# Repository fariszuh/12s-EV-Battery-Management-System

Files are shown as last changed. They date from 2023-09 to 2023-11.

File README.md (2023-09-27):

# 12s Battery Management System Research Project

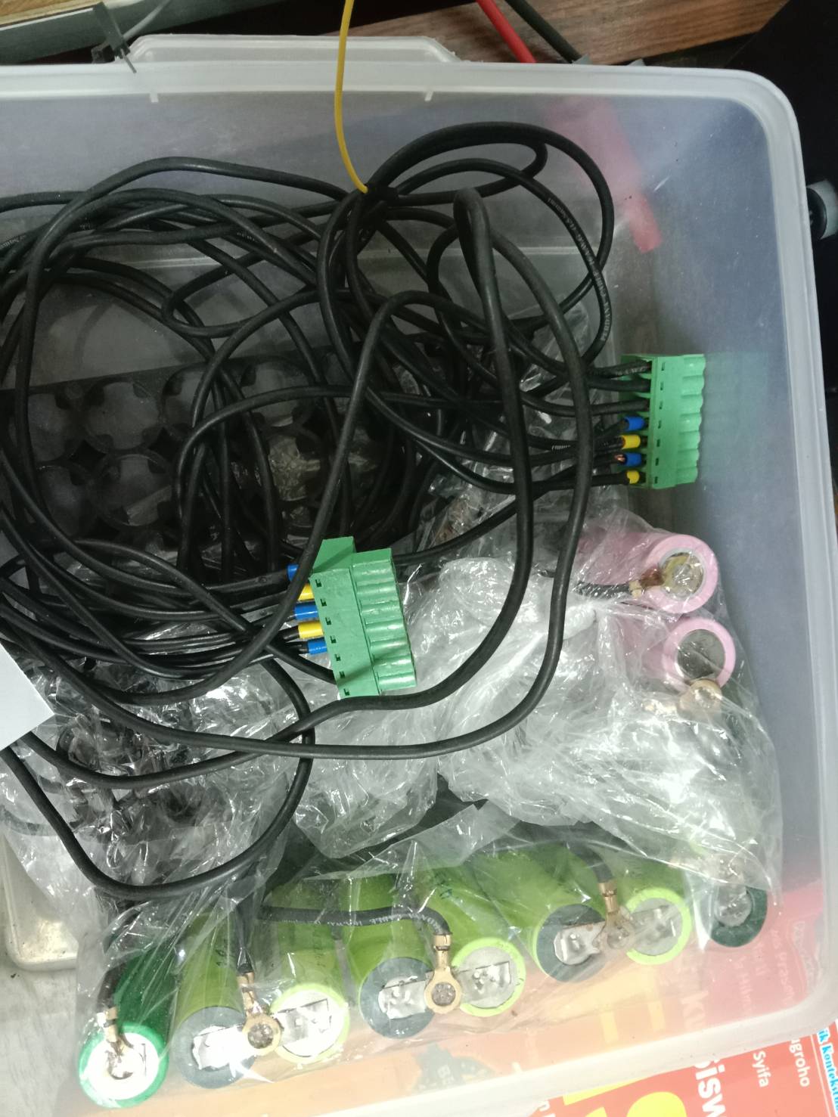
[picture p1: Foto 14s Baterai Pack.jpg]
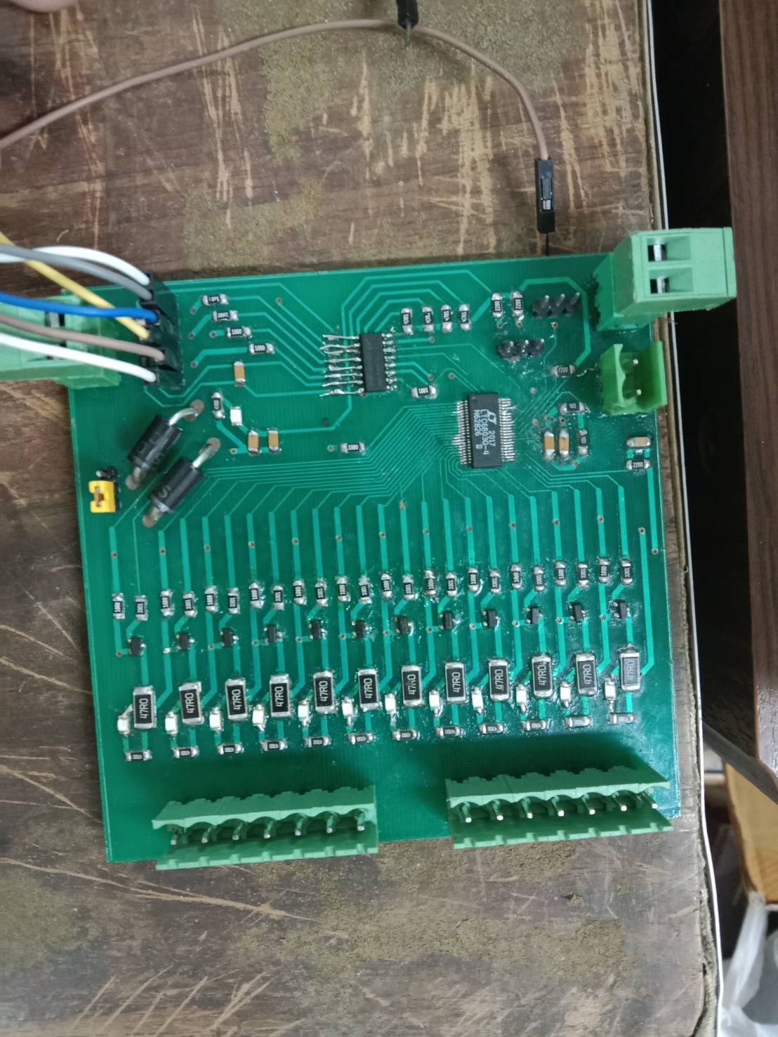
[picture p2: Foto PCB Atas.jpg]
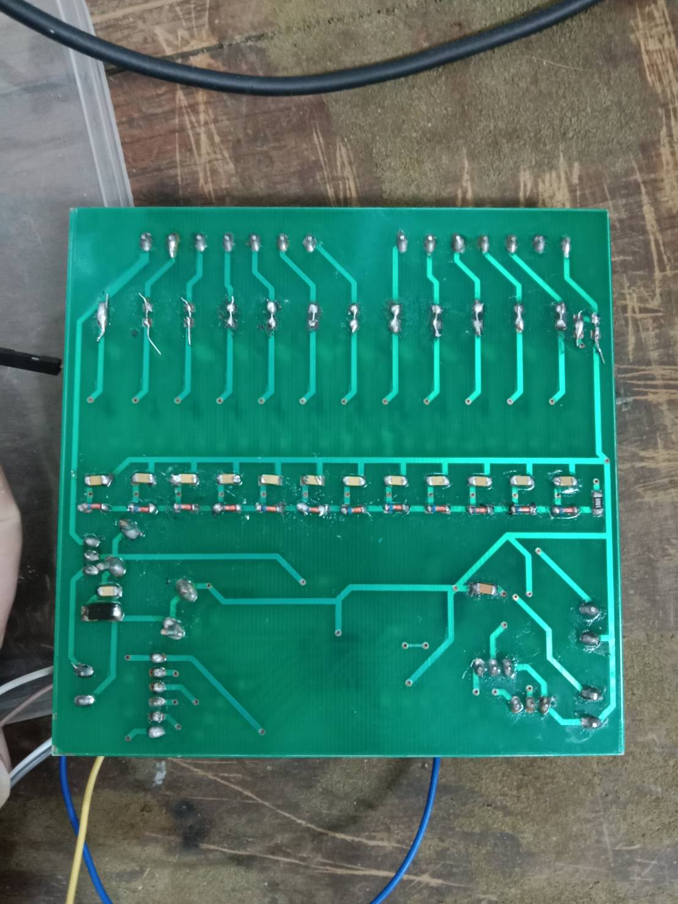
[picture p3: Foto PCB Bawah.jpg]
  

## Introduction
*This repo used to collaborative work on BMS project*
This project initiated by Anargya Third Generation Electric Manager Plan, Abyqa on 2021.
He suggested us (4th Electric Generation) to create our independent BMS. 
In the next year, 2022, We (Rafli as Electric Manager, Faris as Head of Low Voltage Subdiv., Lazu as Head of High Voltage Subdiv) proposed new design according to last Molina BMS.
The schematics design is located in /Single Board 12s directory. Note: use the latest version _v<number>.sch

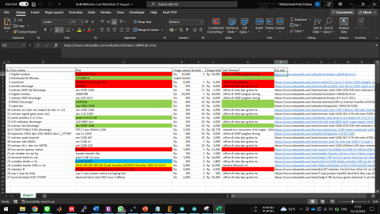
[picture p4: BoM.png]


## My Last Progress
Last progress was programming with Arduino UNO (Faris, Gagas). 
The code located inside /Code directory.

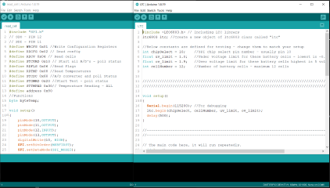
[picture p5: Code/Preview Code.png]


## Challenge
PCB had been assembly with the components, but the SPI communication to LTC's register still couldn't be read. 
This problem probably caused by thin route layer between component pin to LTC. You can re-route Eagle board file and print again.
Suggestion: use thicker path and more than 2 layer.

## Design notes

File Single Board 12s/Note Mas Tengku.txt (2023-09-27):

layer 1/top: S 
layer 2/green: V+ltc
layer 3/yellow: GND 0V
layer 4/bottom: C

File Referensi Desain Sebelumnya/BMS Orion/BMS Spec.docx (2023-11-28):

### 1.1.1 BMS Specifications

We are using a orion BMS made by Ewert Energy System, inc in USA. The main features of our BMS are:

1. Able to monitoring every cell voltage
2. Easily programmable and upgradeable on the field
3. Can enforce min. and max. cell voltages, max current limits, & temperature limits
4. Intelligently balancing each cell
5. Continously monitors state-of-charge and retains data about battery history
6. Integration with 3rd party smartphone apps (Torque, EngineLink)
7. Thermal Management & Voltage Protection
8. CANBUS Interfaces, OBD-II Support (support many scan tools) and Automotive Noise Immunity.

And for the safety of the Orion BMS are:

1. Isolation fault detection
2. Calculate the state of health, charge current limit, discharge current limit and Internal resistance of each cell
3. High immunity to EMI and other noise
4. High accuracy cell voltage measurement
5. On/Off outputs for controlling charge and discharge
6. 0-5V analog outputs for gradual current reduction (improves usable range of battery) and,
7. Thermal management controls for battery cooling/heating.

We using 1 BMS added with arduino uno to control and monitor voltage, current, state of health and temperature from 72 cell with 3.6 volt each cell and max. Voltage up to 260 volt. The Orion BMS will attach in the accumulator container and also added with (galvanic isolation between GLV and TS is we use Nomex paper at each end of connector to make sure the high voltage and low voltage doesn’t touch each other)(masih sama atau ngga?)

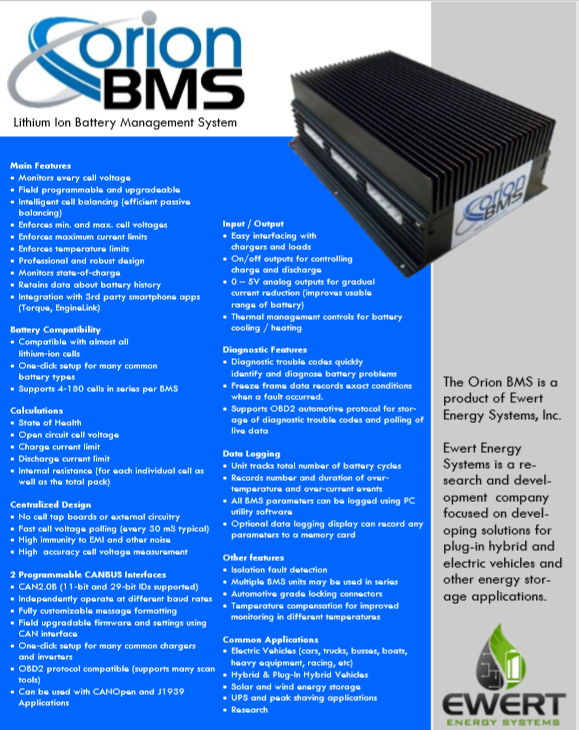
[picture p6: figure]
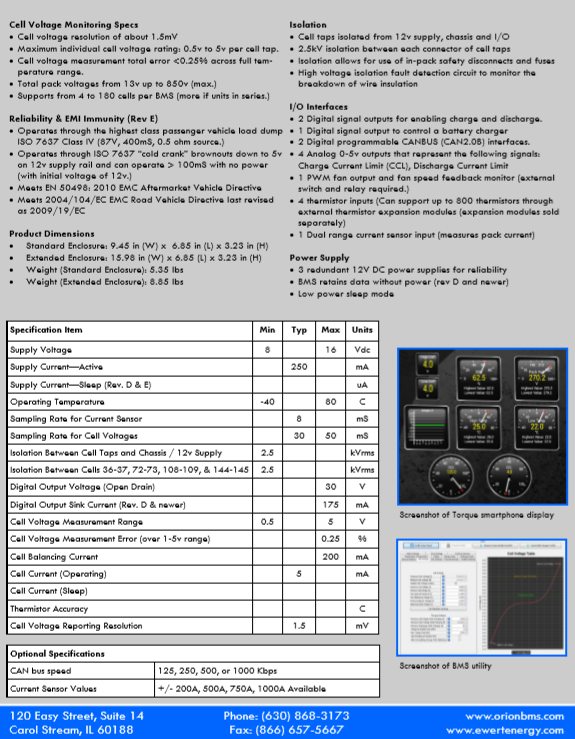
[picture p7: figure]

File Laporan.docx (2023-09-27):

RENEWABLE ENERGY

TRANSPORTATION – EV

BATTERY PACK – BMS

Terjadinya imbalance pada sel baterai merupakan hal yang umum terjadi dan dapat diakibatkan oleh sebab internal dan eksternal. Faktor internal meliputi variasi saat manufaktur, seperti volume bahan kimia baterai, internal impedance, dan laju self-discharge. Faktor eksternal dapat disebabkan oleh perbedaan suhu di dalam battery pack dan perbedaan laju

BMS

BATTERY PACK

METHOD BALANCING

CONSTRUCTION

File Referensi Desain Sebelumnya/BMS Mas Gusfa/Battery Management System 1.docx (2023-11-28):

## 1.1 Battery Management System (BMS)

### 1.1.1 Desain Battery Management System (BMS)

Perancangan desain PCB BMS menggunakan software Eagle 6.2.0. Sebelum melakukan desain PCB BMS secara keseluruhan, diperlukan schematic masing-masing modul pendukung dan melakukan pengujian pada modul tersebut. Hal ini dilakukan untuk mengurangi kegagalan PCB setelah dilakukan pencetakan. Selanjutnya, seluruh modul digambar jadi satu rangkaian. Berikut desain skematik BMSini :

#### 1.1.1.1 Modul Controller

Modul kontroler menggunakan mikrokontroler berbasis ARM dengan tipe STM32F405RGT6. Mikrokontroler ini dilengkapi dengan fitur Real Time Operating System (RT-OS) yang memungkinkan melakukan multi tasking dengan handing timer mencapai 168Mhz. STM32F405RGT6memiliki fitur yang sesuai dengan kebutuhan BMS ini. Berikut beberapa fitur yang dimiliki Mikrokontroler ini untuk menunjang fungsi BMS :

- Frekuensi kerja micro ini mencapai 168 Mhz sehingga sangat dimungkinkan untuk melakukan pengukuran dengan sample data yang cukup banyak. Selain itu, BMS akan semakin responsif dan akurat dalam melakukan balancing.
- Analog to Digital Converter (ADC) mencapai 12 bit, sehingga mampu melakukan pengukuran dengan resolusi yang sangat kecil.
- Dilengkapi 2 Peripheral CAN yang dapat digunakan sebagai protocol komunikasi antar device.
- Terdapat fasilitas peripheral SPI yang digunakan sebagai komunikasi dengan LTC6803-4.
- Terdapat fasilitas peripheral USART yang digunakan sebagai komunikasi dengan PC atau Laptop untuk keperluan user interface.

Skematik pada Gambar 7.13merupakan rangkaian komponen yang tersambung langsung pada pin utama Mikrokontroller STM32F405RGT6. Pada pin power supply, masing-masing disertai capacitor 100nF sebagai stabilisator tegangan sehingga Mikrokontroler dapat beroperasi dengan stabil. Berikut minimum system STM32F405RGT6 :

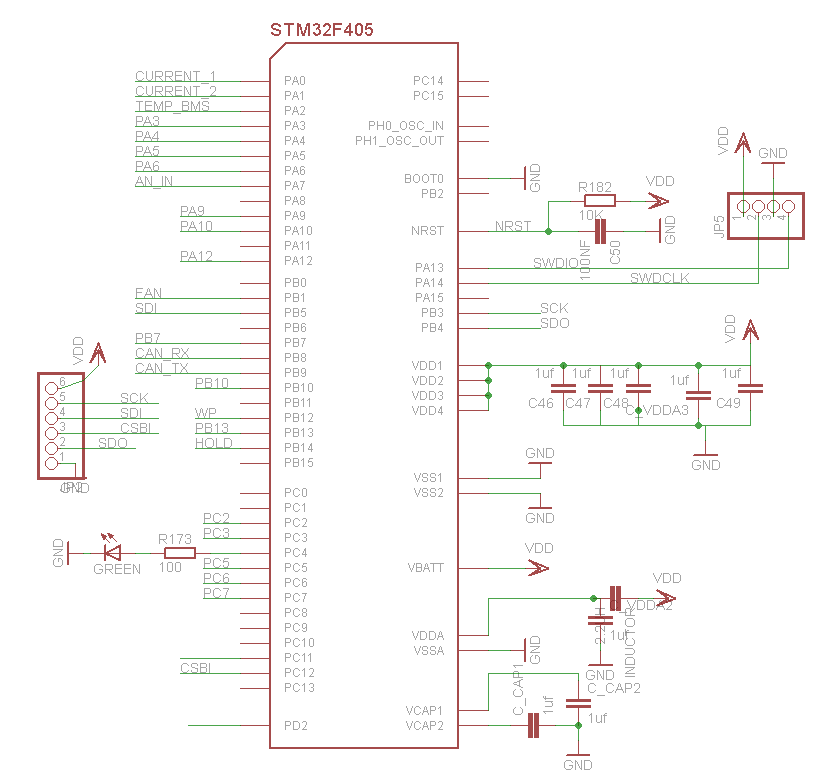
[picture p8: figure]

Gambar ‎7.13. Minimum System STM32F405RGT6

#### 1.1.1.2 Modul Voltage Regulator

Rangkaian voltage regulator ini berfungsi sebagai step down DC-DC Converter yaitu merubah tegangan input 7-36 Volt DC menjadi 5 volt DC. Voltage regulator yang digunakan adalah modul OKI-78SR. Sedangkan untuk mensuplai Mikrocontroler STM32F405RGT6 diperlukan tegangan dengan level 3.3 Volt, sehingga diperlukan Voltage Regulator dengan tipe LD1117DT33CTR. Kapasitor yang terpasang pada input dan output regulator digunakan sebagai stabilisator. Rangkaian voltage regulator ditunjukkan padaGambar 7.14.

Gambar ‎7.14. Voltage Regulator

#### 1.1.1.3 Modul Pengukur Tegangan per Cell

Tegangan per cell baterai dideteksi dengan metode Delta Sigma Analog to Digital Converter 12 bit. Masing-masing ground baterai terisolasi dengan prinsip Galvanic Isolation. Prinsip kerja Delta Sigma ADC adalah merubah data Analog tegangan cell menjadi data digital dengan referensi selisih tegangan per cell tersebut, sehingga akan diperoleh ketelitian yang sangat baik. Melalui prinsip ini tegangan yang terukur dapat memiliki ketelitian 3 angka dibelakang koma, lebih tepatnya memiliki ketelitian 1.5 mV dan 0.25% Total Error Measurement. BMS ini menggunakan IC LTC6803-4 untuk memonitoring tegangan baterai per cell. IC ini dapat digunakan untuk melakukan pengukuran tegangan 12 cell baterai dengan maksimal tegangan per cell 5V, sehingga dapat digunakan untuk aplikasi BMS Lithium Ion. IC ini juga dilengkapi dengan fasilitas Addressable Serial Interface sebanyak 4 bit (16 address). Sehingga sebanyak 16 IC dapat digunakan sekaligus untuk melakukan monitoring tegangan sebanyak 192 cell baterai. Berikut rangkaian LTC6803-4 :

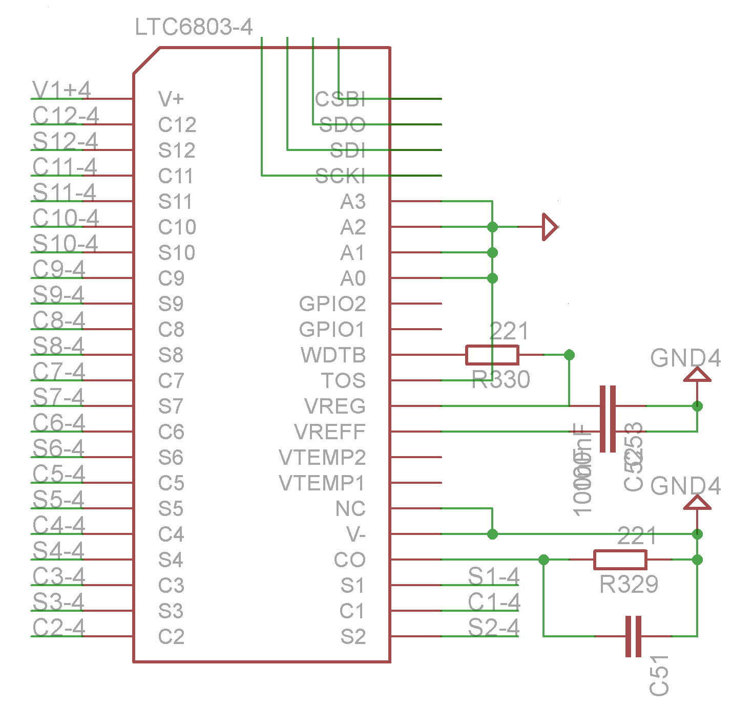
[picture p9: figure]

Gambar ‎7.15. Modul LTC Pengukur Tegangan per Cell

#### 1.1.1.4 Modul Balancing

BMS ini menggunakan Passive Balancing dengan switching Mosfet P channel berdasarkan tegangan per cell. Metode ini dipakai karena lebih simple apabila dibandingkan dengan Active Balancing. Skema passive balancing bms ini dapat dilihat pada gambar berikut :

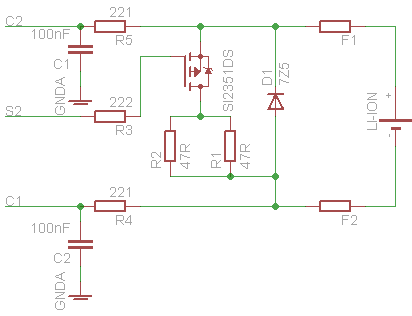
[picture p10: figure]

Gambar ‎7.16. Rangkaian cell passive balancing menggunakan MOSFET

Rangkaian tersebut merupakan rangkaian passive balancing untuk 1 cell baterai. F1 dan F2 merupakan fuse yang digunakan sebagai pengaman circuit, apabila terjadi kegagalan pada BMS tidak akan merusak baterai. D1 merupakan diode Zener 7.5 Volt, diode ini sebagai pengaman ADC pada LTC6803-4. Tegangan yang diizinkan masuk pada pin C1 maupun C2 maksimal adalah 7.5 Volt (meskipun input melebihi 7.5 Volt). Apabila terjadi kesalahan pemasangan wiring (misalkan menyebabkan delta cell voltage nya melebihi 7.5 Volt) tidak akan merusak LTC6803-4. R5, R4 dan C1, C2 merupakan RC Low Pass Filter yang berfungsi untuk memperkecil error pengukuran pada LTC6803-4. R1 dan R2 merupakan Resistor bypass yang berfungsi membuang kapasitas cell baterai yang berlebih dalam bentuk panas. MOSFET yang digunakan adalah Si2351DS, merupakan Mosfet P-Channel yang memiliki kemampuan switching hingga 2 A 20 volt (datasheet Si2351DS). MOSFET ini akan diaktifkan oleh LTC6803-4 sesuai perintah dari Mikrokontroler.

#### 1.1.1.5 Modul Opto Isolator

Opto Isolator digunakan untuk mengisolasi 2 level tegangan yang berbeda sehingga tidak saling terhubung namun dapat berinteraksi. Isolasi 2 level tegangan yang dimaksud adalah SCK, SDI, SDO dan CSBI antara Microcontroller dengan LTC. Digital Isolator yang digunakan adalah Si8441BB-D-IS1 yang terdiri dariQuad Channel Digital Isolator. Penggunaan Opto isolator ini sangat cocok karena sesuai dengan spesifikasi dimana isolator ini memiliki kecepatan operasi sebesar 150Mbps.

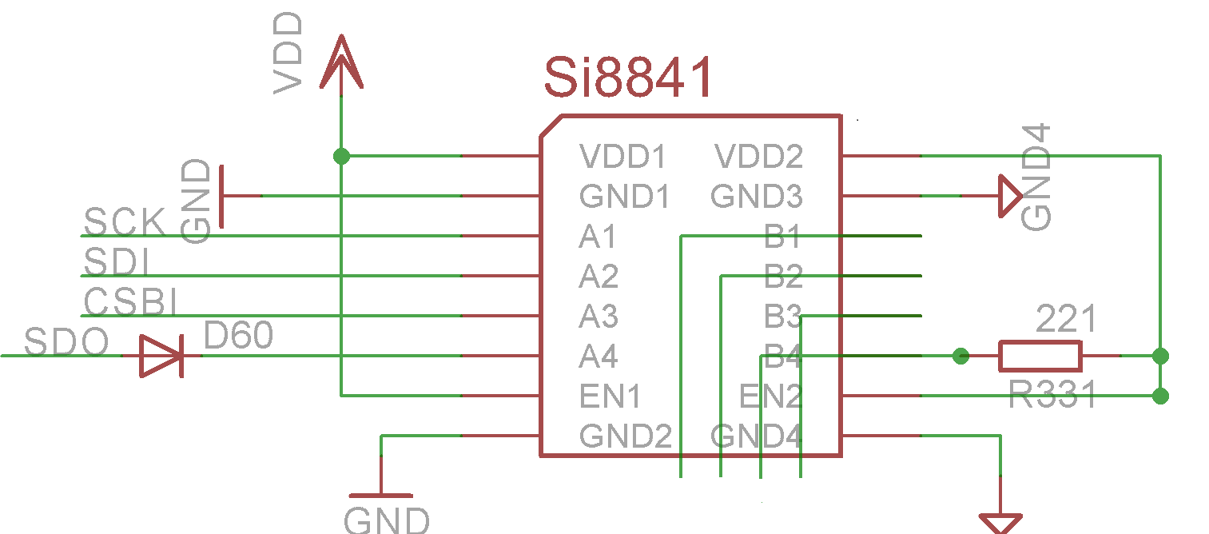
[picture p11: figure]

Gambar ‎7.17. Modul Opto Isolator

#### 1.1.1.6 Modul Pengukur Temperature

BMS ini menggunakan Thermistor NTC 100 K untuk mendeteksi temperatur baik boards BMS maupun baterai pack. Perubahan temperatur dapat dikonversi menjadi perubahan hambatan oleh thermistor ini. Data yang dimasukkan pada pin ADC mikrokontroler adalah data analog tegangan, sehingga nilai hambatan pada Thermistor perlu dirubah menjadi data tegangan dengan menggunakan Voltage Devider. Berikut rangkaian pengkondisian sinyal thermistor :

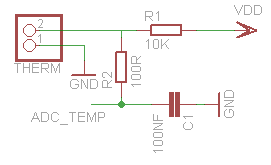
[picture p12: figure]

Gambar ‎7.18. Rangkaian pengkondisian sinyal thermistor

R1 merupakan hambatan senilai 10KΩ yang berfungsi sebagai pembagi tegangan terhadap hambatan thermistor. R2 bernilai 100Ω dan C1 bernilai 100nF merupakan rangkaian RC Low Pass Filter. Temperatur maksimum yang didesain pada BMS ini adalah 100oC sehingga BMS ini memiliki resolusi temperatur 1oC.

#### 1.1.1.7 Modul MRAM

Magneto Resistive Random Access Memory (MRAM) merupakan device penyimpanan menggunakan prinsip electromagnet sehingga memiliki fitur Unlimited Write dan Read Data. External memori ini digunakan untuk memfasilitasi fungsi perhitungan kapasitas baterai yang diharuskan mengakses memori setiap 100ms. Internal Flash Microcontroller hanya digunakan sebagai memory data static, STM32F4 dapat melakukan re-write Flash sebanyak 10.000-1jt kali sehingga diperlukan MRAM ini. MRAM yang digunakan adalah tipe MR25H256CDC. MRAM menggunakan komunikasi SPI dan pada desain BMS ini memakai SPI2 karena SPI1 sudah dipakai untuk LTC.

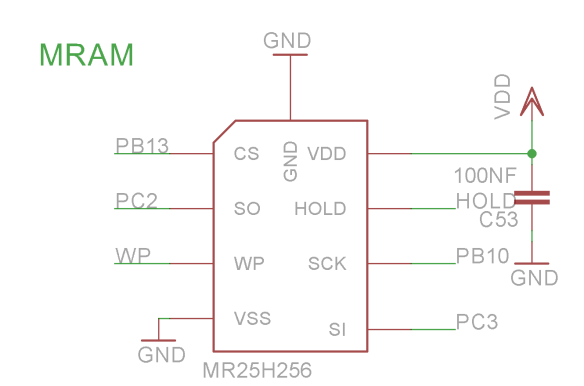
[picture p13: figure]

Gambar ‎7.19. Modul MRAM

#### 1.1.1.8 Modul Komunikasi CAN

BMS ini menggunakan komunikasi data CAN (Controller Area Network), yaitu komunikasi dengan topologi Bus. IC yang digunakan adalah SN65HVD230DR, komunikasi CAN merupakan standar otomotif yang memberikan fitur kecepatan pengiriman data hingga 1 Mbps dengan panjang jaringan hingga 50 m. Pada tahun 1993 Organisasi Internasional untuk Standardisasi merilis standar ISO 11898 yang kemudian direstrukturisasi menjadi dua bagian; ISO 11898-1 yang mencakup lapisan data link, dan ISO 11898-2 yang meliputi lapisan fisik untuk kecepatan tinggi. ISO 11898 - 3 dirilis kemudian yang mencakup lapisan fisik untuk kecepatan rendah. Perangkat yang terhubung dengan jaringan CAN biasanya sensor, aktuator, dan perangkat kontrol lainnya. Komunikasi ini dipakai karena data yang ditransfer lebih tahan terhadap noise. Data yang ditransfer akan direpresentasikan berupa nilai logik (0 dan 1) dimana kombinasi nilai logik ini dapat dibaca melalui differensial tegangan pada pin CAN High dan CAN Low. Selain itu, perbedaan tegangan pada pin CAN High dan CAN Low bisa lebih dari 5 volt sehingga lebih tahan terhadap noise. Berikut rangkaian CAN BMS ini :

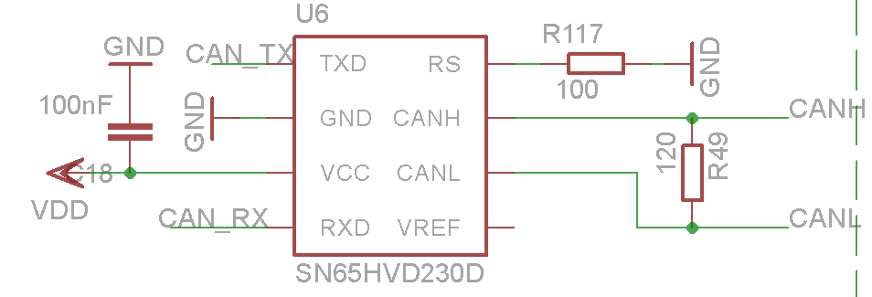
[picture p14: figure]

Gambar ‎7.20. Rangkaian CAN communication module

### 1.1.2 Desain Firmware

Firmware merupakan program dengan menggunakan bahasa C untuk dimasukkan pada Microcontroller. Sebelum membuat program, perlu dilakukan identifikasi peripheral-peripheral apa saja yang diperlukan dalam membuat BMS. BMS ini akan memerlukan peripheral sebagai berikut :

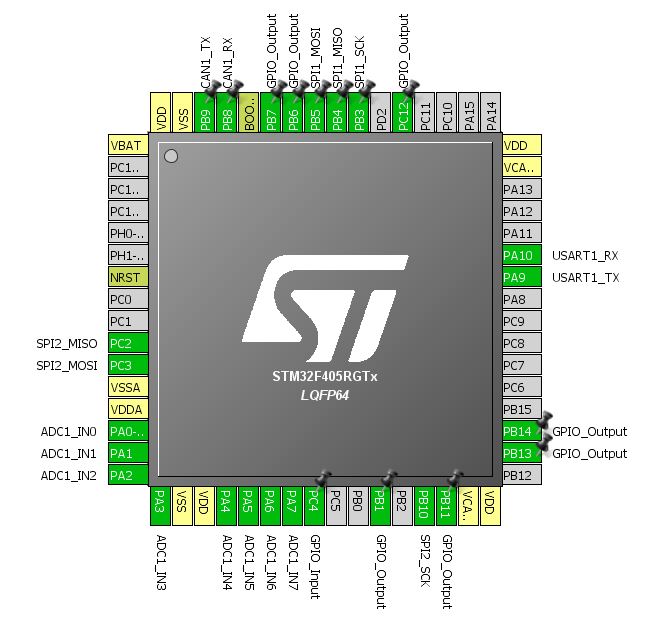
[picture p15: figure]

Gambar ‎7.22. Pin input dan output BMS

Peripheral STM32F405RGT6 yang digunakan untuk memfasilitasi seluruh fungsi dari BMS ini adalah :

#### 1.1.2.1 Serial Peripheral Interface (SPI)

SPI adalah salah satu protocol komunikasi serial shyncronous yang di-develop oleh Motorola. Dalam koneksi SPI, device yang terhubung satu sama lain akan bersifat Full Duplex, yaitu ada device yang bertindak sebagai Master dan Slave. Device yang menggunakan SPI dalam BMS ini adalah LTC6803-4 dan MRAM tipe MR25H256CDC sedangkan STM32F405RGT6 sebagai SPI Master. LTC6803-4 dihandle oleh SPI1 sedangkan MRAM dihandle oleh SPI2 dengan setting parameter sebagai berikut :

- CPHA = 1 dan CPOL = 1
- SPI data size 8 bit
- 1MHz Serial Interface (SPI_BaudRatePrescaler_64)
- Most Significant Bit (MSB) First
- SPI aktif ketika CSBI low

#### 1.1.2.2 Controller Area Network (CAN)

Peripheral CAN ini memiliki spesifikasi sebagai berikut :

- Extended CAN (CAN Specification 2.0 B) memiliki 29 bit identifier.
- CAN Mode Normal
- Kecepatan komunikasi CAN bus yang digunakan 500Kbps, sehingga konfigurasi pada STM32F405RGT6 adalah :

CAN_InitStructure.CAN_BS1 = CAN_BS1_8tq;

CAN_InitStructure.CAN_BS2 = CAN_BS2_5tq;

CAN_InitStructure.CAN_Prescaler = 6;

CAN_Init(CANx, &CAN_InitStructure);

- 1 ID memiliki 8 Byte data dan 1 byte terdiri dari 8 bit data, sehingga semua data dirubah menjadi data 8 bit. Contoh mengonversi data 16 bit menjadi 2 paket data masing-masing 8 bit :

uint8_t data1, data2; // tipe data 8 bit

uint16_t voltageLowest; // tipe data 16 bit

data1= voltageLowest>>8;

data2 = voltageLowest&0x00FF;

sedangkan untuk menggabungkan 2 data 8 bit menjadi data 16 bit adalah sebagai berikut :

uint8_t data1, data2;

uint16_t voltageLowest;

voltageLowest= (data1<<8)|(data2);

#### 1.1.2.3 Analog to Digital Converter (ADC)

ADC adalah pengubah input analog menjadi kode-kode digital. Data analog yang akan diproses pada Controller ini adalah output sensor arus, output signal conditioning sensor temperatur, output sensor tegangan. STM32F405RGT6 memiliki keunggulan yaitu ADC 12 bit data, sehingga memiliki resolusi pengukuran yang baik dibandingkan dengan microcontroller lain. Selain itu ADC juga dapat menggunakan Direct Memory Access (DMA) sehingga memungkinkan pengambilan sample data secara optimal. BMS ini menggunakan sample data ADC sebanyak 300 data ADC setiap 1 ms dan data tersebut diakses setiap 100ms untuk dilakukan perhitungan Coulomb. Data setiap 1 ms tersebut diakumulasikan selama 100ms kemudian dihitung rata-rata ADC tersebut. Hasil rata-rata data ADC tersebut yang digunakan sebagai perhitungan Coulomb. Sehingga data ADC yang digunakan memiliki nilai yang tepat. Untuk menghandle proses perhitungan setiap 100ms digunakan Timer 2. Konversi nilai Digital yang diperoleh akan merepresentasikan kondisi fisik yang disensor.

#### 1.1.2.4 Universal Synchronous Asynchronous Receiver Transmitter (USART)

USART digunakan untuk komunikasi data antara STM32F405RGT6 dengan Komputer, sehingga Komputer dapat menampilkan kondisi data BMS. BMS hasil inovasi ini menggunakan peripheral USART1 pada STM32F405RGT6, dimana memiliki konfigurasi sebagai berikut :

- Baudrate 115200
- Data bit sebesar 8 bit dengan no Parity
- Stop bit 1

Komunikasi bersifat dua arah dimana Microcontroller akan memberikan respond berupa pengiriman data sesuai dengan permintaan interface computer.

Untuk mengaktifkan peripheral USART1 dengan konfigurasi seperti diatas maka diperlukan program bahasa C sesuai pada lampiran. USART tidak dipakai sebagai komunikasi data utama karena ketahanan terhadap interferensi masih sangat buruk, selain itu bentuk komunikasi tidak memungkinkan untuk multidevice.

#### 1.1.2.5 General Purpose Input Output (GPIO)

Pemilihan pin STM32 untuk keperluan Digital Input dan Digital Output dilakukan setelah semua peripheral yang diperlukan terpenuhi. Pada dasarnya seluruh pin yang ada pada STM32 ini dapat dijadikan sebagai Pin Input maupun pin Output, sehingga memiliki fleksibilitas yang tinggi dan prioritas yang dapat menyesuaikan kondisi. Beberapa keperluan untuk digital output adalah Indikator LED, CSBI untuk SPI.

#### 1.1.2.6 TIM2, TIM3 dan TIM5

TIM2 digunakan untuk meng-handle perhitungan Coulomb dimana akan aktif setiap 1 ms, sedangkan fungsi tersebut akan dieksekusi setiap 100 ms sekali. TIM3 digunakan untuk menghandle status charger, dimana status charger akan diupdate setiap 1 ms. Sedangkan apabila yang connect charger dengan fitur CAN maka dihandle oleh TIM5. Apabila terdapat message dari charger melalui CAN maka board Master akan merespon dengan mengirimkan arus charger maksimal dan tegangan total maksimal pada baterai pack yang diizinkan. Berikut cuplikan program tersebut :

…………………………..

MAX_AMP_CHARGING_ALLOWANCE=(uint16_t)(MaxCurrent/10);

send_charger_command(MAX_VOLT_CHARGING_ALLOWANCE,MAX_AMP_CHARGING_ALLOWANCE, flagChargingPermitted);

……………………………

dimana fungsi send_charger_command sebagai berikut :

…………………….

void send_charger_command(uint16_t volt, uint16_t amp, bool control)

{

TxMessageE5.Data[0] = volt >> 8; // mengirim message tegangan maksimum

TxMessageE5.Data[1] = volt & 0xFF; // mengirim message tegangan maksimum

TxMessageE5.Data[2] = amp >> 8; // mengirim message arus maksimum

TxMessageE5.Data[3] = amp & 0xFF; // mengirim message arus maksimum

TxMessageE5.Data[4] = control; // mengirim status charger

CAN_Transmit(CANx, &TxMessageE5);

}

…………………….

### 1.1.3 Desain Software Interface

Software interface untuk monitoring BMS dikembangkan menggunakan Qt Creator, salah satu software IDE (Integrated Development Environment) untuk mengembangkan aplikasi desktop berbasis bahasa C/C++.Fitur-fitur yang ada pada monitoring display untuk BMS adalah, tegangan setiap sel baterai, kapasits, arus, dan temperatur. Sebagaimana yang ditunjukkan oleh Gambar 7.23.

Data dari BMS dikirim menggunakan komunikasi CAN BUS, dengan baudrate sebesar 500 kHz. Data dikirim secara periodik setiap 300 ms. Untuk membantu sistem monitoring berkomunikasi dengan BMS, diperlukan sebuah alat interface USB-to-CAN.

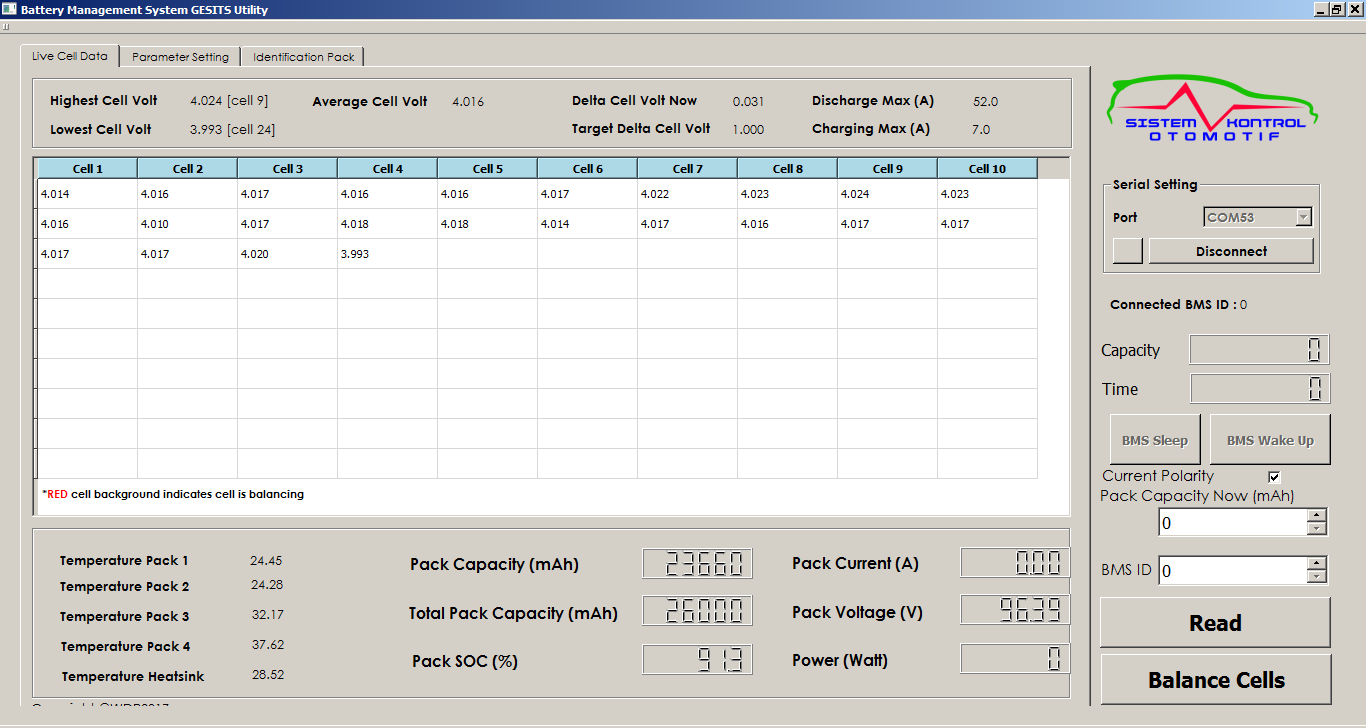
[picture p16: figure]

Gambar ‎7.23. Tampilan software monitoring BMS

### 1.1.4 Prototyping Battery Management System

Produksi hardware BMS dilakukan 2 (dua) tahap, secara otomatis dan manual. Produksi otomatis menggunakan mesin PCB Assembly. Hal ini dilakukan untuk pemasangan komponen-komponen pasif, IC serta mikrokontroller. Sedangkan untuk proses yang manual adalah menggunakan solder secara manual yang dilakukan oleh tim BMS. Proses manual ini dilakukan untuk pemasangan modul regulator, karena pada mesin assembly tidak tersedia slot untuk modul yang digunakan. Selain itu, dilakukan pemasangan kabel dan soket secara manual, serta dilakukan pengecekan pada komponen-komponen yang telah terpasang menggunakan mesin assembly apakah terdapat komponen yang tidak terpasang dengan baik, seperti kurangnya timah pada kaki komponen atau komponen yang tidak tepat pada pad yang disediakan. Gambar ‎7.24 dan Gambar ‎7.25 merupakan gambar proses roduksi menggunakan mesin assembly dan manual.

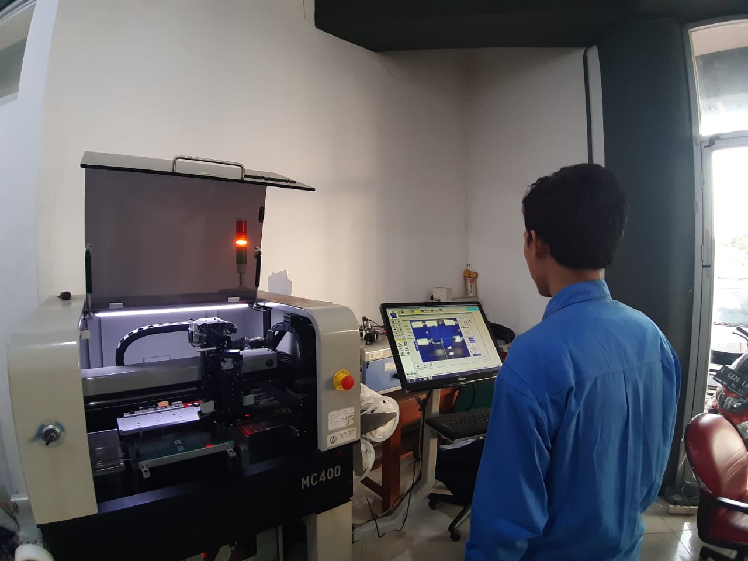
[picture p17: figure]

Gambar ‎7.24. Proses produksi modul BMS menggunakan mesin PCB Assembly

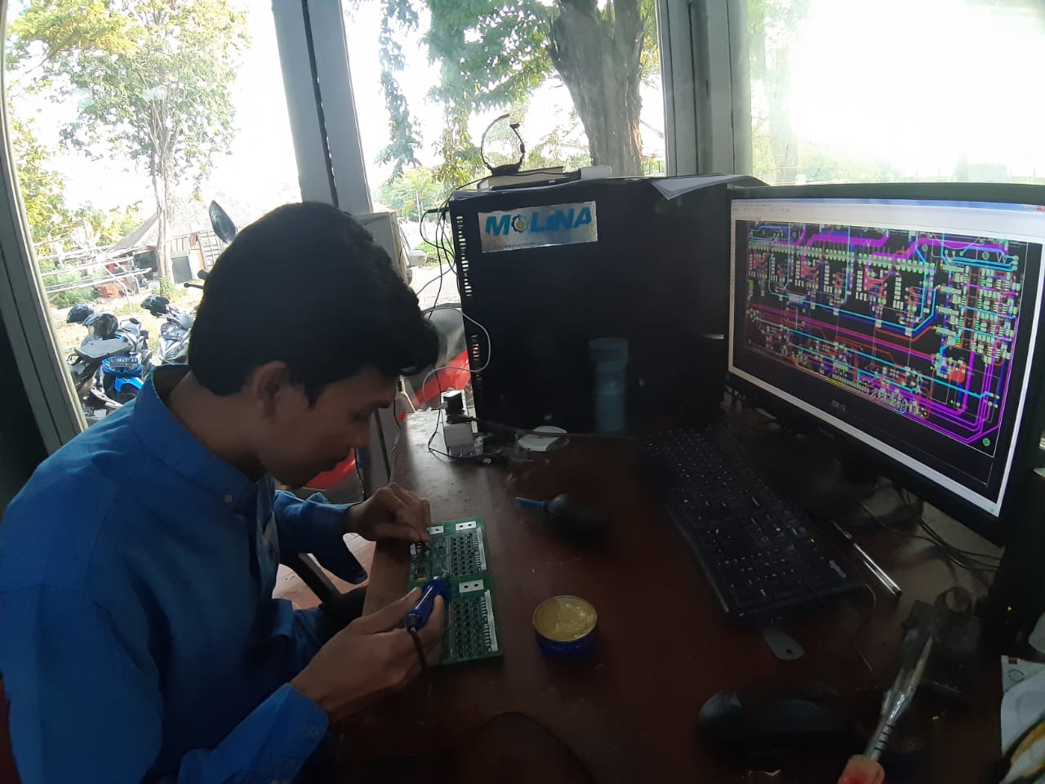
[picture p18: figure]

Gambar ‎7.25. Proses produksi modul BMS secara manual

Modul BMS mempunyai dimensi sebesar 132 x 100 mm, didesain sedemikian rupa sehingga menjadi sangat mudah dikemas dan sangat fleksibel dengan penempatan pada baterai pack dengan tidak mengurangi fungsi dan fitur dari BMS itu sendiri.

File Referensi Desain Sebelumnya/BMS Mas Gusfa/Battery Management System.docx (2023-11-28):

## 1.1 Battery Management System (BMS)

### 1.1.1 Desain Battery Management System (BMS)

Perancangan desain PCB BMS menggunakan software Eagle 6.2.0. Sebelum melakukan desain PCB BMS secara keseluruhan, diperlukan schematic masing-masing modul pendukung dan melakukan pengujian pada modul tersebut. Hal ini dilakukan untuk mengurangi kegagalan PCB setelah dilakukan pencetakan. Selanjutnya, seluruh modul digambar jadi satu rangkaian. Berikut desain skematik BMSini :

#### 1.1.1.1 Modul Controller

Modul kontroler menggunakan mikrokontroler berbasis ARM dengan tipe STM32F405RGT6. Mikrokontroler ini dilengkapi dengan fitur Real Time Operating System (RT-OS) yang memungkinkan melakukan multi tasking dengan handing timer mencapai 168Mhz. STM32F405RGT6memiliki fitur yang sesuai dengan kebutuhan BMS ini. Berikut beberapa fitur yang dimiliki Mikrokontroler ini untuk menunjang fungsi BMS :

- Frekuensi kerja micro ini mencapai 168 Mhz sehingga sangat dimungkinkan untuk melakukan pengukuran dengan sample data yang cukup banyak. Selain itu, BMS akan semakin responsif dan akurat dalam melakukan balancing.
- Analog to Digital Converter (ADC) mencapai 12 bit, sehingga mampu melakukan pengukuran dengan resolusi yang sangat kecil.
- Dilengkapi 2 Peripheral CAN yang dapat digunakan sebagai protocol komunikasi antar device.
- Terdapat fasilitas peripheral SPI yang digunakan sebagai komunikasi dengan LTC6803-4.
- Terdapat fasilitas peripheral USART yang digunakan sebagai komunikasi dengan PC atau Laptop untuk keperluan user interface.

Skematik pada Gambar 7.13merupakan rangkaian komponen yang tersambung langsung pada pin utama Mikrokontroller STM32F405RGT6. Pada pin power supply, masing-masing disertai capacitor 100nF sebagai stabilisator tegangan sehingga Mikrokontroler dapat beroperasi dengan stabil. Berikut minimum system STM32F405RGT6 :


Gambar ‎7.13. Minimum System STM32F405RGT6

#### 1.1.1.2 Modul Voltage Regulator

Rangkaian voltage regulator ini berfungsi sebagai step down DC-DC Converter yaitu merubah tegangan input 7-36 Volt DC menjadi 5 volt DC. Voltage regulator yang digunakan adalah modul OKI-78SR. Sedangkan untuk mensuplai Mikrocontroler STM32F405RGT6 diperlukan tegangan dengan level 3.3 Volt, sehingga diperlukan Voltage Regulator dengan tipe LD1117DT33CTR. Kapasitor yang terpasang pada input dan output regulator digunakan sebagai stabilisator. Rangkaian voltage regulator ditunjukkan padaGambar 7.14.

Gambar ‎7.14. Voltage Regulator

#### 1.1.1.3 Modul Pengukur Tegangan per Cell

Tegangan per cell baterai dideteksi dengan metode Delta Sigma Analog to Digital Converter 12 bit. Masing-masing ground baterai terisolasi dengan prinsip Galvanic Isolation. Prinsip kerja Delta Sigma ADC adalah merubah data Analog tegangan cell menjadi data digital dengan referensi selisih tegangan per cell tersebut, sehingga akan diperoleh ketelitian yang sangat baik. Melalui prinsip ini tegangan yang terukur dapat memiliki ketelitian 3 angka dibelakang koma, lebih tepatnya memiliki ketelitian 1.5 mV dan 0.25% Total Error Measurement. BMS ini menggunakan IC LTC6803-4 untuk memonitoring tegangan baterai per cell. IC ini dapat digunakan untuk melakukan pengukuran tegangan 12 cell baterai dengan maksimal tegangan per cell 5V, sehingga dapat digunakan untuk aplikasi BMS Lithium Ion. IC ini juga dilengkapi dengan fasilitas Addressable Serial Interface sebanyak 4 bit (16 address). Sehingga sebanyak 16 IC dapat digunakan sekaligus untuk melakukan monitoring tegangan sebanyak 192 cell baterai. Berikut rangkaian LTC6803-4 :


Gambar ‎7.15. Modul LTC Pengukur Tegangan per Cell

#### 1.1.1.4 Modul Balancing

BMS ini menggunakan Passive Balancing dengan switching Mosfet P channel berdasarkan tegangan per cell. Metode ini dipakai karena lebih simple apabila dibandingkan dengan Active Balancing. Skema passive balancing bms ini dapat dilihat pada gambar berikut :


Gambar ‎7.16. Rangkaian cell passive balancing menggunakan MOSFET

Rangkaian tersebut merupakan rangkaian passive balancing untuk 1 cell baterai. F1 dan F2 merupakan fuse yang digunakan sebagai pengaman circuit, apabila terjadi kegagalan pada BMS tidak akan merusak baterai. D1 merupakan diode Zener 7.5 Volt, diode ini sebagai pengaman ADC pada LTC6803-4. Tegangan yang diizinkan masuk pada pin C1 maupun C2 maksimal adalah 7.5 Volt (meskipun input melebihi 7.5 Volt). Apabila terjadi kesalahan pemasangan wiring (misalkan menyebabkan delta cell voltage nya melebihi 7.5 Volt) tidak akan merusak LTC6803-4. R5, R4 dan C1, C2 merupakan RC Low Pass Filter yang berfungsi untuk memperkecil error pengukuran pada LTC6803-4. R1 dan R2 merupakan Resistor bypass yang berfungsi membuang kapasitas cell baterai yang berlebih dalam bentuk panas. MOSFET yang digunakan adalah Si2351DS, merupakan Mosfet P-Channel yang memiliki kemampuan switching hingga 2 A 20 volt (datasheet Si2351DS). MOSFET ini akan diaktifkan oleh LTC6803-4 sesuai perintah dari Mikrokontroler.

#### 1.1.1.5 Modul Opto Isolator

Opto Isolator digunakan untuk mengisolasi 2 level tegangan yang berbeda sehingga tidak saling terhubung namun dapat berinteraksi. Isolasi 2 level tegangan yang dimaksud adalah SCK, SDI, SDO dan CSBI antara Microcontroller dengan LTC. Digital Isolator yang digunakan adalah Si8441BB-D-IS1 yang terdiri dariQuad Channel Digital Isolator. Penggunaan Opto isolator ini sangat cocok karena sesuai dengan spesifikasi dimana isolator ini memiliki kecepatan operasi sebesar 150Mbps.


Gambar ‎7.17. Modul Opto Isolator

#### 1.1.1.6 Modul Pengukur Temperature

BMS ini menggunakan Thermistor NTC 100 K untuk mendeteksi temperatur baik boards BMS maupun baterai pack. Perubahan temperatur dapat dikonversi menjadi perubahan hambatan oleh thermistor ini. Data yang dimasukkan pada pin ADC mikrokontroler adalah data analog tegangan, sehingga nilai hambatan pada Thermistor perlu dirubah menjadi data tegangan dengan menggunakan Voltage Devider. Berikut rangkaian pengkondisian sinyal thermistor :


Gambar ‎7.18. Rangkaian pengkondisian sinyal thermistor

R1 merupakan hambatan senilai 10KΩ yang berfungsi sebagai pembagi tegangan terhadap hambatan thermistor. R2 bernilai 100Ω dan C1 bernilai 100nF merupakan rangkaian RC Low Pass Filter. Temperatur maksimum yang didesain pada BMS ini adalah 100oC sehingga BMS ini memiliki resolusi temperatur 1oC.

#### 1.1.1.7 Modul MRAM

Magneto Resistive Random Access Memory (MRAM) merupakan device penyimpanan menggunakan prinsip electromagnet sehingga memiliki fitur Unlimited Write dan Read Data. External memori ini digunakan untuk memfasilitasi fungsi perhitungan kapasitas baterai yang diharuskan mengakses memori setiap 100ms. Internal Flash Microcontroller hanya digunakan sebagai memory data static, STM32F4 dapat melakukan re-write Flash sebanyak 10.000-1jt kali sehingga diperlukan MRAM ini. MRAM yang digunakan adalah tipe MR25H256CDC. MRAM menggunakan komunikasi SPI dan pada desain BMS ini memakai SPI2 karena SPI1 sudah dipakai untuk LTC.


Gambar ‎7.19. Modul MRAM

#### 1.1.1.8 Modul Komunikasi CAN

BMS ini menggunakan komunikasi data CAN (Controller Area Network), yaitu komunikasi dengan topologi Bus. IC yang digunakan adalah SN65HVD230DR, komunikasi CAN merupakan standar otomotif yang memberikan fitur kecepatan pengiriman data hingga 1 Mbps dengan panjang jaringan hingga 50 m. Pada tahun 1993 Organisasi Internasional untuk Standardisasi merilis standar ISO 11898 yang kemudian direstrukturisasi menjadi dua bagian; ISO 11898-1 yang mencakup lapisan data link, dan ISO 11898-2 yang meliputi lapisan fisik untuk kecepatan tinggi. ISO 11898 - 3 dirilis kemudian yang mencakup lapisan fisik untuk kecepatan rendah. Perangkat yang terhubung dengan jaringan CAN biasanya sensor, aktuator, dan perangkat kontrol lainnya. Komunikasi ini dipakai karena data yang ditransfer lebih tahan terhadap noise. Data yang ditransfer akan direpresentasikan berupa nilai logik (0 dan 1) dimana kombinasi nilai logik ini dapat dibaca melalui differensial tegangan pada pin CAN High dan CAN Low. Selain itu, perbedaan tegangan pada pin CAN High dan CAN Low bisa lebih dari 5 volt sehingga lebih tahan terhadap noise. Berikut rangkaian CAN BMS ini :


Gambar ‎7.20. Rangkaian CAN communication module

Gambar 7.21 merupakan bentuk rangkaian board dari PCB untuk BMS.

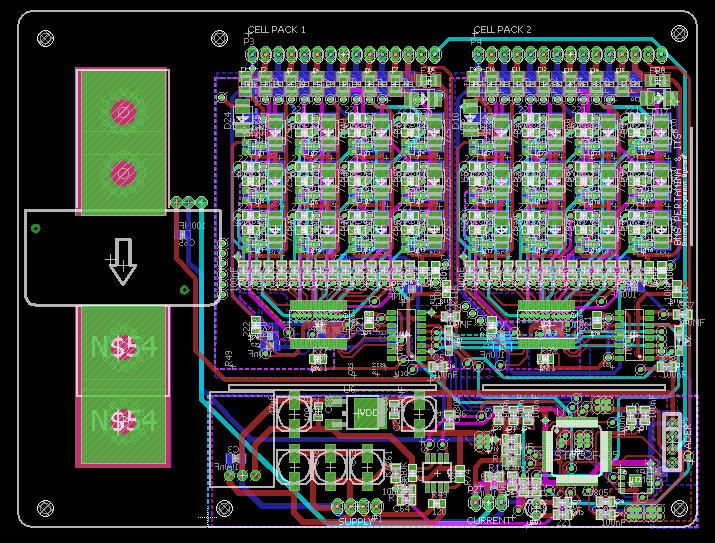
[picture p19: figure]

Gambar ‎7.21. Board PCB dari BMS

### 1.1.2 Desain Firmware

Firmware merupakan program dengan menggunakan bahasa C untuk dimasukkan pada Microcontroller. Sebelum membuat program, perlu dilakukan identifikasi peripheral-peripheral apa saja yang diperlukan dalam membuat BMS. BMS ini akan memerlukan peripheral sebagai berikut :


Gambar ‎7.22. Pin input dan output BMS

Peripheral STM32F405RGT6 yang digunakan untuk memfasilitasi seluruh fungsi dari BMS ini adalah :

#### 1.1.2.1 Serial Peripheral Interface (SPI)

SPI adalah salah satu protocol komunikasi serial shyncronous yang di-develop oleh Motorola. Dalam koneksi SPI, device yang terhubung satu sama lain akan bersifat Full Duplex, yaitu ada device yang bertindak sebagai Master dan Slave. Device yang menggunakan SPI dalam BMS ini adalah LTC6803-4 dan MRAM tipe MR25H256CDC sedangkan STM32F405RGT6 sebagai SPI Master. LTC6803-4 dihandle oleh SPI1 sedangkan MRAM dihandle oleh SPI2 dengan setting parameter sebagai berikut :

- CPHA = 1 dan CPOL = 1
- SPI data size 8 bit
- 1MHz Serial Interface (SPI_BaudRatePrescaler_64)
- Most Significant Bit (MSB) First
- SPI aktif ketika CSBI low

#### 1.1.2.2 Controller Area Network (CAN)

Peripheral CAN ini memiliki spesifikasi sebagai berikut :

- Extended CAN (CAN Specification 2.0 B) memiliki 29 bit identifier.
- CAN Mode Normal
- Kecepatan komunikasi CAN bus yang digunakan 500Kbps, sehingga konfigurasi pada STM32F405RGT6 adalah :

CAN_InitStructure.CAN_BS1 = CAN_BS1_8tq;

CAN_InitStructure.CAN_BS2 = CAN_BS2_5tq;

CAN_InitStructure.CAN_Prescaler = 6;

CAN_Init(CANx, &CAN_InitStructure);

- 1 ID memiliki 8 Byte data dan 1 byte terdiri dari 8 bit data, sehingga semua data dirubah menjadi data 8 bit. Contoh mengonversi data 16 bit menjadi 2 paket data masing-masing 8 bit :

uint8_t data1, data2; // tipe data 8 bit

uint16_t voltageLowest; // tipe data 16 bit

data1= voltageLowest>>8;

data2 = voltageLowest&0x00FF;

sedangkan untuk menggabungkan 2 data 8 bit menjadi data 16 bit adalah sebagai berikut :

uint8_t data1, data2;

uint16_t voltageLowest;

voltageLowest= (data1<<8)|(data2);

#### 1.1.2.3 Analog to Digital Converter (ADC)

ADC adalah pengubah input analog menjadi kode-kode digital. Data analog yang akan diproses pada Controller ini adalah output sensor arus, output signal conditioning sensor temperatur, output sensor tegangan. STM32F405RGT6 memiliki keunggulan yaitu ADC 12 bit data, sehingga memiliki resolusi pengukuran yang baik dibandingkan dengan microcontroller lain. Selain itu ADC juga dapat menggunakan Direct Memory Access (DMA) sehingga memungkinkan pengambilan sample data secara optimal. BMS ini menggunakan sample data ADC sebanyak 300 data ADC setiap 1 ms dan data tersebut diakses setiap 100ms untuk dilakukan perhitungan Coulomb. Data setiap 1 ms tersebut diakumulasikan selama 100ms kemudian dihitung rata-rata ADC tersebut. Hasil rata-rata data ADC tersebut yang digunakan sebagai perhitungan Coulomb. Sehingga data ADC yang digunakan memiliki nilai yang tepat. Untuk menghandle proses perhitungan setiap 100ms digunakan Timer 2. Konversi nilai Digital yang diperoleh akan merepresentasikan kondisi fisik yang disensor.

#### 1.1.2.4 Universal Synchronous Asynchronous Receiver Transmitter (USART)

USART digunakan untuk komunikasi data antara STM32F405RGT6 dengan Komputer, sehingga Komputer dapat menampilkan kondisi data BMS. BMS hasil inovasi ini menggunakan peripheral USART1 pada STM32F405RGT6, dimana memiliki konfigurasi sebagai berikut :

- Baudrate 115200
- Data bit sebesar 8 bit dengan no Parity
- Stop bit 1

Komunikasi bersifat dua arah dimana Microcontroller akan memberikan respond berupa pengiriman data sesuai dengan permintaan interface computer.

Untuk mengaktifkan peripheral USART1 dengan konfigurasi seperti diatas maka diperlukan program bahasa C sesuai pada lampiran. USART tidak dipakai sebagai komunikasi data utama karena ketahanan terhadap interferensi masih sangat buruk, selain itu bentuk komunikasi tidak memungkinkan untuk multidevice.

#### 1.1.2.5 General Purpose Input Output (GPIO)

Pemilihan pin STM32 untuk keperluan Digital Input dan Digital Output dilakukan setelah semua peripheral yang diperlukan terpenuhi. Pada dasarnya seluruh pin yang ada pada STM32 ini dapat dijadikan sebagai Pin Input maupun pin Output, sehingga memiliki fleksibilitas yang tinggi dan prioritas yang dapat menyesuaikan kondisi. Beberapa keperluan untuk digital output adalah Indikator LED, CSBI untuk SPI.

#### 1.1.2.6 TIM2, TIM3 dan TIM5

TIM2 digunakan untuk meng-handle perhitungan Coulomb dimana akan aktif setiap 1 ms, sedangkan fungsi tersebut akan dieksekusi setiap 100 ms sekali. TIM3 digunakan untuk menghandle status charger, dimana status charger akan diupdate setiap 1 ms. Sedangkan apabila yang connect charger dengan fitur CAN maka dihandle oleh TIM5. Apabila terdapat message dari charger melalui CAN maka board Master akan merespon dengan mengirimkan arus charger maksimal dan tegangan total maksimal pada baterai pack yang diizinkan. Berikut cuplikan program tersebut :

…………………………..

MAX_AMP_CHARGING_ALLOWANCE=(uint16_t)(MaxCurrent/10);

send_charger_command(MAX_VOLT_CHARGING_ALLOWANCE,MAX_AMP_CHARGING_ALLOWANCE, flagChargingPermitted);

……………………………

dimana fungsi send_charger_command sebagai berikut :

…………………….

void send_charger_command(uint16_t volt, uint16_t amp, bool control)

{

TxMessageE5.Data[0] = volt >> 8; // mengirim message tegangan maksimum

TxMessageE5.Data[1] = volt & 0xFF; // mengirim message tegangan maksimum

TxMessageE5.Data[2] = amp >> 8; // mengirim message arus maksimum

TxMessageE5.Data[3] = amp & 0xFF; // mengirim message arus maksimum

TxMessageE5.Data[4] = control; // mengirim status charger

CAN_Transmit(CANx, &TxMessageE5);

}

…………………….

### 1.1.3 Desain Software Interface

Software interface untuk monitoring BMS dikembangkan menggunakan Qt Creator, salah satu software IDE (Integrated Development Environment) untuk mengembangkan aplikasi desktop berbasis bahasa C/C++.Fitur-fitur yang ada pada monitoring display untuk BMS adalah, tegangan setiap sel baterai, kapasits, arus, dan temperatur. Sebagaimana yang ditunjukkan oleh Gambar 7.23.

Data dari BMS dikirim menggunakan komunikasi CAN BUS, dengan baudrate sebesar 500 kHz. Data dikirim secara periodik setiap 300 ms. Untuk membantu sistem monitoring berkomunikasi dengan BMS, diperlukan sebuah alat interface USB-to-CAN.


Gambar ‎7.23. Tampilan software monitoring BMS

### 1.1.4 Prototyping Battery Management System

Produksi hardware BMS dilakukan 2 (dua) tahap, secara otomatis dan manual. Produksi otomatis menggunakan mesin PCB Assembly. Hal ini dilakukan untuk pemasangan komponen-komponen pasif, IC serta mikrokontroller. Sedangkan untuk proses yang manual adalah menggunakan solder secara manual yang dilakukan oleh tim BMS. Proses manual ini dilakukan untuk pemasangan modul regulator, karena pada mesin assembly tidak tersedia slot untuk modul yang digunakan. Selain itu, dilakukan pemasangan kabel dan soket secara manual, serta dilakukan pengecekan pada komponen-komponen yang telah terpasang menggunakan mesin assembly apakah terdapat komponen yang tidak terpasang dengan baik, seperti kurangnya timah pada kaki komponen atau komponen yang tidak tepat pada pad yang disediakan. Gambar ‎7.24 dan Gambar ‎7.25 merupakan gambar proses roduksi menggunakan mesin assembly dan manual.


Gambar ‎7.24. Proses produksi modul BMS menggunakan mesin PCB Assembly


Gambar ‎7.25. Proses produksi modul BMS secara manual

Modul BMS mempunyai dimensi sebesar 132 x 100 mm, didesain sedemikian rupa sehingga menjadi sangat mudah dikemas dan sangat fleksibel dengan penempatan pada baterai pack dengan tidak mengurangi fungsi dan fitur dari BMS itu sendiri. Namun, dalam proses produksi, komponen dipasang secara bersamaan dalam satu block PCB untuk mempercepat proses produksi, dimana dalam 1 block terdiri dari 2 (empat) buah modul BMS. Modul BMS yang sudah terpasang komponen dapat dilihat pada Gambar ‎7.26.

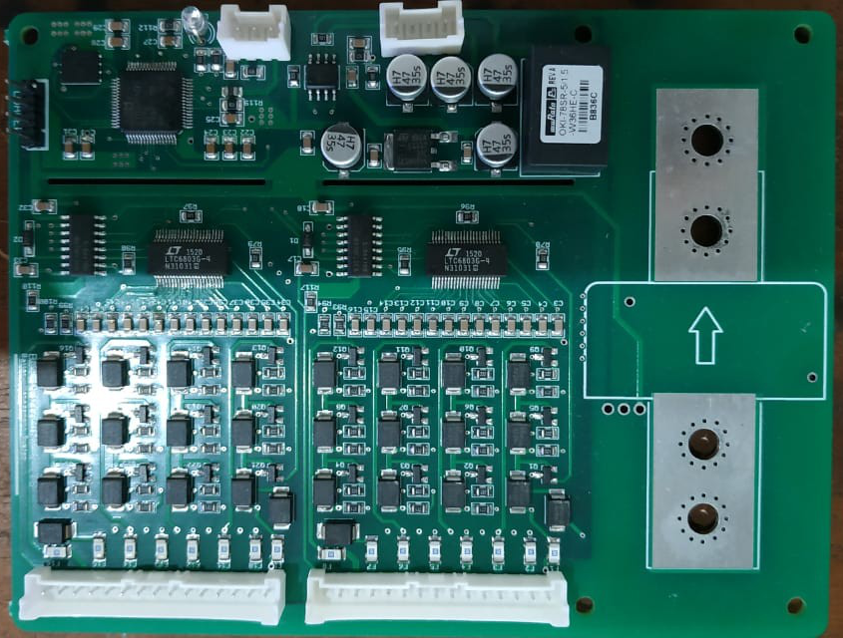
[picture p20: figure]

Gambar ‎7.26. Modul BMS

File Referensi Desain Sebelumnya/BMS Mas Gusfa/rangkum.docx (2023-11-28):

BMS

  1.1 PCB
  1.2 Modul Controler - Mikrokontroler berbasis ARM dengan tipe STM32F405RGT6. - Kapasitor 100nF - Resistor 103
  1.3 Modul Voltage Regulator - Voltage regulator LD1117DT33CTR dengan modul OKI-78SR. - Kapasitor 100nF
  1.4 Modul Pengukur Tegangan per Cell - IC LTC6803-4
  1.5 Modul Balancing - Mosfet P Si2351DS - Diode Zener 7.5 Volt - Resitor 2k2 - Resistor 220 - Fuse
  1.6 Modul Opto Isolator - Digital Isolator Si8441BB-D-IS1 - Resistor 220
  1.7 Modul Pengatur Temperatur - Thermistor NTC 100 K - Resitor 10K ohm - Resistor 100 ohm - Kapasitor 100 nF
  1.8 Modul Magneto Resistive Random Access Memory (MRAM) - MR25H256CDC - Kapasitor 100nF
  1.9 Modul Komunikasi CAN - IC SN65HVD230DR

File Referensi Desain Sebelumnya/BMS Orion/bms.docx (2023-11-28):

1. Buatan siapa orion bms : EWERT ENERGY SYSTEM, inc made in USA

161 East St. Charles Rd
Carol Stream, IL 60188

Phone: (630) 868-3173
Fax: (866) 657-5667

2. Fitur orion bms : The main features: monitoring every cell voltage, programmable and upgradeable, enforce min. and max. cell voltages, enforces max current limits, enforce temperature limits, Intelligent cell balancing, professional and robust design, monitors state-of-charge, retains data about battery history, integration with 3rd party smartphone apps (Torque, EngineLink) Thermal Management, Voltage Protection, State of Charge, CANBUS Interfaces, OBD-II Support, Automotive Noise Immunity.
3. Safety : Isolation fault detection, Multiple BMS units may be used in series, calculate the state of health, calculate charge current limit, discharge current limit, Internal resistance, high immunity to EMI and other noise, high accuracy cell voltage measurement, On/Off outputs for controlling charge and discharge, 0-5V analog outputs for gradual current reduction (improves usable range of battery), thermal management controls for battery cooling/heating.

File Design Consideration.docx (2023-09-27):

1. Modul opto isolation untuk isoSPI: SDI, SCKI, SDO, CSBI → beli di www.tokopedia.com/palta
a. ADUM1201 25Mbps

https://www.tokopedia.com/lisuinstrument/adum1201-adum1201arz-2-channel-digital-isolator-sop-8?whid=0

harga: 20rb

The ADuM1201 is a dual-channel, digital isolator with 1/1 channel directionality based on the Analog Devices, Inc., iCoupler technology. Combining high speed CMOS and monolithic transformer technologies, these isolation components provide outstanding performance characteristics superior to alternatives, such as optocouplers.

b. SI8641 150 Mb/s

https://www.mouser.co.id/ProductDetail/Skyworks-Solutions-Inc/SI8641BD-B-IS?qs=j6MGy4L9yX0YgmbfIyfDIQ%3D%3D

harga: 65rb

c. ADUM1402/ADUM1402BR 10Mbps

Harga: 35rb

https://www.mouser.co.id/ProductDetail/Analog-Devices/ADUM1402BRWZ-RL?qs=WIvQP4zGangvDxnUzYXbPg%3D%3D

d. S
2. sdsd

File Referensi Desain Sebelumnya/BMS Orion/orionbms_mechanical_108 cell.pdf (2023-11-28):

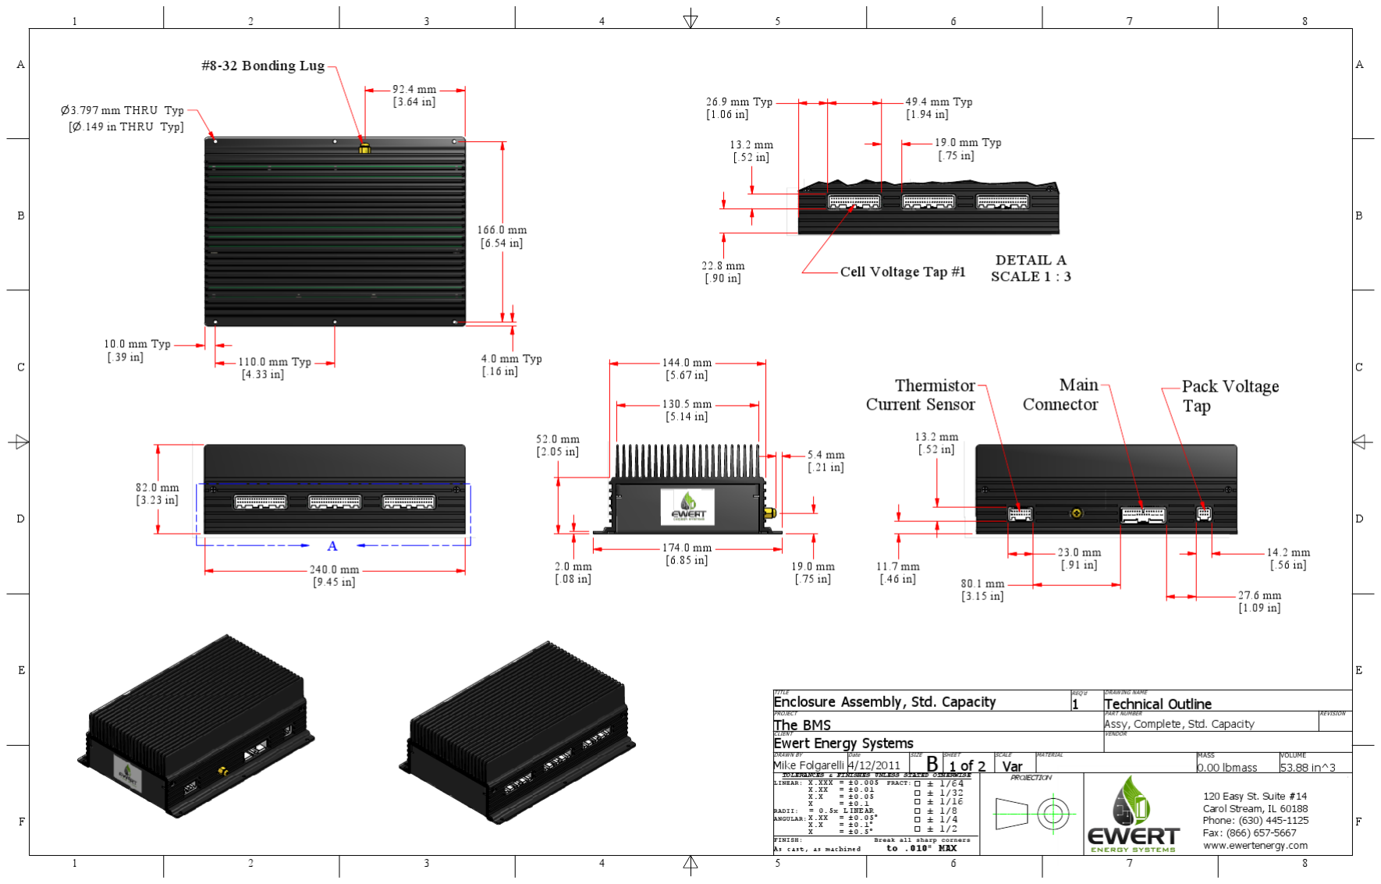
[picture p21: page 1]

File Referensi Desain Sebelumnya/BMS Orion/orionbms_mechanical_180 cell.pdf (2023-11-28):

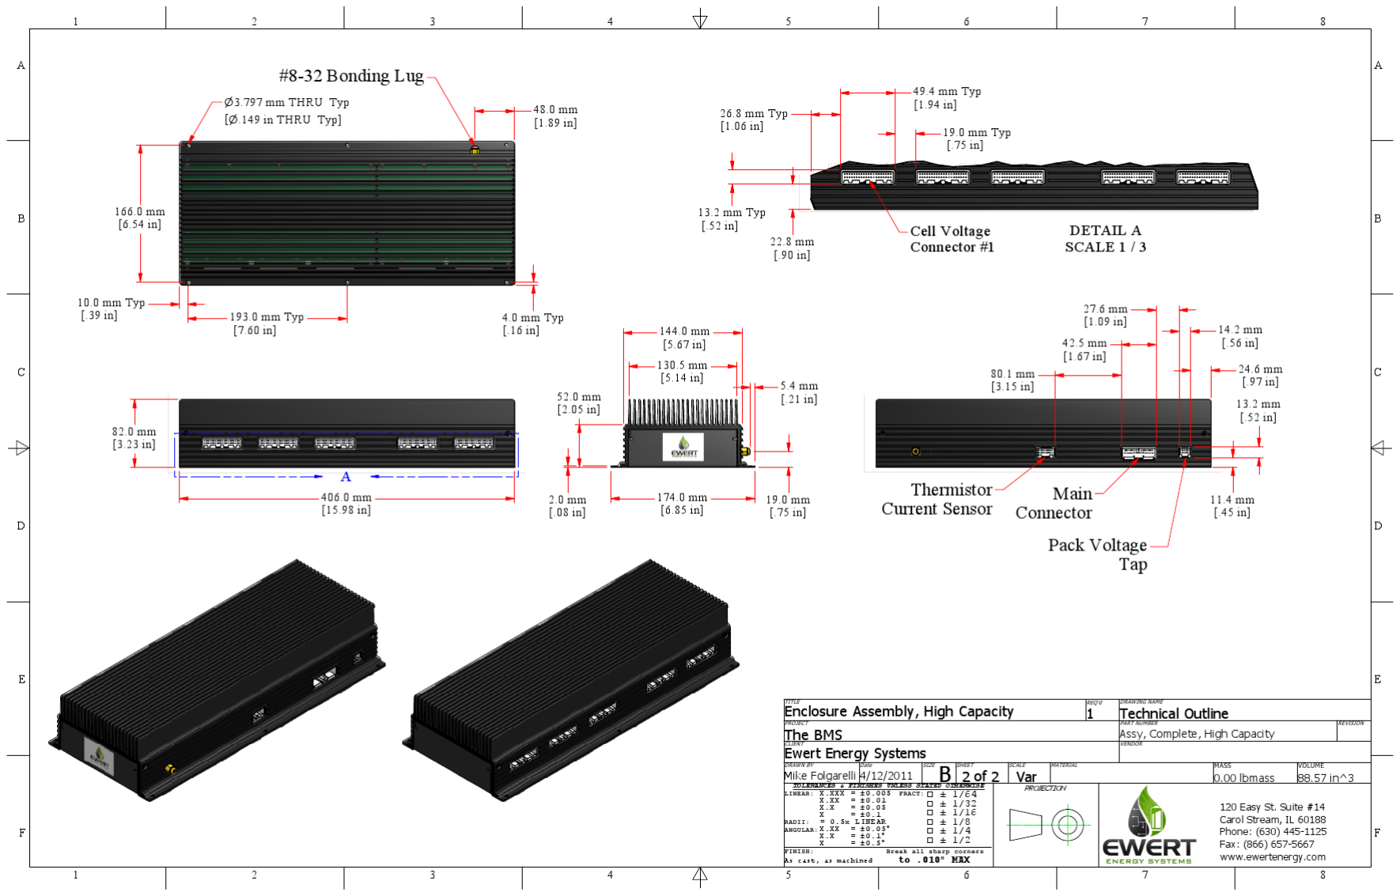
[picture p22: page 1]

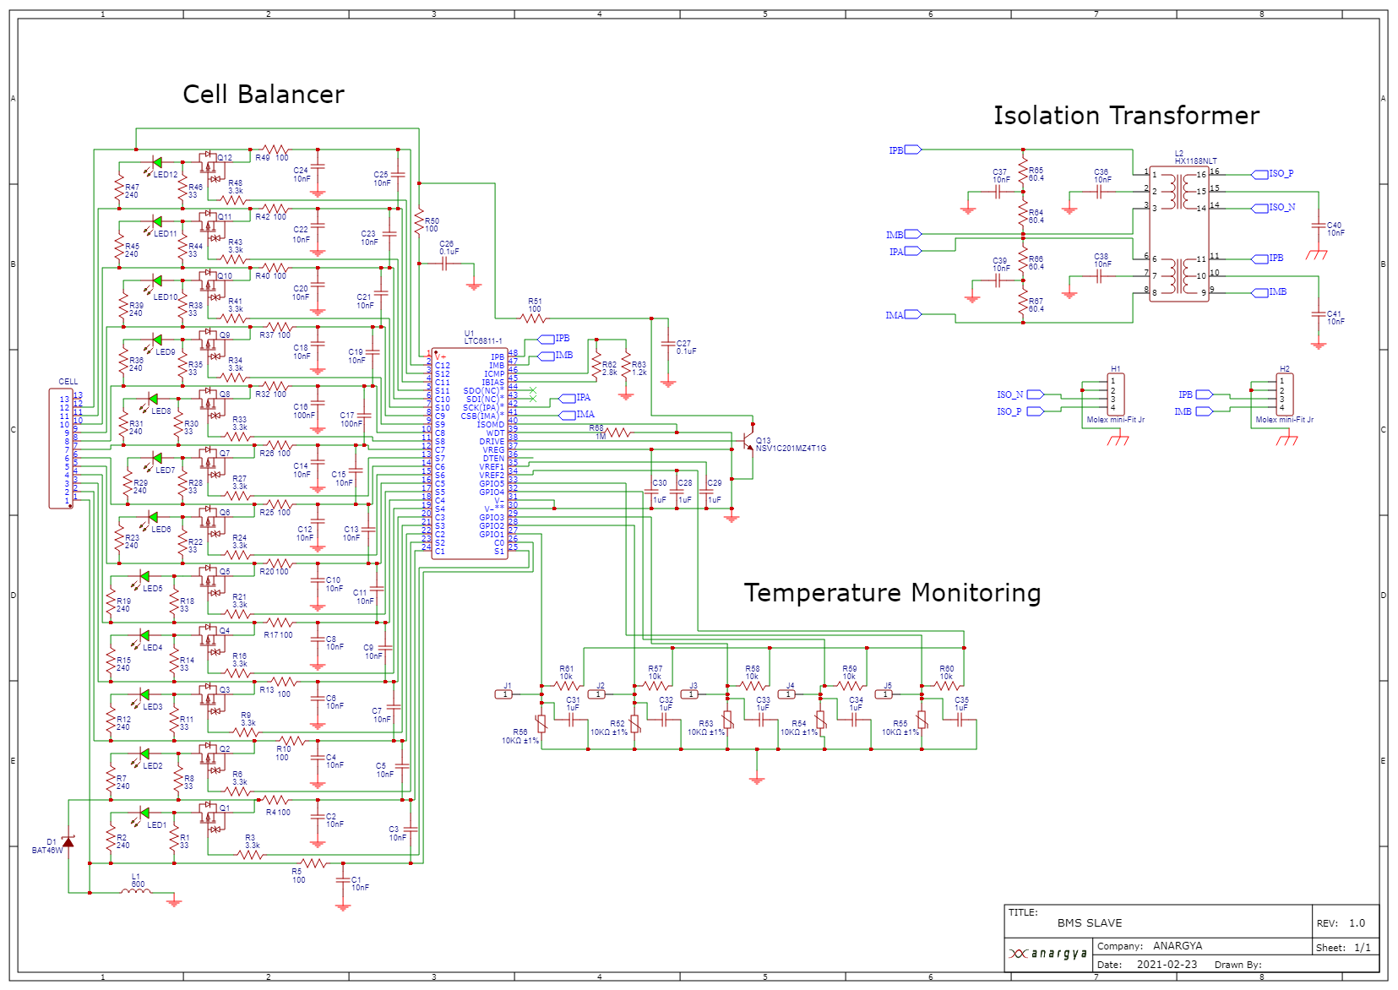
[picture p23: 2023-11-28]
Referensi Desain Sebelumnya/Schematic_BMS Slave .png

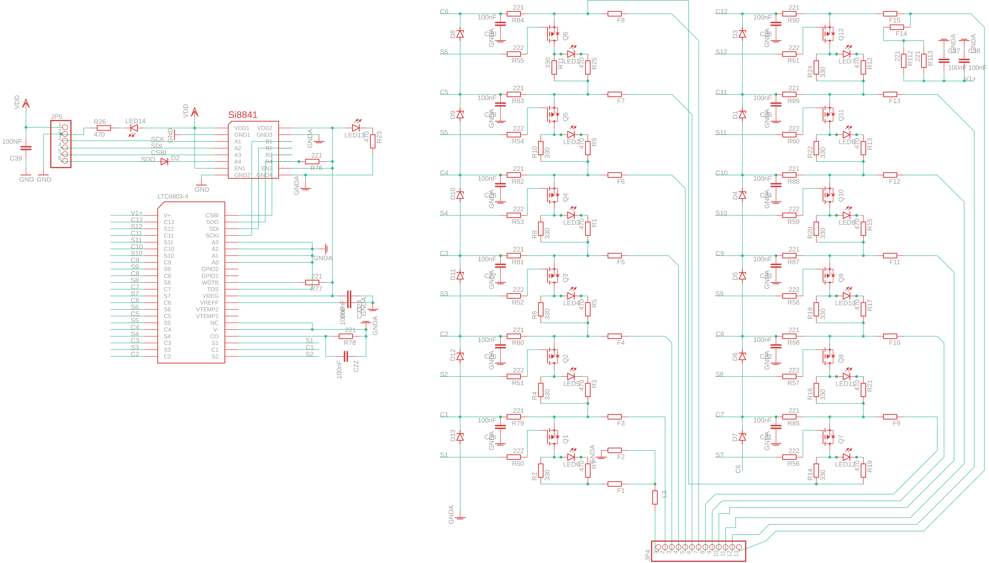
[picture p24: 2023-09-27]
dari Mas Tengku Molina ITS/igudefsi un't8mbnt 4ew.png

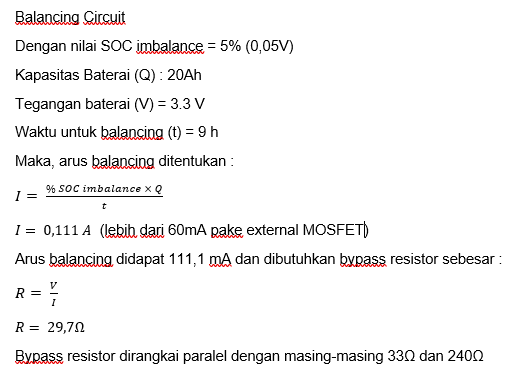
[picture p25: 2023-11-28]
Referensi Jurnal/kalkulasi cell balancer.PNG

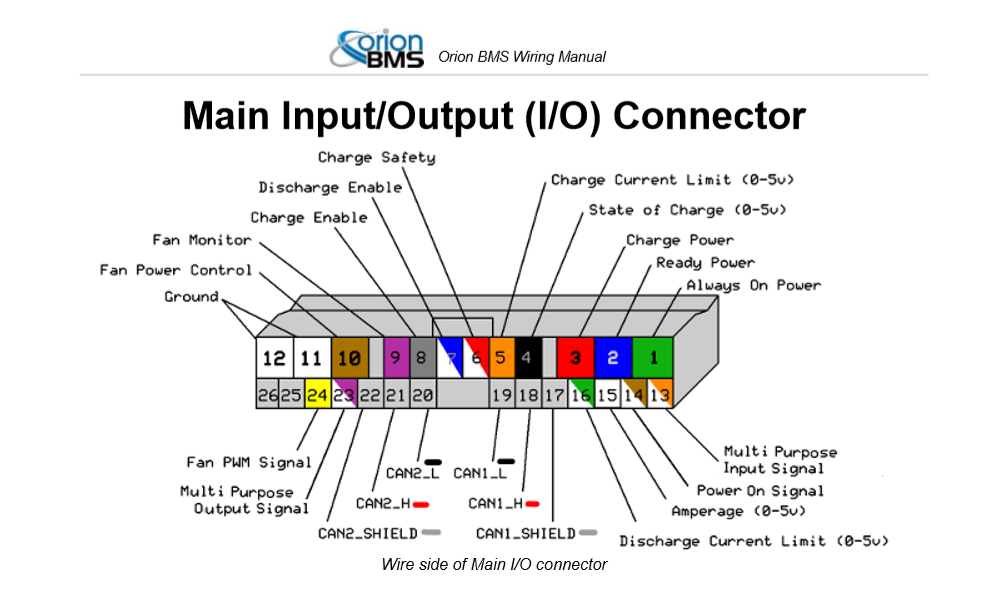
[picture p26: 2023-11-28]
Referensi Desain Sebelumnya/BMS Orion/main input-output connector BMS.png

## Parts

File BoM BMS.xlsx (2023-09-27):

No | Sub-sistem | Part | Harga satuan | Jumlah | Harga total | beli dimana? | link beli
1 | Digital isolator | SI8441BB-D-IS1 | Rp 34000 | 1 | Rp 34000 | ofline di WDP jangkar miring | https://www.tokopedia.com/wiksatech/isolator-si8441bb-d-is1
2 | Multistack Bt Monitor | LTC6803-4 | Sudah terbeli
3 | connector | Straight foot header 12p | Rp 4200 | 1 | Rp 4200 | ofline toko genteng | https://www.tokopedia.com/eltech-online/12-12p-p-2-54mm-2510-straight-connector-wafer-housing-konektor-lurus
4 | mosfet discharge | AO3401 | Rp 500 | 12 | Rp 6000 | ofline di toko dpn graha its | https://www.tokopedia.com/isee/mosfet-ao3401-mos-fet-ao-3401-sot23-p-channel-30v-4a-a19t-sot-23-30-v
5 | resistor SMD led discharge | res 470R 1206 | Rp 150 | 17 | Rp 2550 | ofline di toko dpn graha its | https://www.tokopedia.com/isee/resistor-smd-1206-470r-470-ohm-toleransi-1-tolerance-1
6 | Digital isolator | SI8441BB | Rp 34000 | 1 | Rp 34000 | ofline di WDP jangkar miring | https://www.tokopedia.com/wiksatech/isolator-si8441bb-d-is1
7 | resistor SMD discharge | res 47R 2512 | Rp 400 | 15 | Rp 6000 | ofline di WDP jangkar miring | https://www.tokopedia.com/wiksatech/resistor-47r-1w-5-2512
8 | PMOS Discharge | si2301ds | Rp 500 | 20 | Rp 10000 |  | https://www.tokopedia.com/lisuinstrument/si2301-p-channel-mosfet-si2301ds-2301-a1shb-sot-23-biasa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
9 | capacitor | cap 100n 1206 | Rp 200 | 20 | Rp 4000 |  | https://www.tokopedia.com/wiksatech/kapasitor-100nf-20-1206
10 | resistor c(n) dan res output spi dan v+ c12 | res 100R 1206 | Rp 200 | 30 | Rp 6000 | ofline di toko dpn graha its | https://www.tokopedia.com/isee/resistor-smd-1206-100ohm-100-ohm-toleransi-1-tolerance-1
11 | resistor signal gate pmos s(n) | res 3.3k 1206 | Rp 200 | 20 | Rp 4000 | ofline di toko dpn graha its | https://www.tokopedia.com/isee/resistor-smd-1206-3k3-3-3k-kilo-ohm-3300-ohm-toleransi-1-tolerance
12 | zener proteksi 5.1v 0.5w | zener 5.1v LL-34 | Rp 150 | 20 | Rp 3000 |  | https://www.tokopedia.com/isee/dioda-smd-zener-0-5w-diode-5v1-5-1v-5-1-v-1-2w-1-2-0-5-0-5-w-5-1v-0-5w
13 | LED indicator discharge | LED 0805 biru | Rp 150 | 20 | Rp 3000 | ofline di toko dpn graha its | https://www.tokopedia.com/isee/10x-led-smd-0805-hb19-super-bright-2hb0756-terang-warna-biru
14 | resistor led discharge | res 470R 1206 | Rp 200 | 20 | Rp 4000 |  | https://www.tokopedia.com/isee/resistor-smd-1206-470r-470-ohm-toleransi-1-tolerance-1
15 | IC RESETTABLE FUSE discharge | PPTC Fuse 500mA 1206 | Rp 1399 | 22 | Rp 30778 | tokped lisu instrumen, free ongkir >10rb | https://www.tokopedia.com/lisuinstrument/pptc-1206-series-resettable-self-recovery-fuse-polyswitch-500ma-13-2v
16 | kapasitor VREG dan VDD SI8441 dan C_VTEMP | cap 1u 1206 | Rp 400 | 10 | Rp 4000 | ofline di WDP jangkar miring | https://www.tokopedia.com/wiksatech/kapasitor-1uf-20-1206
17 | resistor quad channel | res 1206 4k7 | Rp 200 | 10 | Rp 2000 | ofline di toko dpn graha its | https://www.tokopedia.com/isee/resistor-smd-1206-4k7-4-7k-kilo-ohm-4700-ohm-toleransi-1-tolerance
18 | resistor vdd si8441 | res 1206 1k | Rp 200 | 5 | Rp 1000 | ofline di toko dpn graha its | https://www.tokopedia.com/isee/resistor-smd-1k-ohm-size-1206-1-4-watt-1
19 | resistor c0 v- dan res WDTB | res 1206 220 | Rp 200 | 10 | Rp 2000 | ofline di toko dpn graha its | https://www.tokopedia.com/isee/resistor-smd-1206-220ohm-220-ohm-toleransi-1-tolerance-1
20 | low power opamp vtemp | lmv358 | Rp 7000 | 3 | Rp 21000 |  | https://www.tokopedia.com/indo-ware/ti-lmv358idr-lmv358i-lmv358-mv358-sop8-operational-amplifier-smd
21 | pin header iso-spi 6p | header female 20p | Rp 750 | 2 | Rp 1500 | ofline di toko dpn graha its | https://www.tokopedia.com/isee/header-female-1x6-pin-p-6p-2-54mm-single-row-lurus-1x6p-1-x-6-pcb
22 | terminal block hv sel | pitch 5.08 7p lurus | Rp 7000 | 2 | Rp 14000 | ofline di toko dpn graha its | https://www.tokopedia.com/isee/2edg-5-08-7p-lurus-green-terminal-pin-block-connector-screw-5-08mm
23 | schottky diode v+ ltc | ss110 sb110 | Rp 450 | 4 | Rp 1800 | ofline di toko dpn graha its | https://www.tokopedia.com/isee/ss110-sb1100-diodo-schottky-100v-1a-do-214ac-dioda-smd
24 | schottky barrier 100v v+ ltc | R510 SR5100 SB5100 Diode Schottky BARRIER Rectifier 100V 5A DO27 | Rp 3000 | 4 | Rp 12000 | tertera dibawah ini | https://www.tokopedia.com/wkh-elektronik/dioda-sr510-sr5100-sb5100-diode-schottky-barrier-rectifier-100v-5a
25 | induktor B- | DS1207 induktor 12x12x7mm 22uH 22 uH 220 | Rp 3000 | 2 | Rp 6000 |  | https://www.tokopedia.com/isee/ds1207-induktor-12x12x7mm-22uh-22-uh-220-smd-power-inductor-lilit
26 | cap 2 way iso dcdc | cap 2 way jumper warna kuning/yg lain | Rp 100 | 5 | Rp 500 | ofline di toko dpn graha its | https://www.tokopedia.com/isee/2-way-jumper-hardisk-hard-disk-disc-cap-short-circuit-fast-spacing-hitam
27 | terminal block EDG VTEMP | terminal block 2pin EDG lurus 5.08mm | Rp 2600 | 4 | Rp 10400 | ofline di toko dpn graha its | https://www.tokopedia.com/isee/2edg-5-08-2p-lurus-green-terminal-2-pin-block-connector-screw-5-08mm
 | keterangan:
 |  | tidak jadi beli
 |  | tolong dibelikan
 |  | sudah dibeli faris, belum di rimburse
 |  |  |  |  | Total per toko
 | TOKO WKH Elektronik |  |  | 1 | Isee | Rp 48750
 | Informasi COD : |  |  | 2 | Wiksa WDP | Rp 44000
 | Daerah wonorejo selatan rungkut |  |  | 3 | WKH online | Rp 12000
 | Notel.wa 0x81x8x45x99x55 |  |  | 4 | Lisu instrumen tokped | Rp 30778
 | Hilangkan x
 | Harus janjian dulu ya kak |  |  |  | TOTAL : | Rp 135528
 | WKH ongkir kalo tokped 6000

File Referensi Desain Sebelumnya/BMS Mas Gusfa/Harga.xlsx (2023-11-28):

No. | Bagian | Komponen | Unit | Harga per-unit | Harga total
1 | PCB |  | 1 | $70 | $70.00
2 | Microcontroller | STM32F405RGT6 | 1 | $10.58 | $10.58
3 | Voltage Regulator | LD1117DT33CTR | 1 | $0.45 | $0.45
4 |  | Modul OKI-78SR | 1 | $5.90 | $5.90
5 | Balancing | Mosfet P Si2351DS | 24 | $0.45 | $10.80
6 |  | Diode Zener 7,5v | 24 | $0.39 | $9.36
7 | Pengukur Tegangan per Cell | IC LTC6803-4 | 2 | $19.28 | $38.56
8 | Opti Isolator | Digital Isolator Si8441BB-D-IS1 | 2 | $2.48 | $4.96
9 | Temperature Sensor | Thermistor NTC 100 K | 1 | $12.00 | $12.00
10 | MRAM | MR25H256CDC | 1 | $6.50 | $6.50
11 | CAN | IC SN65HVD230DR | 1 | $2.31 | $2.31
12 | Lain-Lain | Kapasitor 100µF | 59 | $0.23 | $13.57
13 |  | Resistor 220 | 37 | $0.26 | $9.62
14 |  | Resistor 2K2 | 26 | $0.14 | $3.64
15 |  | Resistor 103 | 7 | $0.88 | $6.16
16 |  | Resistor 101 | 1 | $0.26 | $0.26
17 |  | Resistor 470 | 48 | $0.14 | $6.72
18 |  | Fuse | 30 | $0.80 | $24.00
19 |  | LED | 1 | $0.04 | $0.04
20 |  | White House pos 4 | 2 | $0.57 | $1.14
21 |  | White House pos 3 | 1 | $0.44 | $0.44
22 |  | White House pos 15 | 2 | $0.88 | $1.76
TOTAL |  |  |  |  | $238.76

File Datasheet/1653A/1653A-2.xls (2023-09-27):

Item | Qty | Ref - Des | Desc | Manufacturer's Part Number
1 | 14 | C1-C13,C19 | CAP, 1206 100nF 20% 100V X7R | MURATA GCM319R72A104MA37D
2 | 11 | C14,C15,C23-C30,C35 | CAP, 0603 1uF 10% 16V X7R | MURATA GCM188R71C105KA64D
3 | 4 | C16,C17,C18,C22 | CAP, 0603 100nF 10% 25V X7R | MURATA GCM188R71E104KA57D
4 | 1 | C20 | CAP, 0603 220pF 5% 50V NPO | AVX 06035A221JAT
5 | 3 | C21,C32,C34 | CAP, 1206 10uF 10% 16V X7R | MURATA GCM31CR71C106KA64L
6 | 1 | C31 | CAP, 1206 1uF 10% 100V X7R | MURATA GRM31CR72A105KA01L
7 | 1 | C33 | CAP, 1206 1000pF 5% 630V U2J | MURATA GCM31A742J102JX01D
8 | 3 | D1,D2,D3 | DIODE, SWITCHING | VISHAY RS07J
9 | 3 | D4,D5,D7 | DIODE, SCHOTTKY | DIODES INC. BAT46W
10 | 1 | D6 | DIODE, ZENER, 62V | DIODES INC. ZMM5265B-7
11 | 13 | D8-D20 | DIODE, ZENER 7.5V 200mW SOD323 | PHILIPS PDZ7.5B
12 | 4 | D21,D22,D23,D24 | DIODE, SWITCHING, DUAL | DIODES INC. BAV99
13 | 6 | E1,E2,E3,E4,E5,E6 | TURRET | MILL MAX 2308-2-00-80-00-00-07-0
14 | 6 | JP1,JP2,JP3,JP4,JP5,JP6 | SHUNT | SAMTEC 2SN-BK-G
15 | 6 | JP1,JP2,JP3,JP4,JP5,JP6 | HEADER,3PIN, 2mm | SAMTEC TMM-103-02-L-S
16 | 1 | J1 | HEADER, 1X16 3.5mm, HORIZ. | WEIDMULLER 1761682001
17 | 2 | J2,J3 | HEADER, 2X7 2mm | MOLEX 87831-1420
18 | 12 | LED1-LED12 | LED, 0603 GREEN | LITE-ON LTST-C190KGKT
19 | 25 | L1-L25 | IND, 1210 10 uH 10 % 187 mA SMD | WURTH ELEKTRONIK 74476410
20 | 1 | P1 | CONN. MATING 1X16 3.5 HORZ | WEIDMULLER 1615770000
21 | 10 | Q1-Q10 | XSTR, MOSFET, P-CHANNEL | RENESAS RQJ0303PGDQALT-E
22 | 2 | Q11,Q12 | XSTR, MOSFET, P-CHANNEL | ROMH RTR020P02
23 | 1 | R1 | RES, 0603 33.2K OHMS 1% 1/4W | NIC NRC06F3322TRF
24 | 1 | R4 | RES, 0603 100 OHMS 5% 1/10W | NIC NRC06F3322TRF
25 | 15 | R5,R7,R9,R11,R13,R15,R17,R19, | RES, 0603 100 OHMS 1% 1/10W | NIC NRC06F1000TRF
 |  | R21,R23,R25,R27,R29,R30,R69
26 | 12 | R6,R8,R10,R12,R14,R16,R18, | RES, 0603 3.3k OHMS 5% 1/10W | NIC NRC06J332TRF
 |  | R20,R22,R24,R26,R28
27 | 3 | R31,R32,R70 | RES, 0603 10K OHMS 1% 1/10W | NIC NRC06F1002TRF
28 | 2 | R33,R34 | RES, 0603 4.99K OHMS 1% 1/10W | NIC NRC06F4991TRF
29 | 0 | R35,R40 | RES, 1206 OPTION | OPTION
30 | 7 | R36,R37,R39,R41-R44 | RES, 0603 1M OHMS 1% 1/10W | NIC NRC06F1004TRF
31 | 12 | R45-R56 | RES, 0603 475 OHMS 1% 1/10W | NIC NRC06F4750TRF
32 | 12 | R57-R68 | RES, 2512 33 OHMS 5% 1W | NIC NRC100J330TRF
33 | 1 | T1 | XFMR, 1:1:1, 1140uH | PULSE PA0264NL
34 | 1 | U1 | IC, BATTERY MONITOR | LINEAR TECH. LT6803IG-3
35 | 1 | U2 | IC, Op AMP DUAL | LINEAR TECH LT6004CMS8
36 | 1 | U3 | IC, DUAL N-CHANNEL MOSFET DRIVERS | LINEAR TECH. LTC1693-2IS8
37 | 1 | U4 | IC, REGULATOR | LINEAR TECH. LT1790BCS6-5
38 | 1 | U5 | IC, 24LC025-I/ST | MICROCHIP TECH. 24LC025-I/ST
39 | 1 | U6 | IC, 0.25ppm NOISE, LOW DRIFT PRECISION BUFFERED REFERENCE OPTION | LINEAR TECH. LTC6655BHMS8-3.3 OPTION
40 | 4 |  | STANDOFF, SNAP ON | KEYSTONE_8831

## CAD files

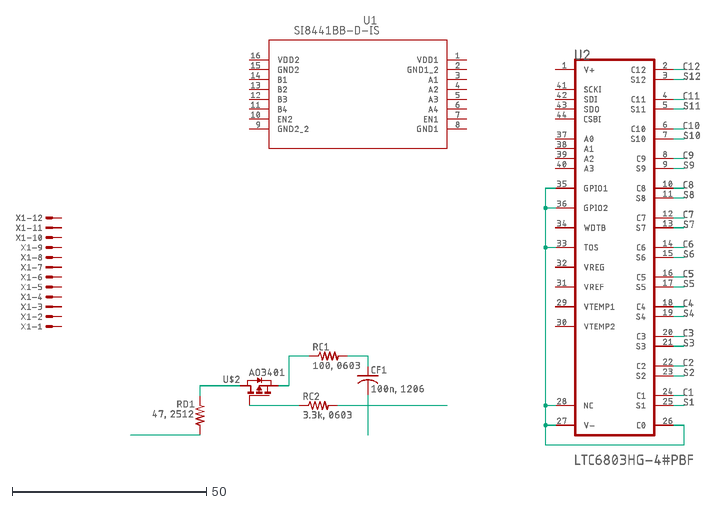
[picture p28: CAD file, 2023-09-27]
Single Board 12s/Single Board 12s.dxf
175.9 x 115.3

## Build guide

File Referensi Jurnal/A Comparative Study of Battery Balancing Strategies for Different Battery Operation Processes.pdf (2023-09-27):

# A Comparative Study of Battery Balancing Strategies for Different Battery Operation Processes

Linfeng Zheng¹,2, Jianguo Zhu¹

, Guoxiu Wang²
1. Faculty of Engineering and Information Technology, University of Technology Sydney, Sydney, N.S.W., 2007, Australia
2. Centre for Clean Energy Technology, University of Technology Sydney, Sydney, N.S.W., 2007, Australia Linfeng.Zheng@student.uts.edu.au

Abstract-To reduce the effect of cell inconsistencies and improve battery pack capacity, battery balancing techniques are essentially required in battery management systems (BMSs). This paper presents a comparative study of four battery balancing strategies for different battery operation processes. These balancing strategies are developed from the state-of-the-art battery balancing circuits and algorithms reported in recent literature. The performance of balancing strategies is evaluated and compared by battery pack maximum available capacity, state of charge (SOC) variances at the end of charge (EOC) and end of discharge (EOD). The comparative result is helpful for BMSs developers to employ optimal balancing strategies in actual applications.

Keywords-Battery balancing, battery pack capacity, SOC variance, battery management system (BMS).

I. INTRODUCTION

As one single battery cell has limited capacity and voltage, it normally needs up to hundreds, even thousands of single cells connected in series and parallel for electrified vehicles and energy storage systems to provide sufficient power and energy. In such a battery pack, inevitable cell inconsistencies are concerned due to two categories: the inconsistent manufacturing process such as different internal impedance and self-discharge rate, and the inhomogeneous operating environment such as various ambient temperature [1, 2]. To improve cell consistencies, increase battery pack capacity and prolong battery pack service life, battery cell balancing techniques are essentially required in battery management systems (BMSs).
Among the literature, most papers focus on battery balancing circuit topologies [2-7] and balancing algorithms [1, 5-14]. The battery balancing circuit topologies reported in [2-7] mainly include resistor bleeding (passive balance), cell to cell, cell to pack, pack to cell and cell to pack to cell, and their advantage and disadvantage were presented in detail. According to the literature [1, 5-14], the battery balancing algorithms can be mainly divided into two categories: voltage-based balancing algorithm and SOC-based balancing algorithm. The voltage-based balancing algorithm which targets the consistent battery cell terminal voltages is widely used in research and industry [5-10]. The SOC-based balancing algorithm which targets the consistent battery cell SOCs requires accurate cell SOC estimation [1, 10-14]. While their pros and cons are discussed in the literature, unfortunately, there are few studies that compare these balancing circuits incorporating the balancing algorithms in a comprehensive and systematical manner.
Regardless of balancing circuits and algorithms, when to perform balancing plays a vital role in balancing performance. Performing balancing during different battery operation processes, such as constant current charging processes, dynamic current discharging processes and rest time, may lead to various balancing effects.
Therefore, it is essential to carry out a comparative study of battery balancing strategies incorporating balancing circuits and algorithms for different battery operation processes.
The rest of the paper is organized as follows: Section II introduces four battery balancing strategies which are developed from the balancing circuits and balancing algorithms for simulation experiment. The experimental results and evaluation of the four balancing strategies for different battery operation processes are discussed and reported in Section III, followed by the conclusions and future work in Section IV.
II. | BATTERY BALANCING STRATEGIES

According to the balancing current used for battery cell charging or discharging, we classify battery balancing circuits into four categories: passive discharge balance, active discharge balance, charge balance, and charge-discharge (namely bidirectional) balance. Regardless of balancing circuits, effective balancing algorithms are highly required to maximize balancing effects. It has been reported that the voltage-based balancing algorithm cannot achieve desirable

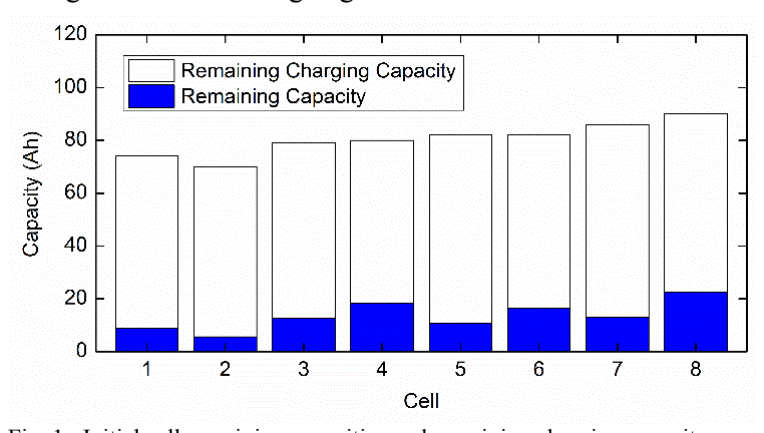
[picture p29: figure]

Fig. 1. Initial cell remaining capacities and remaining charging capacity.

## 978-1-5090-0403-4/16/$31.00 ©2016 IEEE

Authorized licensed use limited to: Institut Teknologi Sepuluh Nopember. Downloaded on September 14,2022 at 09:15:09 UTC from IEEE Xplore. Restrictions apply.

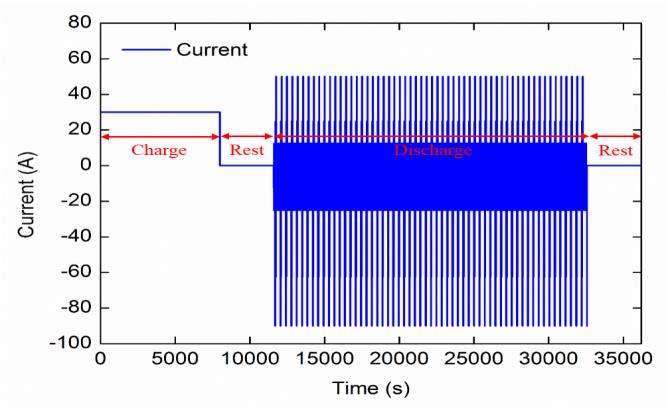
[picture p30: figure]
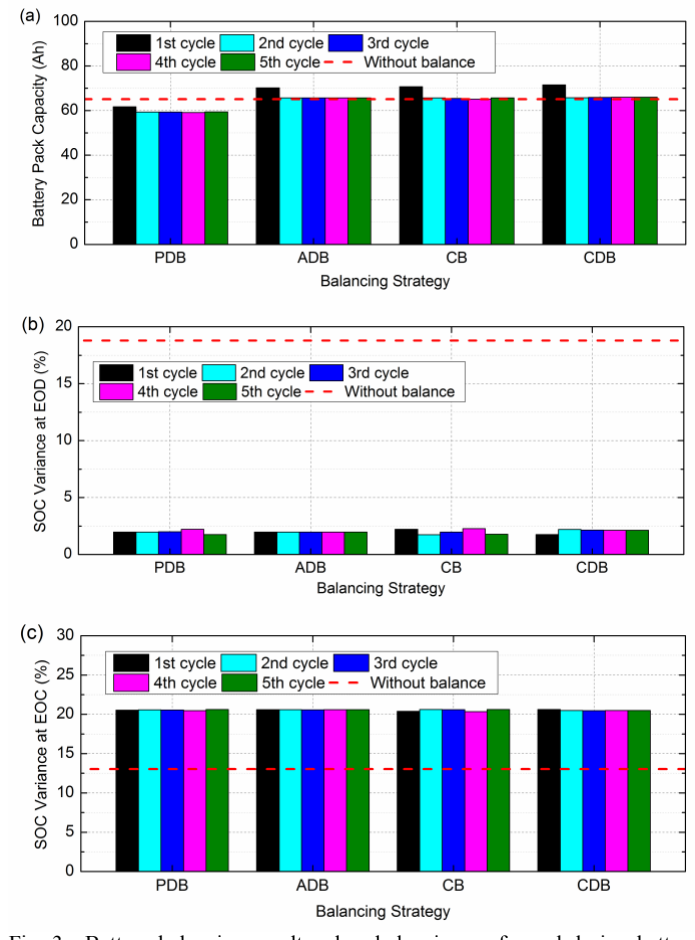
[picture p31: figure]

balancing results because a small voltage variation may lead to a large capacity inconsistency, especially for some kinds of batteries with flat charge/discharge voltage plateau [1]. The SOC-based algorithm can really reflect the battery capacity level and therefore it was employed for this study. Combining the classified circuit categories with the SOC-based balancing algorithm, we can obtain four balancing strategies: SOC-based passive discharge balance (PDB), SOC-based active discharge balance (ADB), SOC-based charge balance (CB), and SOC-based charge-discharge balance (CDB).

III. | RESULTS AND DISCUSSION

In order to investigate the performance of different balancing strategies applied for various battery operation processes, eight Lithium manganite battery cell models connected in series with different available capacities and SOCs shown in Fig. 1 were used for balancing experimental simulation. The charge/discharge balance current was set to 4 A while the balance referenced SOC was set to the average SOC with a band of +/-1%. The efficiency of the balancer was set to 85%, which means that there are 15% of balance energy will be dissipative during balancing.
The battery operation processes usually include charge process, rest time after charge, discharge process, and rest time after discharge. To simulate the charge and discharge processes of battery used in electric vehicles, a constant current was used for battery charging and dynamic stress test (DST) [15] profiles were used for battery discharging, as shown in Fig. 2. Each battery operation cycle began with a constant current at C/3 to charge to the battery pack until one of the battery cells reached to the upper limit voltage 4.2 V. Then there was a rest for 1 h followed by DST profiles to discharge the battery pack until one of the battery cells reached the lower limit voltage 3 V. Subsequently, it followed a rest for 1 h and then repeated the operation cycle. The battery pack maximum available capacity was calculated by ampere-hour counting during the whole discharge process. Five battery operation cycles were used for evaluating the balancing results including battery pack maximum available capacity, SOC variances at the end of discharge (EOD) and the end of charge (EOC).

Without balance, the battery pack maximum available capacity is 65.06 Ah which is less than the minimum cell capacity (cell 2 charged in constant current regime) of 66.63 Ah, while the maximum SOC variance at EOC is 13.05% and the maximum SOC variance at EOD is 18.8%. The mean battery cell capacity (charged in constant current regime) is 77.16 Ah.
When balancing performed during battery discharge processes, the balancing results are shown in Fig. 3. In Fig. 3(a), the ADB, CB and CDB strategies are able to increase the battery pack capacity, and the final battery pack capacities are a little larger than the capacity without balance. However, the balanced pack capacities were still less than the minimum cell capacity. It is noted that the PDB method caused a counterproductive balancing result that the battery pack capacity is less than the value without balance. This is because that the PDB method is an energy dissipation method and the dissipative energy could not supply from elsewhere. It can be seen that different balancing strategies were able to make an improvement in decreasing SOC variances at EOD compared with the result without balance as shown in Fig. 3(b). On the contrary, the SOC variances at EOC were increased, which are larger than the value without balance as shown in Fig. 3(c).

Fig. 3. Battery balancing results when balancing performed during battery discharge processes: (a) battery pack capacity, (b) SOC variance at EOD and
(c) SOC variance at EOC.

Fig. 2 Battery operation processes.

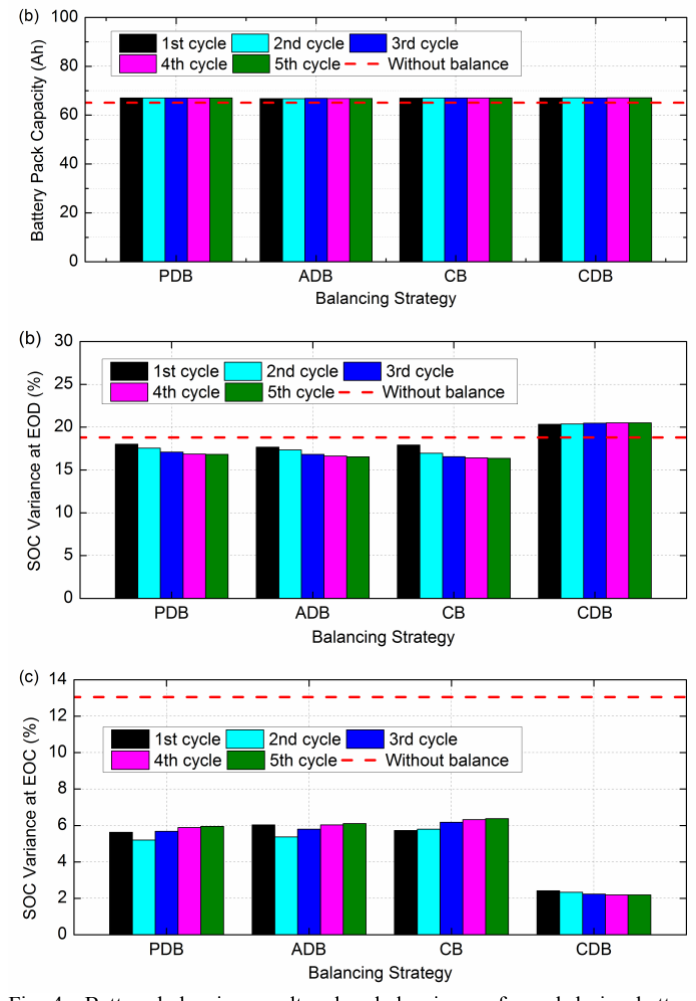
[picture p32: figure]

Fig. 4 shows the balancing results when balancing performed during battery charge processes. In Fig. 4(a), four balancing strategies were able to make an improvement on the battery pack capacities, which are about equal to 67.00 Ah. As shown in Fig. 4(c), the SOC variances at EOC were shortened to a small level compared with the value without balance. However, SOC variances at EOD presented inconsistent change. For the PDB, ADB and CB strategies, there was a little decrease on the SOC variances at EOD. But for the CDB strategy, the SOC variance at EOD was increased to be larger than the value without balance.
When balancing performed during battery rest time after discharge, the battery balancing results are shown in Fig. 5. The battery pack capacities for four different balancing strategies depicted in Fig. 5(a) showed a shade of increment in comparison with the value without balance. The SOC variances at EOD appeared a gradual decline trend as shown in Fig. 5(b) and in the final cycle, the SOC variances can be limited to a small value. However, the SOC variances at EOC shown in Fig. 5(c) gradually rose with the cycle time and finally achieve a high level. Moreover, the balancing results of the fifth cycle shown in Fig. 5 are similar to the results

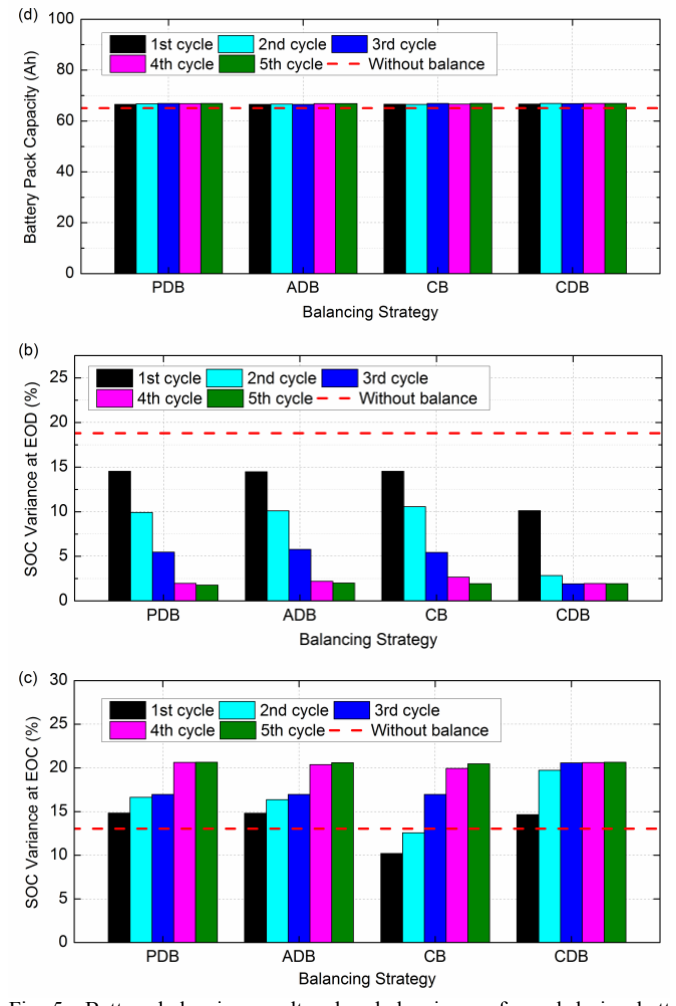
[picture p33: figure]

when balancing performed during battery discharge processes shown in Fig. 3. This is because the four mentioned-above balancing strategies are able to limit the SOC variance at EOD in a balance referenced SOC band when balancing performed during battery discharge process and rest time after discharge. However, it would have a counterproductive effect on the variance at EOC and increase the value of the variance at EOC.
The balancing results when balancing performed during battery rest time after charge are drawn in Fig. 6, where battery pack maximum available capacities of the final cycle can be approximately increase to 66.86 Ah which is a little larger than the battery pack capacity value without balance. SOC variances at EOD and EOC showed in Fig. 6(b) and 6(c), respectively, presented exactly opposite results to the balancing results when balancing performed during battery rest time after charge shown in Fig. 5(b) and Fig. 5(c). It can be seen that in Fig. 6(b), the SOC variances at EOD dropped gradually and reached to a small level. But the SOC variances at EOD finally increased to be larger than the value without balance.

Fig. 4. Battery balancing results when balancing performed during battery charge processes: (a) battery pack capacity, (b) SOC variance at EOD and (c) SOC variance at EOC.

Fig. 5. Battery balancing results when balancing performed during battery rest time after discharge: (a) battery pack capacity, (b) SOC variance at EOD and (c) SOC variance at EOC.

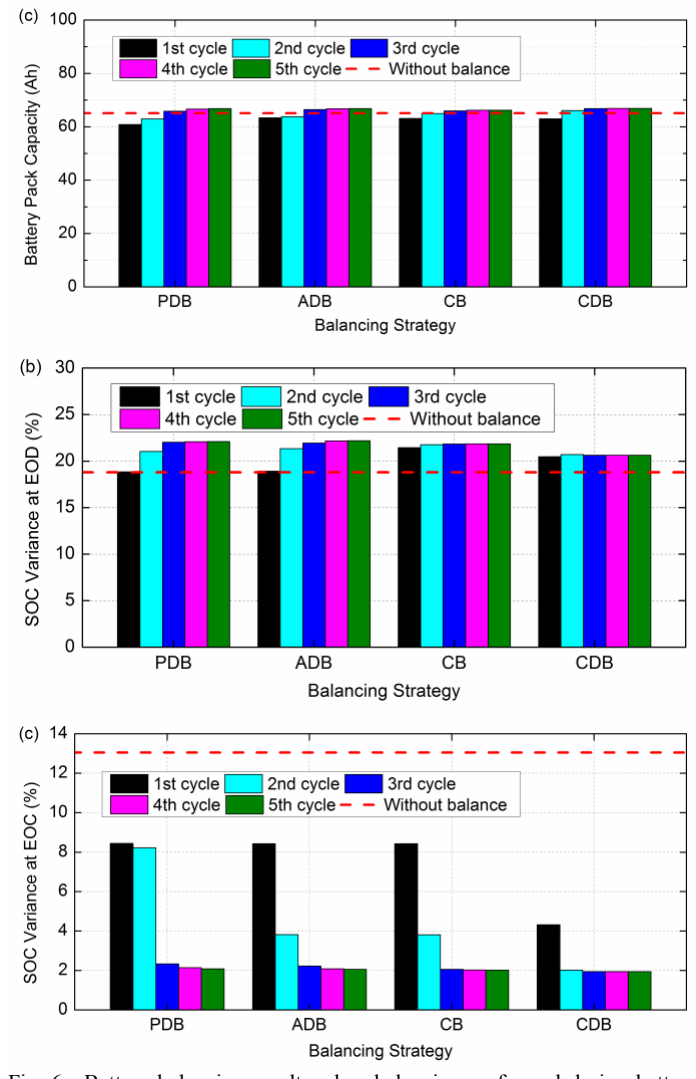
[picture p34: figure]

From above results, it can be summarized that when balancing performed during one kind of battery charge process, rest time after charge, and rest time after discharge, four mentioned-above balancing strategies are able to increase the battery pack capacity to be approximately equal to the minimum cell capacity. During the discharge processes, the PDB method would make a counterproductive balance result which decreases the battery pack capacity, while other balancing strategies can make an improvement in the battery pack capacity but cannot reach the minimum cell capacity. Besides comparing how much battery pack capacity can be increased, another important factors are SOC variances at EOC and EOD. It would decrease the SOC variance at EOD when balancing performed during battery discharge processes and rest time after discharge, and therefore the battery pack is able to be discharged more capacity. On the contrary, the SOC variance at EOC would be declined to a small value when balancing performed during battery charge processes

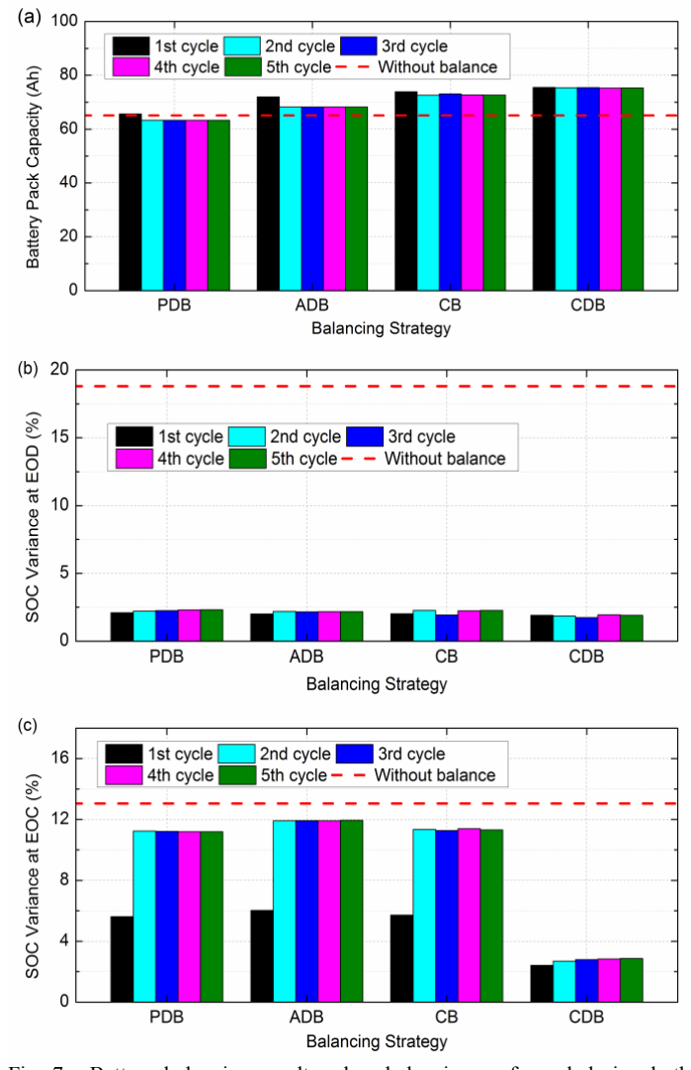
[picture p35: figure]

and rest time after charge, and therefore the battery pack can be charged more capacity.
The above balanced battery pack capacity can be maximally increased to close to the minimum cell capacity, but it is still much less than the mean battery cell capacity. To maximally utilize the battery pack capacity, namely the mean battery cell capacity, it should fully charge and discharge each cell of the battery pack. In other words, the SOC variances at both EOC and EOD should be maximally decreased to a small level, and therefore it would maximally increase the battery pack maximum available capacity. Thus, the battery balancing should be performed during both battery charge and discharge processes.
Fig. 7 shows the battery balancing results when balancing performed during both battery charge and discharge processes. In Fig. 7(a), the ADB, CB and CDB strategies are able to increase the battery pack capacity to a high value which is more than the minimum cell capacity. Especially for the CDB strategy, the battery pack capacity can be increased to 75.30

Fig. 7. Battery balancing results when balancing performed during both battery charge and discharge processes: (a) battery pack capacity, (b) SOC variance at EOD and (c) SOC variance at EOC.

Fig. 6. Battery balancing results when balancing performed during battery rest time after charge: (a) battery pack capacity, (b) SOC variance at EOD and (c) SOC variance at EOC.

Ah, which improves 15.74% compared with the capacity without balance (65.05 Ah) and is very closed to the mean battery cell capacity. It is noted that for the CDB strategy, SOC variances at EOC and EOD were able to be significantly dropped to a small level, and therefore the battery capacity of the CDB strategy is larger than other strategies. As for the PDB strategy, although SOC variances at both EOD and EOC can be declined, there was a large amount of energy consumption due to resistor bleeding during battery discharge processes, which caused the battery pack capacity decrement.

IV. | CONCLUSION

Battery balancing techniques are essentially required in BMSs for increasing battery pack capacity and prolonging battery pack service life. Regardless of balancing circuits and algorithms, when to perform balancing plays a vital role in
balancing | performance. | Performing | balancing | during
different battery operation processes would lead to various balancing effects.
In this paper, four battery balancing strategies including PDB, ADB, CB, CDB, were developed from the state-of-the-art balancing circuits and balancing algorithms for simulation experiment. During one single kind of battery charge processes, rest time after charge and rest time after discharge, four mentioned-above balancing strategies can increase the battery pack capacity to be closed to the minimum cell capacity. During the battery discharge processes, the PDB strategy would make a counterproductive balance result which decreases the battery pack capacity, while other balancing strategies can make an improvement in the battery pack capacity but cannot reach the minimum cell capacity. To maximally utilize the battery pack capacity, the SOC variances at both EOC and EOD should be maximally decreased to a small value, and therefore it would maximally increase the battery pack capacity. Performing balancing during both battery charge and discharge processes with the ADB, CB and CDB strategies can effectively increase the battery pack capacity to a higher level, which can be approximately close to the mean cell capacity.
Actual | battery | balancing | experiment | and | energy
consumption analysis during battery balancing will be investigated in the future work.

ACKNOWLEDGMENT

This work was financially supported by the Automotive Australia 2020 Cooperative Research Centre (AutoCRC).

REFERENCES

[1] Y. Zheng, M. Ouyang, L. Lu, J. Li, X. Han and L. Xu, "On-line equalization for lithium-ion battery packs based on charging cell voltages: Part 1. Equalization based on remaining charging capacity estimation," J. Power Sources, vol. 247, pp. 676-686, 2014.
[2] J. Gallardo-Lozano, E. Romero-Cadaval, M. I. Milanes-Montero and M.
A. Guerrero-Martinez, "Battery equalization active methods," J. Power Sources, vol. 246, pp. 934-949, 2014.
[3] F. Baronti, R. Roncella and R. Saletti, "Performance comparison of active balancing techniques for lithium-ion batteries," J. Power Sources, vol. 267, pp. 603-609, 2014.
[4] M. Caspar, T. Eiler and S. Hohmann, "Comparison of active battery balancing systems," in Vehicle Power and Propulsion Conference (VPPC), 2014 IEEE, 2014, pp. 1-8.
[5] S. Li; C. C. Mi and M. Zhang, "A high-efficiency active battery-
balancing | circuit | using | multiwinding | transformer." | Industry
Applications, IEEE Transactions on, vol. 49 pp. 198-207, 2013.
[6] M. Daowd; N. Omar, P. Van Den Bossche and J. Van Mierlo, "Passive and active battery balancing comparison based on MATLAB simulation." in Vehicle Power and Propulsion Conference (VPPC), 2011 IEEE, 2011, pp. 1-7.
[7] F. Mestrallet, L. Kerachev, J. Crebier and A. Collet, "Multiphase interleaved converter for lithium battery active balancing," Power Electronics, IEEE Transactions On, vol. 29, pp. 2874-2881, 2014.
[8] C. H. Kim, M. Y. Kim; H. S. Park and G. W. Moon, "A modularized two-stage charge equalizer with cell selection switches for series-connected lithium-ion battery string in an HEV." Power Electronics, IEEE Transactions on, vol. 27, pp. 3764-3774, 2012.
[9] Y. S. Lee and M. W. Cheng, "Intelligent control battery equalization for series connected lithium-ion battery strings." Industrial Electronics, IEEE Transactions on, vol. 52, pp. 1297-1307, 2005.
[10] M. Daowd; N. Omar, P. Van Den Bossche and J. Van Mierlo, "A review of passive and active battery balancing based on MATLAB/Simulink." J. Int. Rev. Electr. Eng, vol. 6, pp. 2974-2989, 2011.
[11] W. Huang and J. A. Abu Qahouq. "Energy sharing control scheme for state-of-charge balancing of distributed battery energy storage system." Industrial Electronics, IEEE Transactions on, vol. 62, pp. 2764-2776, 2015.
[12] R. Ugle, Y. Li and A. Dhingra, "Equalization integrated online monitoring of health map and worthiness of replacement for battery pack of electric vehicles." J. Power Sources, vol. 223, pp. 293-305, 2013.
[13] J. Gallardo-Lozano, E. Romero-Cadaval, M. I. Milanes-Montero and M.
A. Guerrero-Martinez, "A novel active battery equalization control with on-line unhealthy cell detection and cell change decision," J. Power Sources, vol. 299, pp. 356-370, 2015.
[14] Y. Wang, C. Zhang, Z. Chen, J. Xie and X. Zhang, "A novel active equalization method for lithium-ion batteries in electric vehicles," Appl. Energy, vol. 145, pp. 36-42, 2015.
[15] United States Advanced Battery Consortium, "Electric vehicle battery test procedures manual." USABC, Jan 1996.

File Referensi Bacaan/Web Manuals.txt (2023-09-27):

https://www.analog.com/en/products/ltc6803-2.html

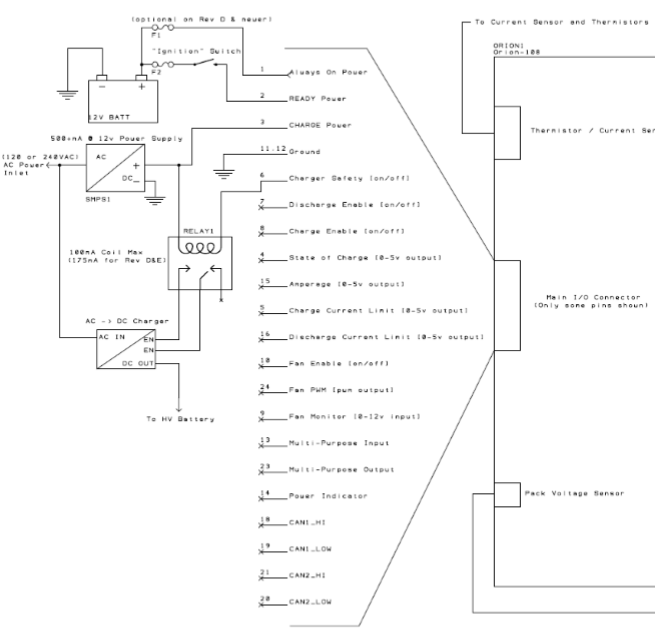
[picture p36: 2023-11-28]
Referensi Desain Sebelumnya/BMS Orion/wiring charger.png

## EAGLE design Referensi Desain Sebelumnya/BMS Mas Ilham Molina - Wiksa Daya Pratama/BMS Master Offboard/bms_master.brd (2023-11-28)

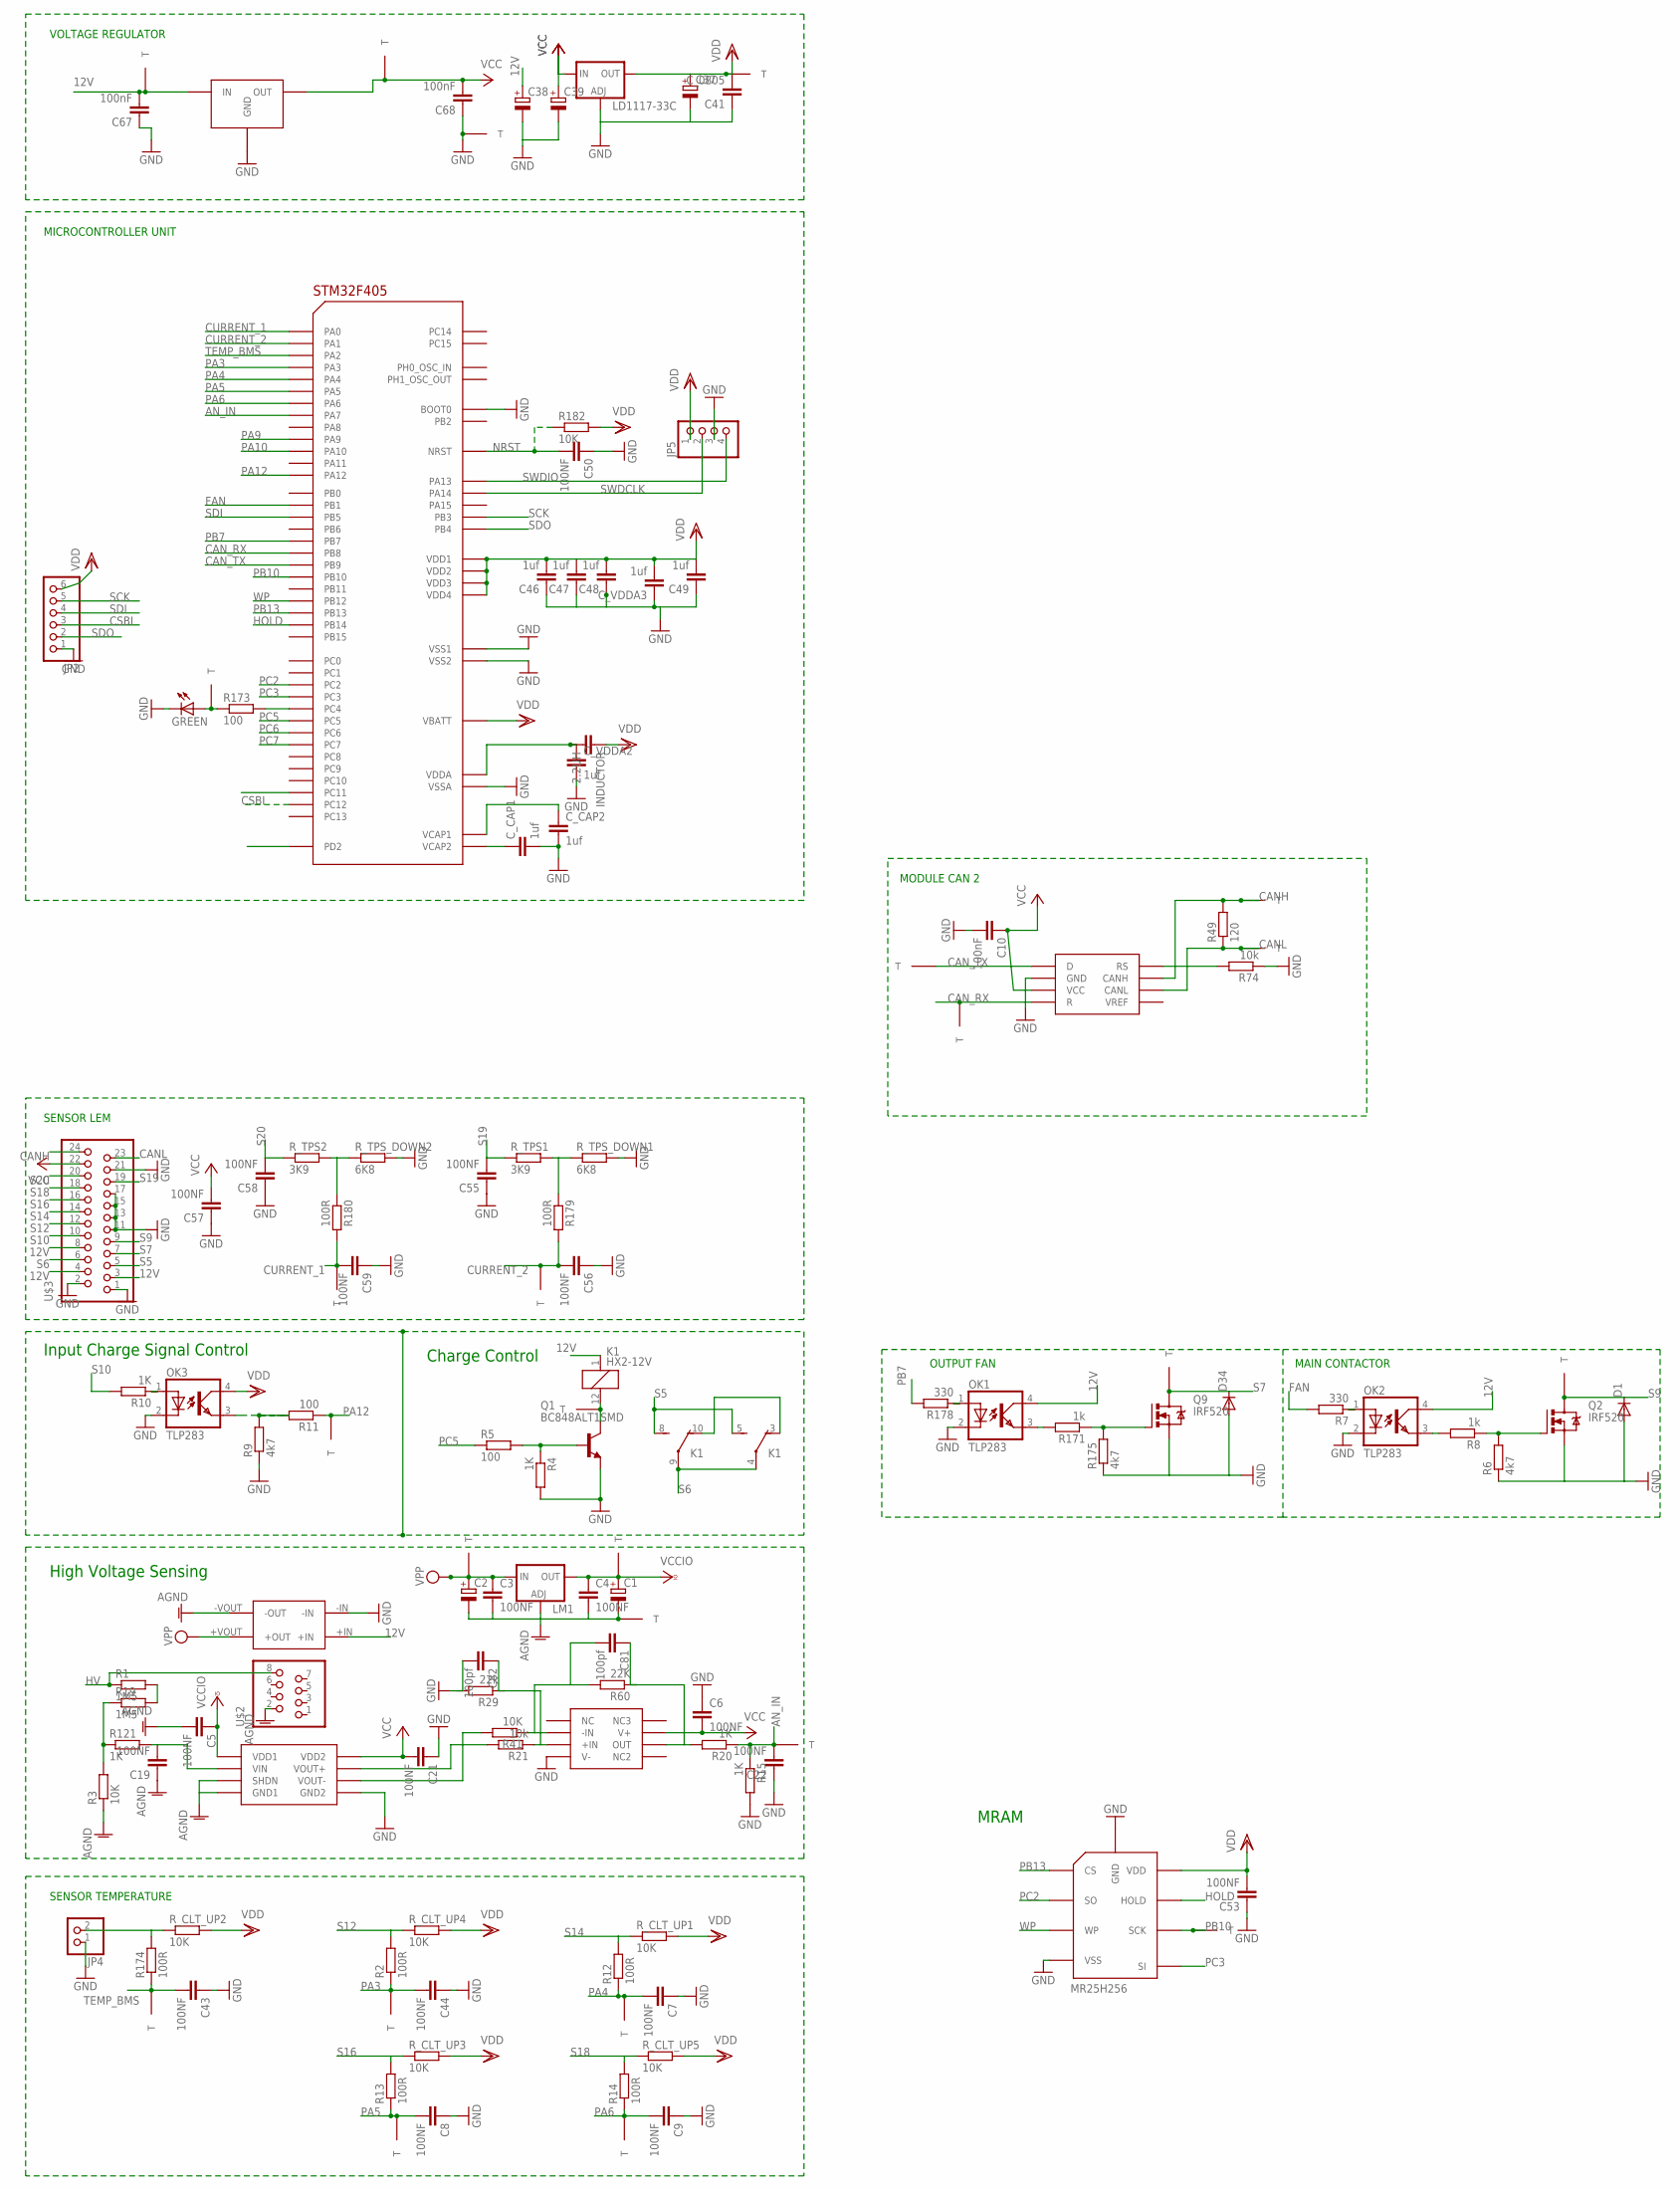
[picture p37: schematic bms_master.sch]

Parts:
C1, C37, C39: CPOL-EU153CLV-0605; 153CLV-0605
C2, C38: CPOL-EU153CLV-0810; 153CLV-0810
C3, C4, C5, C6, C7, C8, C9, C19, C21, C22, C43, C44, C50, C53, C55, C56, C57, C58, C59: 100NF; C_0805
C10, C67, C68: 100nF; C_0805
C41: C_0805
C46, C47, C48, C49: 1uf; C_0805
C81, C82: 100pf; C_0805
C_CAP1, C_CAP2: 1uf; C_0805
C_VDDA2, C_VDDA3: 1uf; C_0805
D1, D34: DIODE-SOD80C; SOD80C
GREEN: LED3MM
INDUCTOR: 2.2UH; C0805K
JP2: PINHD-1X6; 1X06
JP4: PINHD-1X2/90; 1X02/90
JP5: PINHD-1X4; 1X04
K1: HX2-12V; HX
LD1117-33C: LM317MABDT; DPACK@1
LM1: LM317MABDT; DPACK@1
OK1, OK2, OK3: TLP283; MINI-FLAT-4
Q1: BC848ALT1SMD; SOT23
Q2, Q9: IRF520; D-PAK_TO252AA
R1, R19: 1M5; R1210
R2, R12, R13, R14, R174, R179, R180: 100R; R_0805
R3: 10K; R1210
R4, R10, R15, R20: 1K; R_0805
R5, R11, R173: 100; R_0805
R6, R9, R175: 4k7; R_0805
R7, R178: 330; R_0805
R8, R171: 1k; R_0805
R21, R74: 10k; R_0805
R29: 22k; R_0805
R41, R182: 10K; R_0805
R49: 120; 0207/7
R60: 22K; R_0805
R121: 1K; R_1210
R_CLT_UP1, R_CLT_UP2, R_CLT_UP3, R_CLT_UP4, R_CLT_UP5: 10K; R_0805
R_TPS1, R_TPS2: 3K9; R_0805
R_TPS_DOWN1, R_TPS_DOWN2: 6K8; R_0805
U8: MCP2551; SN65HVD230
U$1: NWD5-12; NWD5
U$2: SOCKET8P; 8PIN
U$3: SOCKET24P; 24PIN
U$4, U$5, U$6, U$7, U$8, U$10, U$11, U$12, U$13, U$14, U$15, U$16, U$17, U$18, U$19, U$20, U$21, U$22, U$23, U$24, U$25, U$26, U$27, U$28, U$35: TESTPOINT
U$9: ACPL-C87B; STRETCHSO8
U$29: OKI-78SR-5; MDC_OKI
U$31: STM32F405; TQFP64
U$32: MR25H256; 8DFN
U$70: OPA237; SO-08

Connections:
12V: C38.+, C67.2, K1.1, OK1.4 (COL), OK2.4 (COL), U$1.+IN, U$3.3, U$3.4, U$3.8, U$5.P$1, U$29.1 (IN)
AGND: C1.-, C2.-, C3.2, C4.2, C5.2, C19.1, LM1.1 (ADJ), R3.1, U$1.-VOUT (-OUT), U$2.2, U$9.P$3 (SHDN), U$9.P$4 (GND1), U$20.P$1
AN_IN: C22.2, R15.1, R20.1, U$22.P$1, U$31.23 (PA7)
CANH: R49.2, U8.P$7 (CANH), U$3.24, U$12.P$1
CANL: R49.1, U8.P$6 (CANL), U$3.23, U$11.P$1
CAN_RX: U8.P$4 (R), U$8.P$1, U$31.61 (PB8)
CAN_TX: U8.P$1 (D), U$10.P$1, U$31.62 (PB9)
CSBI: JP2.3, U$31.53 (PC12)
CURRENT_1: C59.2, R180.2, U$14.P$1, U$31.14 (PA0)
CURRENT_2: C56.2, R179.2, U$13.P$1, U$31.15 (PA1)
FAN: R7.2, U$31.27 (PB1)
GND: C6.1, C7.1, C8.1, C9.1, C10.2, C21.1, C22.1, C37.-, C38.-, C39.-, C41.1, C43.1, C44.1, C46.1, C47.1, C48.1, C49.1, C50.1, C53.1, C55.1, C56.1, C57.1, C58.1, C59.1, C67.1, C68.1, C82.2, C_CAP1.2, C_CAP2.2, C_VDDA2.2, C_VDDA3.1, D1.A, D34.A, GREEN.K (C), JP2.1, JP4.1, JP5.3, LD1117-33C.1 (ADJ), OK1.2 (C), OK2.2 (C), OK3.2 (C), Q1.2 (E), Q2.1 (S), Q9.1 (S), R4.2, R6.1, R9.1, R15.2, R29.2, R74.1, R175.1, R_TPS_DOWN1.2, R_TPS_DOWN2.2, U8.P$2 (GND), U$1.-IN, U$3.1, U$3.2, U$3.11, U$3.13, U$3.15, U$3.17, U$3.21, U$4.P$1, U$9.P$5 (GND2), U$29.2 (GND), U$31.12 (VSSA), U$31.18 (VSS1), U$31.60 (BOOT0), U$31.63 (VSS2), U$32.P$4 (VSS), U$32.P$9 (GND), U$70.4 (V-)
HOLD: U$31.35 (PB14), U$32.P$7 (HOLD)
HV: R1.1, U$2.8
unnamed: Q2.3 (G), R6.2, R8.1
unnamed: K1.12 (2), Q1.3 (C), U$16.P$1
unnamed: OK2.1 (A), R7.1
unnamed: C19.2, R121.2, U$9.P$2 (VIN)
unnamed: OK2.3 (EMIT), R8.2
unnamed: R21.2, U$9.P$7 (VOUT+)
unnamed: Q1.1 (B), R4.1, R5.2
unnamed: K1.3 (O), K1.10 (O)
unnamed: C81.2, R41.1, R60.2, U$70.2 (-IN)
unnamed: R41.2, U$9.P$6 (VOUT-)
unnamed: OK3.1 (A), R10.1
unnamed: C82.1, R21.1, R29.1, U$70.3 (+IN)
unnamed: OK3.3 (EMIT), R9.2, R11.2
unnamed: R3.2, R19.1, R121.1
unnamed: R74.2, U8.P$8 (RS)
unnamed: R1.2, R19.2
unnamed: C_CAP1.1, U$31.47 (VCAP2)
unnamed: C_CAP2.1, U$31.31 (VCAP1)
unnamed: R173.2, U$31.24 (PC4)
unnamed: GREEN.A, R173.1, U$7.P$1
unnamed: JP4.2, R174.2, R_CLT_UP2.1
unnamed: R179.1, R_TPS1.2, R_TPS_DOWN1.1
unnamed: R180.1, R_TPS2.2, R_TPS_DOWN2.1
unnamed: Q9.3 (G), R171.1, R175.2
unnamed: OK1.1 (A), R178.1
unnamed: OK1.3 (EMIT), R171.2
unnamed: C_VDDA2.1, INDUCTOR.2, U$31.13 (VDDA)
NRST: C50.2, R182.1, U$31.7 (NRST)
PA3: C44.2, R2.1, U$24.P$1, U$31.17 (PA3)
PA4: C7.2, R12.1, U$27.P$1, U$31.20 (PA4)
PA5: C8.2, R13.1, U$25.P$1, U$31.21 (PA5)
PA6: C9.2, R14.1, U$26.P$1, U$31.22 (PA6)
PA9: U$31.42 (PA9)
PA10: U$31.43 (PA10)
PA12: R11.1, U$15.P$1, U$31.45 (PA12)
PB7: R178.2, U$31.59 (PB7)
PB10: U$28.P$1, U$31.29 (PB10), U$32.P$6 (SCK)
PB13: U$31.34 (PB13), U$32.P$1 (CS)
PC2: U$31.10 (PC2), U$32.P$2 (SO)
PC3: U$31.11 (PC3), U$32.P$5 (SI)
PC5: R5.1, U$31.25 (PC5)
PC6: U$31.37 (PC6)
PC7: U$31.38 (PC7)
S5: K1.5 (S), K1.8 (S), U$3.5
S6: K1.4, K1.9, U$3.6
S7: D34.C, Q9.4 (D), U$3.7, U$17.P$1
S9: D1.C, Q2.4 (D), U$3.9, U$18.P$1
S10: R10.2, U$3.10
S12: R2.2, R_CLT_UP4.1, U$3.12
S14: R12.2, R_CLT_UP1.1, U$3.14
S16: R13.2, R_CLT_UP3.1, U$3.16
S18: R14.2, R_CLT_UP5.1, U$3.18
S19: C55.2, R_TPS1.1, U$3.19
S20: C58.2, R_TPS2.1, U$3.20
SCK: JP2.5, U$31.55 (PB3)
SDI: JP2.4, U$31.57 (PB5)
SDO: JP2.2, U$31.56 (PB4)
SWDCLK: JP5.2, U$31.49 (PA14)
SWDIO: JP5.4, U$31.46 (PA13)
TEMP_BMS: C43.2, R174.1, U$23.P$1, U$31.16 (PA2)
VCC: C6.2, C10.1, C21.2, C39.+, C57.2, C68.2, LD1117-33C.3 (IN), U8.P$3 (VCC), U$3.22, U$9.P$8 (VDD2), U$29.3 (OUT), U$35.P$1, U$70.7 (V+)
VCCIO: C1.+, C4.1, C5.1, LM1.4 (OUT), U$9.P$1 (VDD1), U$19.P$1
VDD: C37.+, C41.2, C46.2, C47.2, C48.2, C49.2, C53.2, C_VDDA3.2, INDUCTOR.1, JP2.6, JP5.1, LD1117-33C.4 (OUT), OK3.4 (COL), R182.2, R_CLT_UP1.2, R_CLT_UP2.2, R_CLT_UP3.2, R_CLT_UP4.2, R_CLT_UP5.2, U$6.P$1, U$31.1 (VBATT), U$31.19 (VDD1), U$31.32 (VDD2), U$31.48 (VDD3), U$31.64 (VDD4), U$32.P$8 (VDD)
VPP: C2.+, C3.1, LM1.3 (IN), U$1.+VOUT (+OUT), U$21.P$1
WP: U$31.33 (PB12), U$32.P$3 (WP)
Y: C81.1, R20.2, R60.1, U$70.6 (OUT)

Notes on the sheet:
VOLTAGE REGULATOR
MICROCONTROLLER UNIT
SENSOR TEMPERATURE
SENSOR LEM
MRAM
High Voltage Sensing
Charge Control
OUTPUT FAN
MAIN CONTACTOR
Input Charge Signal Control
MODULE CAN 2

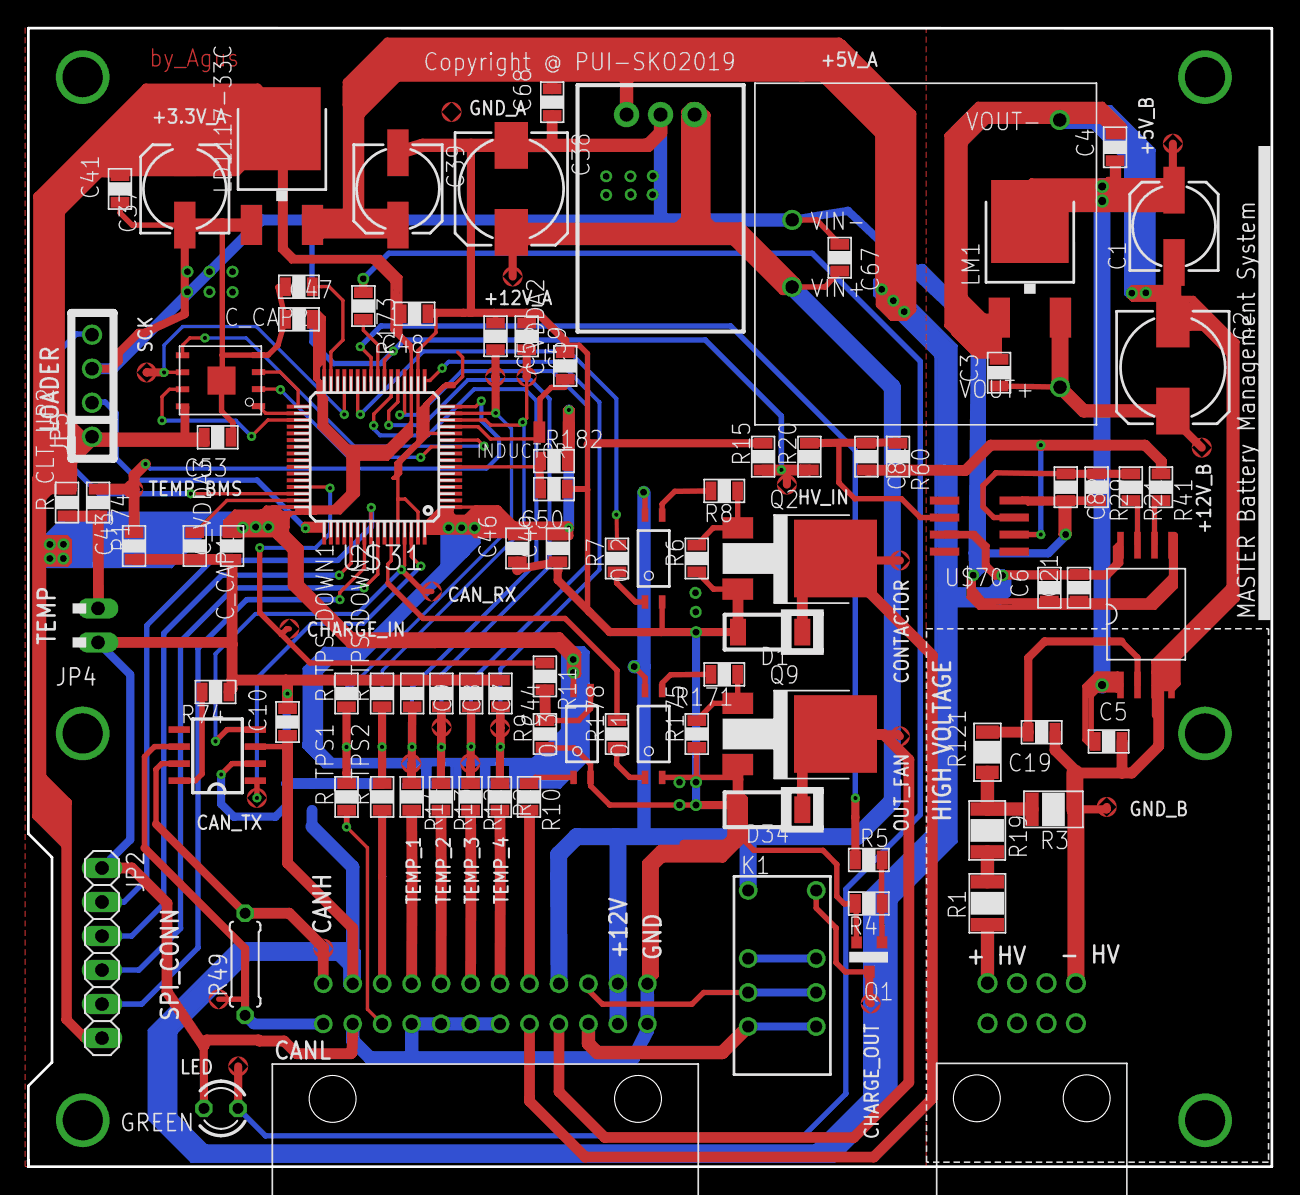
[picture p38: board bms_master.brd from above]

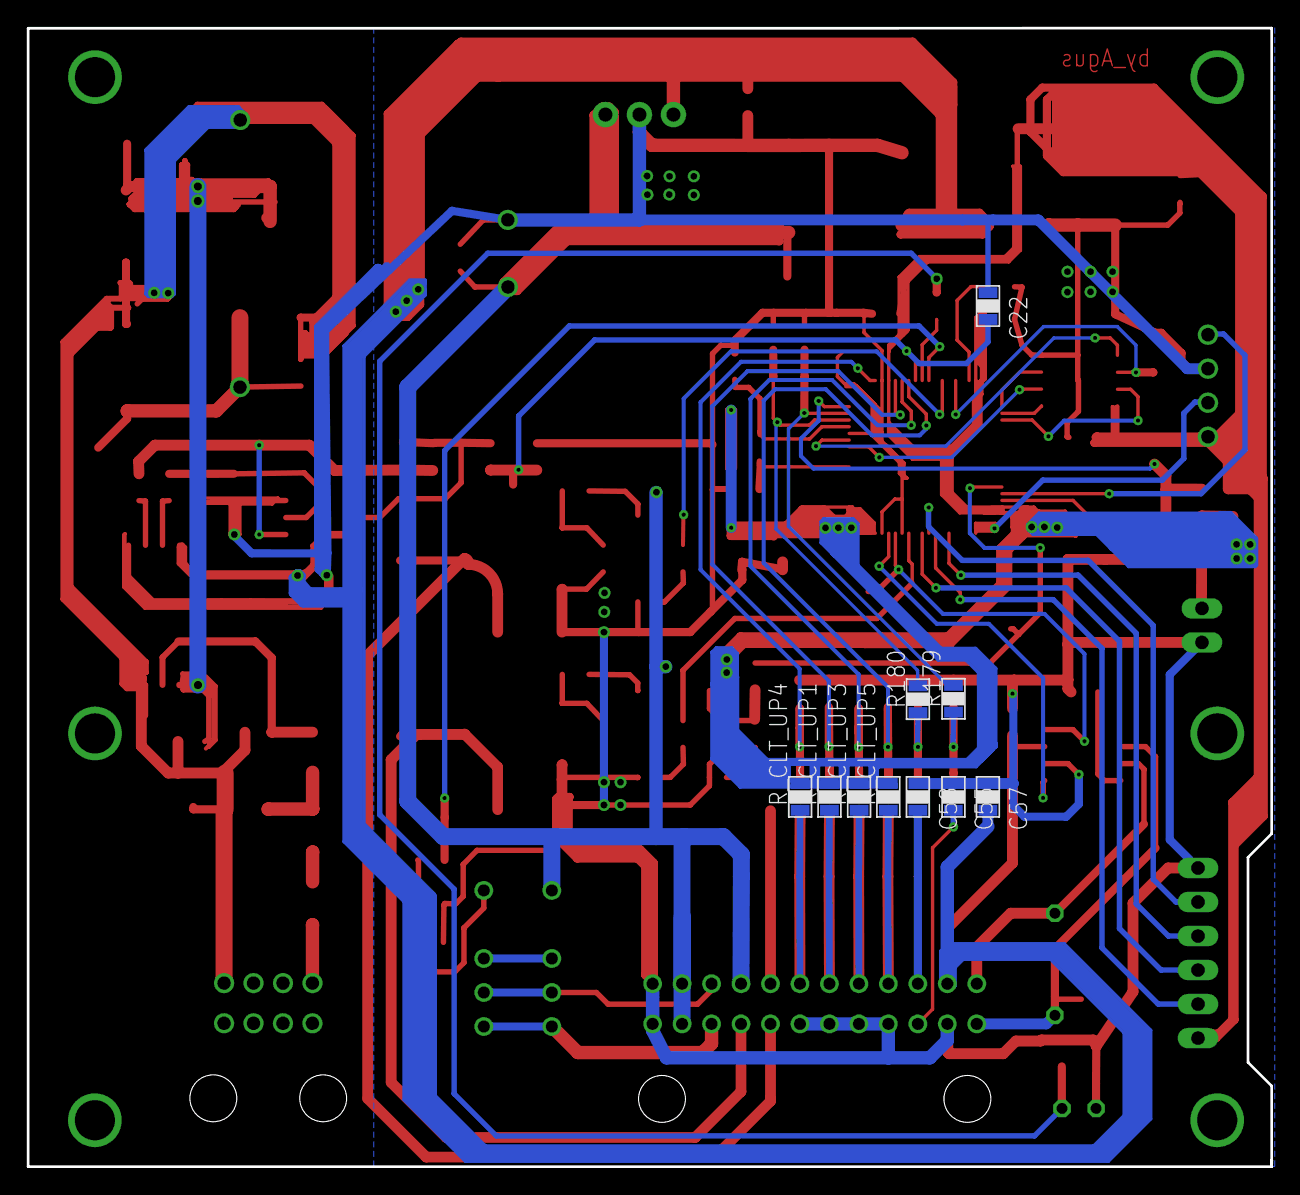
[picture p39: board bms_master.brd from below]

Board: 2 copper layers, 92.9 x 85.0 mm, 129 parts (10 on the bottom side), 76 nets.

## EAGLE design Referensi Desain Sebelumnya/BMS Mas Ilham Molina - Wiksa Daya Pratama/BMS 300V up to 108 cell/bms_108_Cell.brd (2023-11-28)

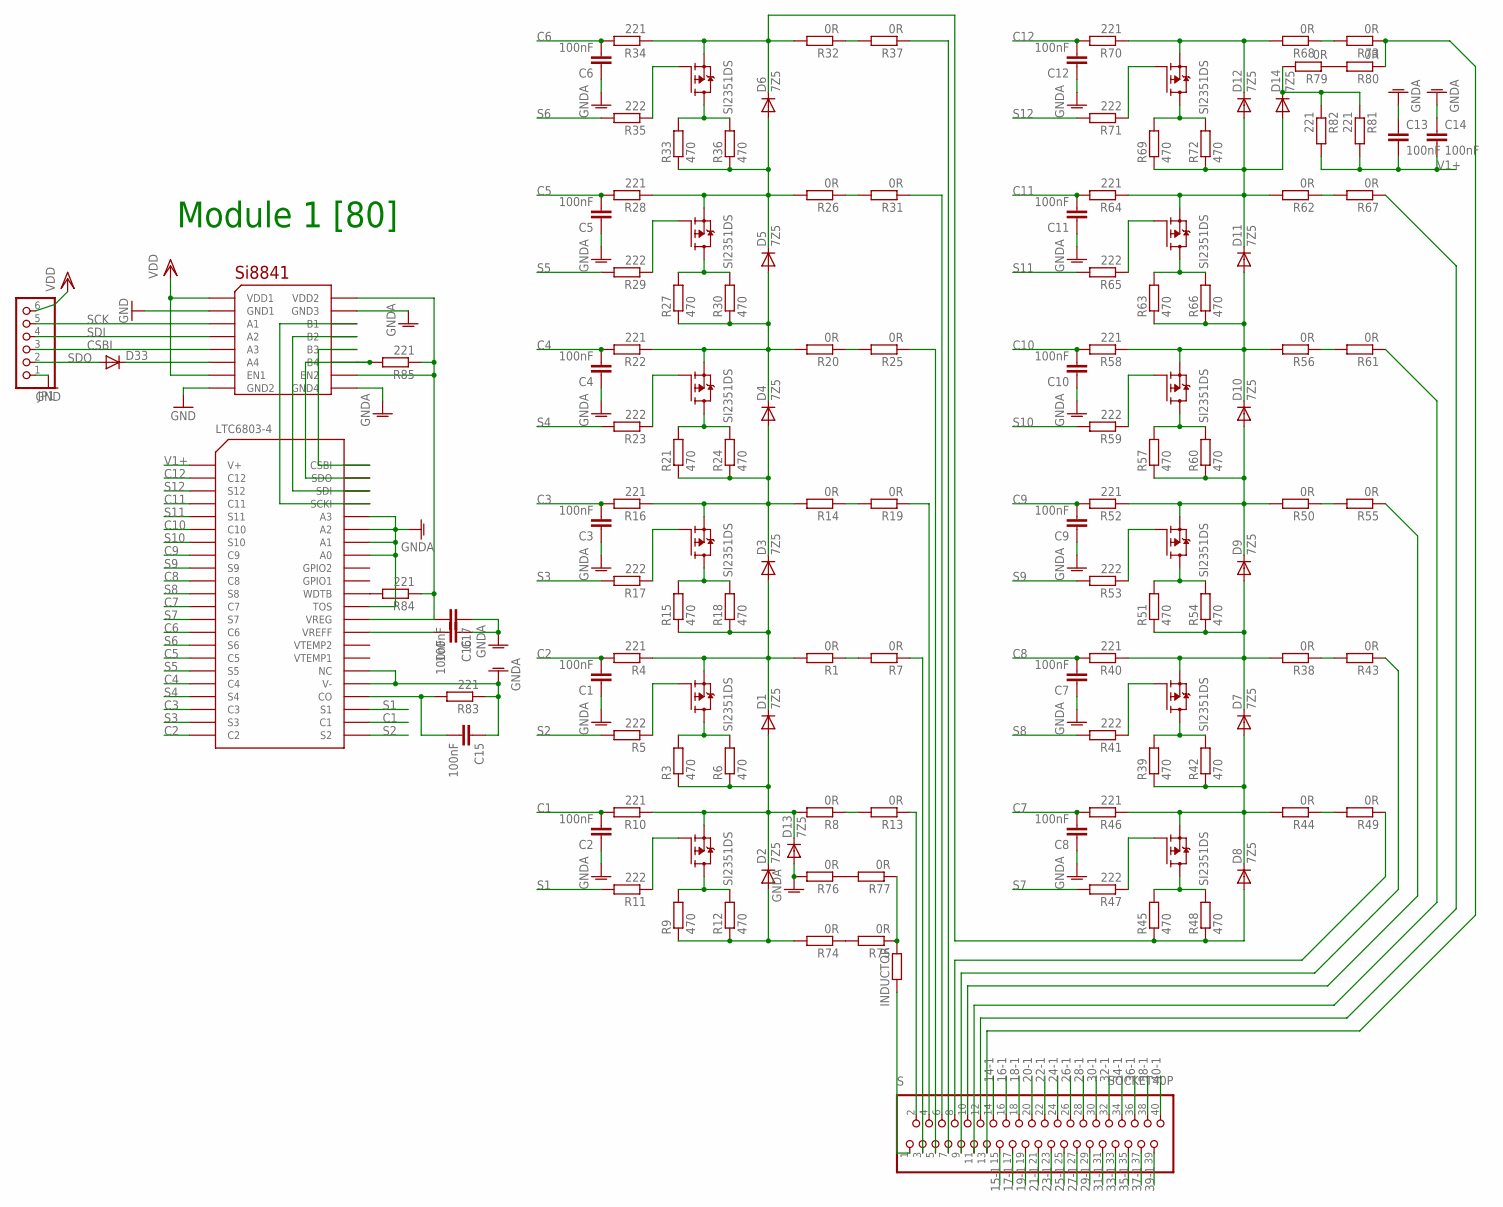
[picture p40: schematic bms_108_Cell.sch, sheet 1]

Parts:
C1, C2, C3, C4, C5, C6, C7, C8, C9, C10, C11, C12, C13, C14, C15, C16, C17: 100nF; C0805K
D1, D2, D3, D4, D5, D6, D7, D8, D9, D10, D11, D12, D13, D14: 7Z5; SMB
D33: DIODE-SOD123; SOD123
JP1: PINHD-1X6; 1X06
R1, R7, R8, R13, R14, R19, R20, R25, R26, R31, R32, R37, R38, R43, R44, R49, R50, R55, R56, R61, R62, R67, R68, R73, R74, R75, R76, R77, R79, R80: 0R; M1206
R3, R6, R9, R12, R15, R18, R21, R24, R27, R30, R33, R36, R39, R42, R45, R48, R51, R54, R57, R60, R63, R66, R69, R72: 470; R6332
R4, R10, R16, R22, R28, R34, R40, R46, R52, R58, R64, R70, R81, R82, R83, R84, R85: 221; R0805
R5, R11, R17, R23, R29, R35, R41, R47, R53, R59, R65, R71: 222; R0805
S: SOCKET40P; 40PIN
U$1: LTC6803-4; SSOP44
U$2: SI8841; SO16
U$3, U$4, U$5, U$6, U$7, U$8, U$9, U$10, U$11, U$12, U$13, U$14: SI2351DS; SOT23
U$15: INDUCTOR; L2012C

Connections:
14-1: S.14; also elsewhere on the board
15-1: S.15; also elsewhere on the board
16-1: S.16; also elsewhere on the board
17-1: S.17; also elsewhere on the board
18-1: S.18; also elsewhere on the board
19-1: S.19; also elsewhere on the board
20-1: S.20; also elsewhere on the board
21-1: S.21; also elsewhere on the board
22-1: S.22; also elsewhere on the board
23-1: S.23; also elsewhere on the board
24-1: S.24; also elsewhere on the board
25-1: S.25; also elsewhere on the board
26-1: S.26; also elsewhere on the board
27-1: S.27
28-1: S.28; also elsewhere on the board
29-1: S.29; also elsewhere on the board
30-1: S.30; also elsewhere on the board
31-1: S.31; also elsewhere on the board
32-1: S.32; also elsewhere on the board
33-1: S.33; also elsewhere on the board
34-1: S.34; also elsewhere on the board
35-1: S.35; also elsewhere on the board
36-1: S.36; also elsewhere on the board
37-1: S.37; also elsewhere on the board
38-1: S.38; also elsewhere on the board
39-1: S.39; also elsewhere on the board
40-1: S.40; also elsewhere on the board
C1: C2.2, R10.2, U$1.24 (C1)
C2: C1.2, R4.2, U$1.P$22 (C2)
C3: C3.2, R16.2, U$1.P$20 (C3)
C4: C4.2, R22.2, U$1.P$18 (C4)
C5: C5.2, R28.2, U$1.P$16 (C5)
C6: C6.2, R34.2, U$1.P$14 (C6)
C7: C8.2, R46.2, U$1.P$12 (C7)
C8: C7.2, R40.2, U$1.P$10 (C8)
C9: C9.2, R52.2, U$1.P$8 (C9)
C10: C10.2, R58.2, U$1.P$6 (C10)
C11: C11.2, R64.2, U$1.P$4 (C11)
C12: C12.2, R70.2, U$1.P$2 (C12)
CSBI: JP1.3, U$2.5 (A3); also elsewhere on the board
GND: JP1.1, U$2.2 (GND1), U$2.8 (GND2); also elsewhere on the board
GNDA: C1.1, C2.1, C3.1, C4.1, C5.1, C6.1, C7.1, C8.1, C9.1, C10.1, C11.1, C12.1, C13.1, C14.1, C15.1, C16.1, C17.1, D13.A, R76.2, R83.1, U$1.27 (V-), U$1.28 (NC), U$1.33 (TOS), U$1.37 (A0), U$1.38 (A1), U$1.39 (A2), U$1.40 (A3), U$2.9 (GND4), U$2.15 (GND3)
unnamed: R5.1, U$3.1 (G)
unnamed: R74.1, R75.2
unnamed: R3.2, R6.2, U$3.3 (D)
unnamed: D1.A, D2.C, D13.C, R3.1, R6.1, R8.2, R10.1, U$4.2 (S)
unnamed: R41.1, U$9.1 (G)
unnamed: R29.1, U$7.1 (G)
unnamed: R23.1, U$6.1 (G)
unnamed: R21.2, R24.2, U$6.3 (D)
unnamed: R1.1, R7.2
unnamed: R11.1, U$4.1 (G)
unnamed: R9.2, R12.2, U$4.3 (D)
unnamed: R76.1, R77.2
unnamed: D3.C, D4.A, R14.2, R16.1, R21.1, R24.1, U$5.2 (S)
unnamed: R8.1, R13.2
unnamed: R27.2, R30.2, U$7.3 (D)
unnamed: R17.1, U$5.1 (G)
unnamed: R15.2, R18.2, U$5.3 (D)
unnamed: D1.C, D3.A, R1.2, R4.1, R15.1, R18.1, U$3.2 (S)
unnamed: R20.1, R25.2
unnamed: R14.1, R19.2
unnamed: D4.C, D5.A, R20.2, R22.1, R27.1, R30.1, U$6.2 (S)
unnamed: R26.1, R31.2
unnamed: R75.1, R77.1, U$15.1
unnamed: R35.1, U$8.1 (G)
unnamed: R33.2, R36.2, U$8.3 (D)
unnamed: D5.C, D6.A, R26.2, R28.1, R33.1, R36.1, U$7.2 (S)
unnamed: R32.1, R37.2
unnamed: R39.2, R42.2, U$9.3 (D)
unnamed: D7.A, D8.C, R39.1, R42.1, R44.2, R46.1, U$10.2 (S)
unnamed: R38.1, R43.2
unnamed: R47.1, U$10.1 (G)
unnamed: R45.2, R48.2, U$10.3 (D)
unnamed: D6.C, D8.A, R32.2, R34.1, R45.1, R48.1, U$8.2 (S)
unnamed: R44.1, R49.2
unnamed: R53.1, U$11.1 (G)
unnamed: R51.2, R54.2, U$11.3 (D)
unnamed: D7.C, D9.A, R38.2, R40.1, R51.1, R54.1, U$9.2 (S)
unnamed: R50.1, R55.2
unnamed: D2.A, R9.1, R12.1, R74.2
unnamed: R59.1, U$12.1 (G)
unnamed: R57.2, R60.2, U$12.3 (D)
unnamed: D9.C, D10.A, R50.2, R52.1, R57.1, R60.1, U$11.2 (S)
unnamed: R56.1, R61.2
unnamed: R65.1, U$13.1 (G)
unnamed: R63.2, R66.2, U$13.3 (D)
unnamed: D10.C, D11.A, R56.2, R58.1, R63.1, R66.1, U$12.2 (S)
unnamed: R62.1, R67.2
unnamed: D12.C, R68.2, R70.1, U$14.2 (S)
unnamed: R71.1, U$14.1 (G)
unnamed: R69.2, R72.2, U$14.3 (D)
unnamed: D11.C, D12.A, D14.A, R62.2, R64.1, R69.1, R72.1, U$13.2 (S)
unnamed: R68.1, R73.2
unnamed: R85.2, U$1.43 (SDO), U$2.11 (B4)
unnamed: R79.1, R80.2
unnamed: C15.2, R83.2, U$1.26 (CO)
unnamed: D14.C, R79.2, R81.1, R82.1
unnamed: R73.1, R80.1, S.13
unnamed: C16.2, U$1.31 (VREFF)
unnamed: C17.2, R84.1, R85.1, U$1.32 (VREG), U$2.10 (EN2), U$2.16 (VDD2)
unnamed: U$1.41 (SCKI), U$2.14 (B1)
unnamed: R84.2, U$1.34 (WDTB)
unnamed: U$1.44 (CSBI), U$2.12 (B3)
unnamed: U$1.42 (SDI), U$2.13 (B2)
unnamed: S.1, U$15.2
unnamed: R13.1, S.2
unnamed: R7.1, S.3
unnamed: R19.1, S.4
unnamed: R25.1, S.5
unnamed: R31.1, S.6
unnamed: R37.1, S.7
unnamed: R49.1, S.8
unnamed: R43.1, S.9
unnamed: R55.1, S.10
unnamed: R61.1, S.11
unnamed: R67.1, S.12
unnamed: D33.C, U$2.6 (A4)
S1: R11.2, U$1.25 (S1)
S2: R5.2, U$1.23 (S2)
S3: R17.2, U$1.P$21 (S3)
S4: R23.2, U$1.P$19 (S4)
S5: R29.2, U$1.P$17 (S5)
S6: R35.2, U$1.P$15 (S6)
S7: R47.2, U$1.P$13 (S7)
S8: R41.2, U$1.P$11 (S8)
S9: R53.2, U$1.P$9 (S9)
S10: R59.2, U$1.P$7 (S10)
S11: R65.2, U$1.P$5 (S11)
S12: R71.2, U$1.P$3 (S12)
SCK: JP1.5, U$2.3 (A1); also elsewhere on the board
SDI: JP1.4, U$2.4 (A2); also elsewhere on the board
SDO: D33.A, JP1.2; also elsewhere on the board
V1+: C13.2, C14.2, R81.2, R82.2, U$1.P$1 (V+)
VDD: JP1.6, U$2.1 (VDD1), U$2.7 (EN1); also elsewhere on the board

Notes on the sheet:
Module 1 [80]

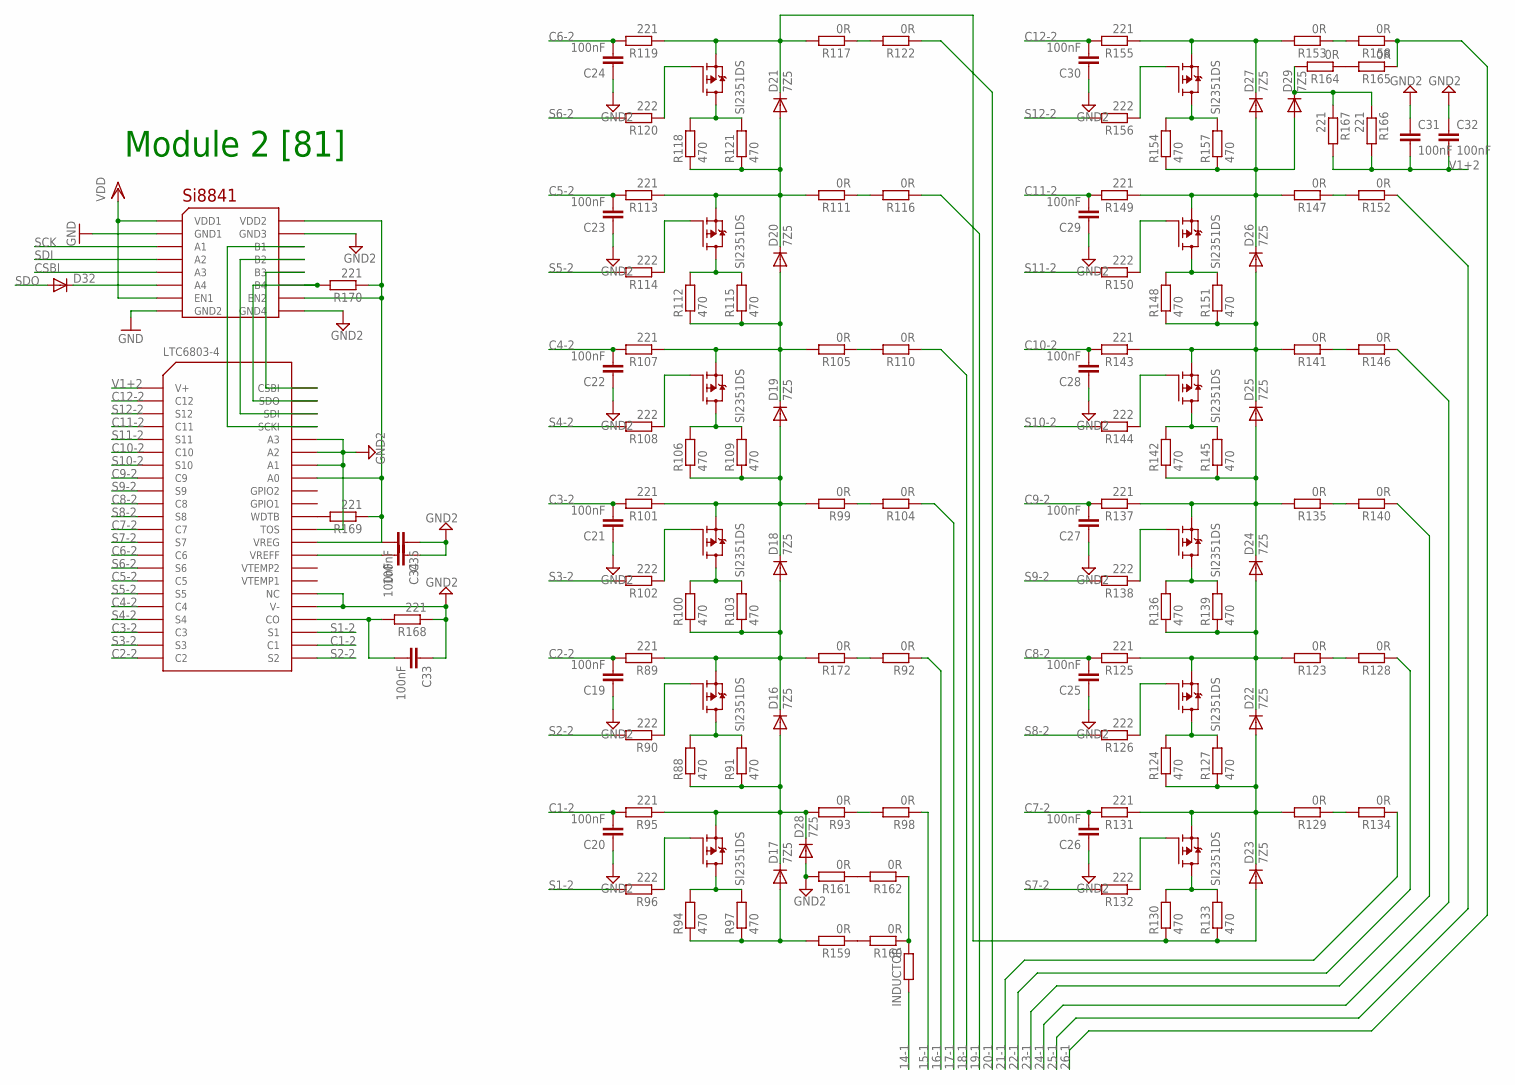
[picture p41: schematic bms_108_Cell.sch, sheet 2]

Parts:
C19, C20, C21, C22, C23, C24, C25, C26, C27, C28, C29, C30, C31, C32, C33, C34, C35: 100nF; C0805K
D16, D17, D18, D19, D20, D21, D22, D23, D24, D25, D26, D27, D28, D29: 7Z5; SMB
D32: DIODE-SOD123; SOD123
R88, R91, R94, R97, R100, R103, R106, R109, R112, R115, R118, R121, R124, R127, R130, R133, R136, R139, R142, R145, R148, R151, R154, R157: 470; R6332
R89, R95, R101, R107, R113, R119, R125, R131, R137, R143, R149, R155, R166, R167, R168, R169, R170: 221; R0805
R90, R96, R102, R108, R114, R120, R126, R132, R138, R144, R150, R156: 222; R0805
R92, R93, R98, R99, R104, R105, R110, R111, R116, R117, R122, R123, R128, R129, R134, R135, R140, R141, R146, R147, R152, R153, R158, R159, R160, R161, R162, R164, R165, R172: 0R; M1206
U$16: LTC6803-4; SSOP44
U$17: SI8841; SO16
U$18, U$19, U$20, U$21, U$22, U$23, U$24, U$25, U$26, U$27, U$28, U$29: SI2351DS; SOT23
U$30: INDUCTOR; L2012C

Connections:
14-1: U$30.2; also elsewhere on the board
15-1: R98.1; also elsewhere on the board
16-1: R92.1; also elsewhere on the board
17-1: R104.1; also elsewhere on the board
18-1: R110.1; also elsewhere on the board
19-1: R116.1; also elsewhere on the board
20-1: R122.1; also elsewhere on the board
21-1: R134.1; also elsewhere on the board
22-1: R128.1; also elsewhere on the board
23-1: R140.1; also elsewhere on the board
24-1: R146.1; also elsewhere on the board
25-1: R152.1; also elsewhere on the board
26-1: R158.1, R165.1; also elsewhere on the board
C1-2: C20.2, R95.2, U$16.24 (C1)
C2-2: C19.2, R89.2, U$16.P$22 (C2)
C3-2: C21.2, R101.2, U$16.P$20 (C3)
C4-2: C22.2, R107.2, U$16.P$18 (C4)
C5-2: C23.2, R113.2, U$16.P$16 (C5)
C6-2: C24.2, R119.2, U$16.P$14 (C6)
C7-2: C26.2, R131.2, U$16.P$12 (C7)
C8-2: C25.2, R125.2, U$16.P$10 (C8)
C9-2: C27.2, R137.2, U$16.P$8 (C9)
C10-2: C28.2, R143.2, U$16.P$6 (C10)
C11-2: C29.2, R149.2, U$16.P$4 (C11)
C12-2: C30.2, R155.2, U$16.P$2 (C12)
CSBI: U$17.5 (A3); also elsewhere on the board
GND: U$17.2 (GND1), U$17.8 (GND2); also elsewhere on the board
GND2: C19.1, C20.1, C21.1, C22.1, C23.1, C24.1, C25.1, C26.1, C27.1, C28.1, C29.1, C30.1, C31.1, C32.1, C33.1, C34.1, C35.1, D28.A, R161.2, R168.1, U$16.27 (V-), U$16.28 (NC), U$16.33 (TOS), U$16.38 (A1), U$16.39 (A2), U$16.40 (A3), U$17.9 (GND4), U$17.15 (GND3)
unnamed: R90.1, U$18.1 (G)
unnamed: R88.2, R91.2, U$18.3 (D)
unnamed: D16.A, D17.C, D28.C, R88.1, R91.1, R93.2, R95.1, U$19.2 (S)
unnamed: R92.2, R172.1
unnamed: R96.1, U$19.1 (G)
unnamed: R94.2, R97.2, U$19.3 (D)
unnamed: R93.1, R98.2
unnamed: R102.1, U$20.1 (G)
unnamed: R100.2, R103.2, U$20.3 (D)
unnamed: D16.C, D18.A, R89.1, R100.1, R103.1, R172.2, U$18.2 (S)
unnamed: R99.1, R104.2
unnamed: R108.1, U$21.1 (G)
unnamed: R106.2, R109.2, U$21.3 (D)
unnamed: D18.C, D19.A, R99.2, R101.1, R106.1, R109.1, U$20.2 (S)
unnamed: R105.1, R110.2
unnamed: R114.1, U$22.1 (G)
unnamed: R112.2, R115.2, U$22.3 (D)
unnamed: D19.C, D20.A, R105.2, R107.1, R112.1, R115.1, U$21.2 (S)
unnamed: R111.1, R116.2
unnamed: R120.1, U$23.1 (G)
unnamed: R118.2, R121.2, U$23.3 (D)
unnamed: D20.C, D21.A, R111.2, R113.1, R118.1, R121.1, U$22.2 (S)
unnamed: R117.1, R122.2
unnamed: R126.1, U$24.1 (G)
unnamed: R124.2, R127.2, U$24.3 (D)
unnamed: D22.A, D23.C, R124.1, R127.1, R129.2, R131.1, U$25.2 (S)
unnamed: R123.1, R128.2
unnamed: R132.1, U$25.1 (G)
unnamed: R130.2, R133.2, U$25.3 (D)
unnamed: D21.C, D23.A, R117.2, R119.1, R130.1, R133.1, U$23.2 (S)
unnamed: R129.1, R134.2
unnamed: R138.1, U$26.1 (G)
unnamed: R136.2, R139.2, U$26.3 (D)
unnamed: D22.C, D24.A, R123.2, R125.1, R136.1, R139.1, U$24.2 (S)
unnamed: R135.1, R140.2
unnamed: R144.1, U$27.1 (G)
unnamed: R142.2, R145.2, U$27.3 (D)
unnamed: D24.C, D25.A, R135.2, R137.1, R142.1, R145.1, U$26.2 (S)
unnamed: R141.1, R146.2
unnamed: R150.1, U$28.1 (G)
unnamed: R148.2, R151.2, U$28.3 (D)
unnamed: D25.C, D26.A, R141.2, R143.1, R148.1, R151.1, U$27.2 (S)
unnamed: R147.1, R152.2
unnamed: D27.C, R153.2, R155.1, U$29.2 (S)
unnamed: R156.1, U$29.1 (G)
unnamed: R154.2, R157.2, U$29.3 (D)
unnamed: D26.C, D27.A, D29.A, R147.2, R149.1, R154.1, R157.1, U$28.2 (S)
unnamed: R153.1, R158.2
unnamed: R159.1, R160.2
unnamed: R160.1, R162.1, U$30.1
unnamed: D17.A, R94.1, R97.1, R159.2
unnamed: R161.1, R162.2
unnamed: R164.1, R165.2
unnamed: D29.C, R164.2, R166.1, R167.1
unnamed: C33.2, R168.2, U$16.26 (CO)
unnamed: C34.2, U$16.31 (VREFF)
unnamed: C35.2, R169.1, R170.1, U$16.32 (VREG), U$16.37 (A0), U$17.10 (EN2), U$17.16 (VDD2)
unnamed: R169.2, U$16.34 (WDTB)
unnamed: R170.2, U$16.43 (SDO), U$17.11 (B4)
unnamed: U$16.44 (CSBI), U$17.12 (B3)
unnamed: U$16.42 (SDI), U$17.13 (B2)
unnamed: U$16.41 (SCKI), U$17.14 (B1)
unnamed: D32.C, U$17.6 (A4)
S1-2: R96.2, U$16.25 (S1)
S2-2: R90.2, U$16.23 (S2)
S3-2: R102.2, U$16.P$21 (S3)
S4-2: R108.2, U$16.P$19 (S4)
S5-2: R114.2, U$16.P$17 (S5)
S6-2: R120.2, U$16.P$15 (S6)
S7-2: R132.2, U$16.P$13 (S7)
S8-2: R126.2, U$16.P$11 (S8)
S9-2: R138.2, U$16.P$9 (S9)
S10-2: R144.2, U$16.P$7 (S10)
S11-2: R150.2, U$16.P$5 (S11)
S12-2: R156.2, U$16.P$3 (S12)
SCK: U$17.3 (A1); also elsewhere on the board
SDI: U$17.4 (A2); also elsewhere on the board
SDO: D32.A; also elsewhere on the board
V1+2: C31.2, C32.2, R166.2, R167.2, U$16.P$1 (V+)
VDD: U$17.1 (VDD1), U$17.7 (EN1); also elsewhere on the board

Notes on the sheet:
Module 2 [81]

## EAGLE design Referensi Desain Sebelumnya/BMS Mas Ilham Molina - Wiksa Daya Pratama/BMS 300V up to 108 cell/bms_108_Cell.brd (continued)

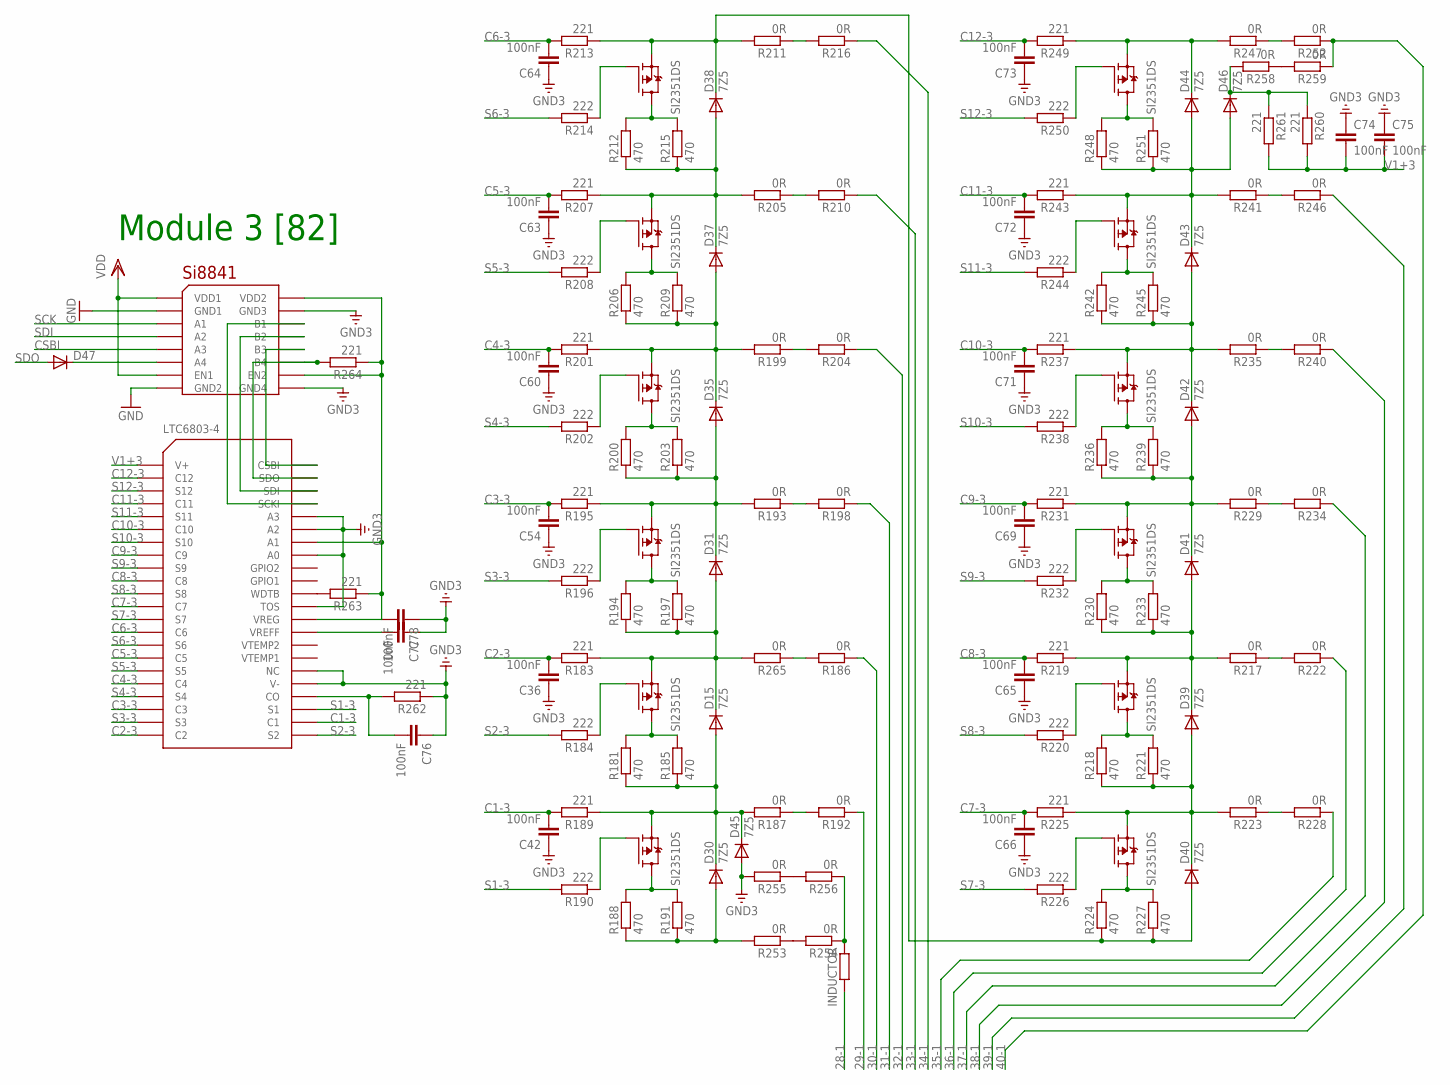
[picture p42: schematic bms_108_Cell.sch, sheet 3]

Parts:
C36, C42, C54, C60, C63, C64, C65, C66, C69, C71, C72, C73, C74, C75, C76, C77, C78: 100nF; C0805K
D15, D30, D31, D35, D37, D38, D39, D40, D41, D42, D43, D44, D45, D46: 7Z5; SMB
D47: DIODE-SOD123; SOD123
R181, R185, R188, R191, R194, R197, R200, R203, R206, R209, R212, R215, R218, R221, R224, R227, R230, R233, R236, R239, R242, R245, R248, R251: 470; R6332
R183, R189, R195, R201, R207, R213, R219, R225, R231, R237, R243, R249, R260, R261, R262, R263, R264: 221; R0805
R184, R190, R196, R202, R208, R214, R220, R226, R232, R238, R244, R250: 222; R0805
R186, R187, R192, R193, R198, R199, R204, R205, R210, R211, R216, R217, R222, R223, R228, R229, R234, R235, R240, R241, R246, R247, R252, R253, R254, R255, R256, R258, R259, R265: 0R; M1206
U$34: LTC6803-4; SSOP44
U$35: SI8841; SO16
U$36, U$37, U$38, U$39, U$40, U$41, U$42, U$45, U$46, U$47, U$48, U$49: SI2351DS; SOT23
U$50: INDUCTOR; L2012C

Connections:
28-1: U$50.2; also elsewhere on the board
29-1: R192.1; also elsewhere on the board
30-1: R186.1; also elsewhere on the board
31-1: R198.1; also elsewhere on the board
32-1: R204.1; also elsewhere on the board
33-1: R210.1; also elsewhere on the board
34-1: R216.1; also elsewhere on the board
35-1: R228.1; also elsewhere on the board
36-1: R222.1; also elsewhere on the board
37-1: R234.1; also elsewhere on the board
38-1: R240.1; also elsewhere on the board
39-1: R246.1; also elsewhere on the board
40-1: R252.1, R259.1; also elsewhere on the board
C1-3: C42.2, R189.2, U$34.24 (C1)
C2-3: C36.2, R183.2, U$34.P$22 (C2)
C3-3: C54.2, R195.2, U$34.P$20 (C3)
C4-3: C60.2, R201.2, U$34.P$18 (C4)
C5-3: C63.2, R207.2, U$34.P$16 (C5)
C6-3: C64.2, R213.2, U$34.P$14 (C6)
C7-3: C66.2, R225.2, U$34.P$12 (C7)
C8-3: C65.2, R219.2, U$34.P$10 (C8)
C9-3: C69.2, R231.2, U$34.P$8 (C9)
C10-3: C71.2, R237.2, U$34.P$6 (C10)
C11-3: C72.2, R243.2, U$34.P$4 (C11)
C12-3: C73.2, R249.2, U$34.P$2 (C12)
CSBI: U$35.5 (A3); also elsewhere on the board
GND: U$35.2 (GND1), U$35.8 (GND2); also elsewhere on the board
GND3: C36.1, C42.1, C54.1, C60.1, C63.1, C64.1, C65.1, C66.1, C69.1, C71.1, C72.1, C73.1, C74.1, C75.1, C76.1, C77.1, C78.1, D45.A, R255.2, R262.1, U$34.27 (V-), U$34.28 (NC), U$34.33 (TOS), U$34.37 (A0), U$34.39 (A2), U$34.40 (A3), U$35.9 (GND4), U$35.15 (GND3)
unnamed: R184.1, U$36.1 (G)
unnamed: R181.2, R185.2, U$36.3 (D)
unnamed: D15.A, D30.C, D45.C, R181.1, R185.1, R187.2, R189.1, U$37.2 (S)
unnamed: R186.2, R265.1
unnamed: R190.1, U$37.1 (G)
unnamed: R188.2, R191.2, U$37.3 (D)
unnamed: R187.1, R192.2
unnamed: R196.1, U$38.1 (G)
unnamed: R194.2, R197.2, U$38.3 (D)
unnamed: D15.C, D31.A, R183.1, R194.1, R197.1, R265.2, U$36.2 (S)
unnamed: R193.1, R198.2
unnamed: R202.1, U$39.1 (G)
unnamed: R200.2, R203.2, U$39.3 (D)
unnamed: D31.C, D35.A, R193.2, R195.1, R200.1, R203.1, U$38.2 (S)
unnamed: R199.1, R204.2
unnamed: R208.1, U$40.1 (G)
unnamed: R206.2, R209.2, U$40.3 (D)
unnamed: D35.C, D37.A, R199.2, R201.1, R206.1, R209.1, U$39.2 (S)
unnamed: R205.1, R210.2
unnamed: R214.1, U$41.1 (G)
unnamed: R212.2, R215.2, U$41.3 (D)
unnamed: D37.C, D38.A, R205.2, R207.1, R212.1, R215.1, U$40.2 (S)
unnamed: R211.1, R216.2
unnamed: R220.1, U$42.1 (G)
unnamed: R218.2, R221.2, U$42.3 (D)
unnamed: D39.A, D40.C, R218.1, R221.1, R223.2, R225.1, U$45.2 (S)
unnamed: R217.1, R222.2
unnamed: R226.1, U$45.1 (G)
unnamed: R224.2, R227.2, U$45.3 (D)
unnamed: D38.C, D40.A, R211.2, R213.1, R224.1, R227.1, U$41.2 (S)
unnamed: R223.1, R228.2
unnamed: R232.1, U$46.1 (G)
unnamed: R230.2, R233.2, U$46.3 (D)
unnamed: D39.C, D41.A, R217.2, R219.1, R230.1, R233.1, U$42.2 (S)
unnamed: R229.1, R234.2
unnamed: R238.1, U$47.1 (G)
unnamed: R236.2, R239.2, U$47.3 (D)
unnamed: D41.C, D42.A, R229.2, R231.1, R236.1, R239.1, U$46.2 (S)
unnamed: R235.1, R240.2
unnamed: R244.1, U$48.1 (G)
unnamed: R242.2, R245.2, U$48.3 (D)
unnamed: D42.C, D43.A, R235.2, R237.1, R242.1, R245.1, U$47.2 (S)
unnamed: R241.1, R246.2
unnamed: D44.C, R247.2, R249.1, U$49.2 (S)
unnamed: R250.1, U$49.1 (G)
unnamed: R248.2, R251.2, U$49.3 (D)
unnamed: D43.C, D44.A, D46.A, R241.2, R243.1, R248.1, R251.1, U$48.2 (S)
unnamed: R247.1, R252.2
unnamed: R253.1, R254.2
unnamed: R254.1, R256.1, U$50.1
unnamed: D30.A, R188.1, R191.1, R253.2
unnamed: R255.1, R256.2
unnamed: R258.1, R259.2
unnamed: D46.C, R258.2, R260.1, R261.1
unnamed: C76.2, R262.2, U$34.26 (CO)
unnamed: C77.2, U$34.31 (VREFF)
unnamed: C78.2, R263.1, R264.1, U$34.32 (VREG), U$34.38 (A1), U$35.10 (EN2), U$35.16 (VDD2)
unnamed: R263.2, U$34.34 (WDTB)
unnamed: R264.2, U$34.43 (SDO), U$35.11 (B4)
unnamed: U$34.44 (CSBI), U$35.12 (B3)
unnamed: U$34.42 (SDI), U$35.13 (B2)
unnamed: U$34.41 (SCKI), U$35.14 (B1)
unnamed: D47.C, U$35.6 (A4)
S1-3: R190.2, U$34.25 (S1)
S2-3: R184.2, U$34.23 (S2)
S3-3: R196.2, U$34.P$21 (S3)
S4-3: R202.2, U$34.P$19 (S4)
S5-3: R208.2, U$34.P$17 (S5)
S6-3: R214.2, U$34.P$15 (S6)
S7-3: R226.2, U$34.P$13 (S7)
S8-3: R220.2, U$34.P$11 (S8)
S9-3: R232.2, U$34.P$9 (S9)
S10-3: R238.2, U$34.P$7 (S10)
S11-3: R244.2, U$34.P$5 (S11)
S12-3: R250.2, U$34.P$3 (S12)
SCK: U$35.3 (A1); also elsewhere on the board
SDI: U$35.4 (A2); also elsewhere on the board
SDO: D47.A; also elsewhere on the board
V1+3: C74.2, C75.2, R260.2, R261.2, U$34.P$1 (V+)
VDD: U$35.1 (VDD1), U$35.7 (EN1); also elsewhere on the board

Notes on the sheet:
Module 3 [82]

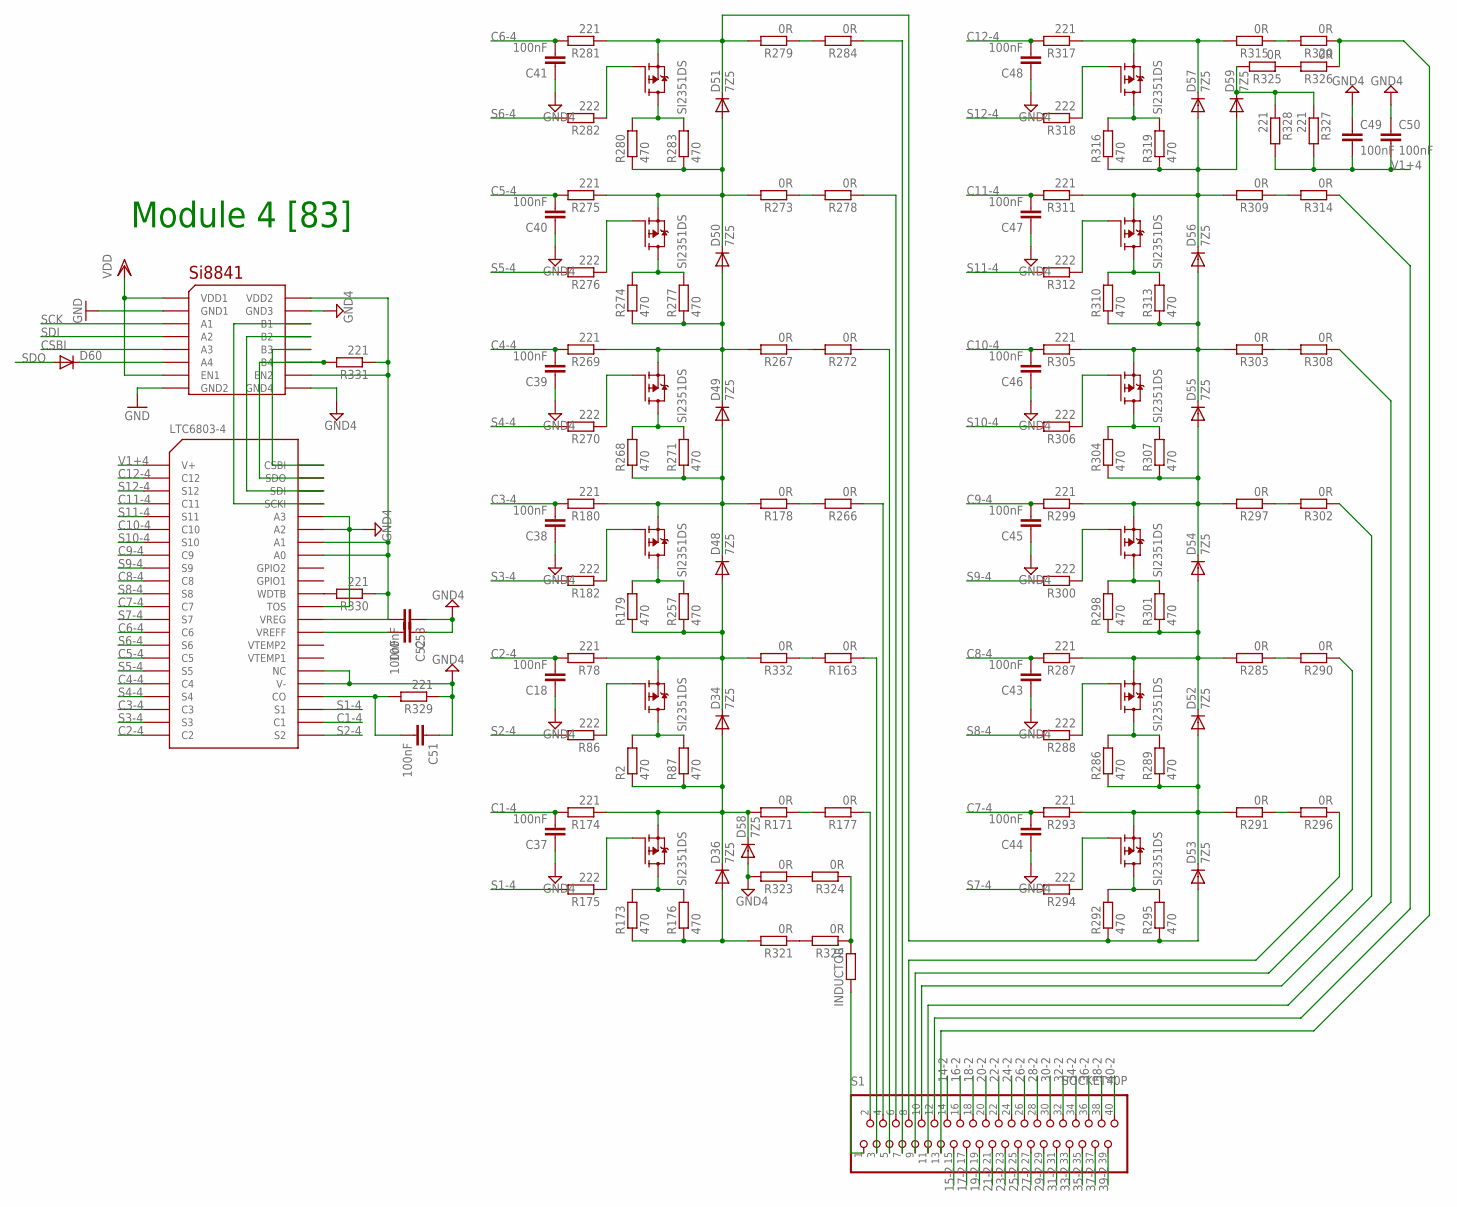
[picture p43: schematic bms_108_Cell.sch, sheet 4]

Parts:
C18, C37, C38, C39, C40, C41, C43, C44, C45, C46, C47, C48, C49, C50, C51, C52, C53: 100nF; C0805K
D34, D36, D48, D49, D50, D51, D52, D53, D54, D55, D56, D57, D58, D59: 7Z5; SMB
D60: DIODE-SOD123; SOD123
R2, R87, R173, R176, R179, R257, R268, R271, R274, R277, R280, R283, R286, R289, R292, R295, R298, R301, R304, R307, R310, R313, R316, R319: 470; R6332
R78, R174, R180, R269, R275, R281, R287, R293, R299, R305, R311, R317, R327, R328, R329, R330, R331: 221; R0805
R86, R175, R182, R270, R276, R282, R288, R294, R300, R306, R312, R318: 222; R0805
R163, R171, R177, R178, R266, R267, R272, R273, R278, R279, R284, R285, R290, R291, R296, R297, R302, R303, R308, R309, R314, R315, R320, R321, R322, R323, R324, R325, R326, R332: 0R; M1206
S1: SOCKET40P; 40PIN
U$31: LTC6803-4; SSOP44
U$32: SI8841; SO16
U$33, U$43, U$44, U$51, U$52, U$53, U$54, U$55, U$56, U$57, U$58, U$59: SI2351DS; SOT23
U$60: INDUCTOR; L2012C

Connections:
14-2: S1.14; also elsewhere on the board
15-2: S1.15; also elsewhere on the board
16-2: S1.16; also elsewhere on the board
17-2: S1.17; also elsewhere on the board
18-2: S1.18; also elsewhere on the board
19-2: S1.19; also elsewhere on the board
20-2: S1.20; also elsewhere on the board
21-2: S1.21; also elsewhere on the board
22-2: S1.22; also elsewhere on the board
23-2: S1.23; also elsewhere on the board
24-2: S1.24; also elsewhere on the board
25-2: S1.25; also elsewhere on the board
26-2: S1.26; also elsewhere on the board
27-2: S1.27
28-2: S1.28; also elsewhere on the board
29-2: S1.29; also elsewhere on the board
30-2: S1.30; also elsewhere on the board
31-2: S1.31; also elsewhere on the board
32-2: S1.32; also elsewhere on the board
33-2: S1.33; also elsewhere on the board
34-2: S1.34; also elsewhere on the board
35-2: S1.35; also elsewhere on the board
36-2: S1.36; also elsewhere on the board
37-2: S1.37; also elsewhere on the board
38-2: S1.38; also elsewhere on the board
39-2: S1.39; also elsewhere on the board
40-2: S1.40; also elsewhere on the board
C1-4: C37.2, R174.2, U$31.24 (C1)
C2-4: C18.2, R78.2, U$31.P$22 (C2)
C3-4: C38.2, R180.2, U$31.P$20 (C3)
C4-4: C39.2, R269.2, U$31.P$18 (C4)
C5-4: C40.2, R275.2, U$31.P$16 (C5)
C6-4: C41.2, R281.2, U$31.P$14 (C6)
C7-4: C44.2, R293.2, U$31.P$12 (C7)
C8-4: C43.2, R287.2, U$31.P$10 (C8)
C9-4: C45.2, R299.2, U$31.P$8 (C9)
C10-4: C46.2, R305.2, U$31.P$6 (C10)
C11-4: C47.2, R311.2, U$31.P$4 (C11)
C12-4: C48.2, R317.2, U$31.P$2 (C12)
CSBI: U$32.5 (A3); also elsewhere on the board
GND: U$32.2 (GND1), U$32.8 (GND2); also elsewhere on the board
GND4: C18.1, C37.1, C38.1, C39.1, C40.1, C41.1, C43.1, C44.1, C45.1, C46.1, C47.1, C48.1, C49.1, C50.1, C51.1, C52.1, C53.1, D58.A, R323.2, R329.1, U$31.27 (V-), U$31.28 (NC), U$31.33 (TOS), U$31.39 (A2), U$31.40 (A3), U$32.9 (GND4), U$32.15 (GND3)
unnamed: R86.1, U$33.1 (G)
unnamed: R2.2, R87.2, U$33.3 (D)
unnamed: D34.A, D36.C, D58.C, R2.1, R87.1, R171.2, R174.1, U$43.2 (S)
unnamed: R163.2, R332.1
unnamed: R175.1, U$43.1 (G)
unnamed: R173.2, R176.2, U$43.3 (D)
unnamed: R171.1, R177.2
unnamed: R182.1, U$44.1 (G)
unnamed: R179.2, R257.2, U$44.3 (D)
unnamed: D34.C, D48.A, R78.1, R179.1, R257.1, R332.2, U$33.2 (S)
unnamed: R178.1, R266.2
unnamed: R270.1, U$51.1 (G)
unnamed: R268.2, R271.2, U$51.3 (D)
unnamed: D48.C, D49.A, R178.2, R180.1, R268.1, R271.1, U$44.2 (S)
unnamed: R267.1, R272.2
unnamed: R276.1, U$52.1 (G)
unnamed: R274.2, R277.2, U$52.3 (D)
unnamed: D49.C, D50.A, R267.2, R269.1, R274.1, R277.1, U$51.2 (S)
unnamed: R273.1, R278.2
unnamed: R282.1, U$53.1 (G)
unnamed: R280.2, R283.2, U$53.3 (D)
unnamed: D50.C, D51.A, R273.2, R275.1, R280.1, R283.1, U$52.2 (S)
unnamed: R279.1, R284.2
unnamed: R288.1, U$54.1 (G)
unnamed: R286.2, R289.2, U$54.3 (D)
unnamed: D52.A, D53.C, R286.1, R289.1, R291.2, R293.1, U$55.2 (S)
unnamed: R285.1, R290.2
unnamed: R294.1, U$55.1 (G)
unnamed: R292.2, R295.2, U$55.3 (D)
unnamed: D51.C, D53.A, R279.2, R281.1, R292.1, R295.1, U$53.2 (S)
unnamed: R291.1, R296.2
unnamed: R300.1, U$56.1 (G)
unnamed: R298.2, R301.2, U$56.3 (D)
unnamed: D52.C, D54.A, R285.2, R287.1, R298.1, R301.1, U$54.2 (S)
unnamed: R297.1, R302.2
unnamed: R306.1, U$57.1 (G)
unnamed: R304.2, R307.2, U$57.3 (D)
unnamed: D54.C, D55.A, R297.2, R299.1, R304.1, R307.1, U$56.2 (S)
unnamed: R303.1, R308.2
unnamed: R312.1, U$58.1 (G)
unnamed: R310.2, R313.2, U$58.3 (D)
unnamed: D55.C, D56.A, R303.2, R305.1, R310.1, R313.1, U$57.2 (S)
unnamed: R309.1, R314.2
unnamed: D57.C, R315.2, R317.1, U$59.2 (S)
unnamed: R318.1, U$59.1 (G)
unnamed: R316.2, R319.2, U$59.3 (D)
unnamed: D56.C, D57.A, D59.A, R309.2, R311.1, R316.1, R319.1, U$58.2 (S)
unnamed: R315.1, R320.2
unnamed: R321.1, R322.2
unnamed: R322.1, R324.1, U$60.1
unnamed: D36.A, R173.1, R176.1, R321.2
unnamed: R323.1, R324.2
unnamed: R325.1, R326.2
unnamed: D59.C, R325.2, R327.1, R328.1
unnamed: R320.1, R326.1, S1.13
unnamed: C51.2, R329.2, U$31.26 (CO)
unnamed: C52.2, U$31.31 (VREFF)
unnamed: C53.2, R330.1, R331.1, U$31.32 (VREG), U$31.37 (A0), U$31.38 (A1), U$32.10 (EN2), U$32.16 (VDD2)
unnamed: R330.2, U$31.34 (WDTB)
unnamed: R331.2, U$31.43 (SDO), U$32.11 (B4)
unnamed: U$31.44 (CSBI), U$32.12 (B3)
unnamed: U$31.42 (SDI), U$32.13 (B2)
unnamed: U$31.41 (SCKI), U$32.14 (B1)
unnamed: S1.1, U$60.2
unnamed: R177.1, S1.2
unnamed: R163.1, S1.3
unnamed: R266.1, S1.4
unnamed: R272.1, S1.5
unnamed: R278.1, S1.6
unnamed: R284.1, S1.7
unnamed: R296.1, S1.8
unnamed: R290.1, S1.9
unnamed: R302.1, S1.10
unnamed: R308.1, S1.11
unnamed: R314.1, S1.12
unnamed: D60.C, U$32.6 (A4)
S1-4: R175.2, U$31.25 (S1)
S2-4: R86.2, U$31.23 (S2)
S3-4: R182.2, U$31.P$21 (S3)
S4-4: R270.2, U$31.P$19 (S4)
S5-4: R276.2, U$31.P$17 (S5)
S6-4: R282.2, U$31.P$15 (S6)
S7-4: R294.2, U$31.P$13 (S7)
S8-4: R288.2, U$31.P$11 (S8)
S9-4: R300.2, U$31.P$9 (S9)
S10-4: R306.2, U$31.P$7 (S10)
S11-4: R312.2, U$31.P$5 (S11)
S12-4: R318.2, U$31.P$3 (S12)
SCK: U$32.3 (A1); also elsewhere on the board
SDI: U$32.4 (A2); also elsewhere on the board
SDO: D60.A; also elsewhere on the board
V1+4: C49.2, C50.2, R327.2, R328.2, U$31.P$1 (V+)
VDD: U$32.1 (VDD1), U$32.7 (EN1); also elsewhere on the board

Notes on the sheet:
Module 4 [83]

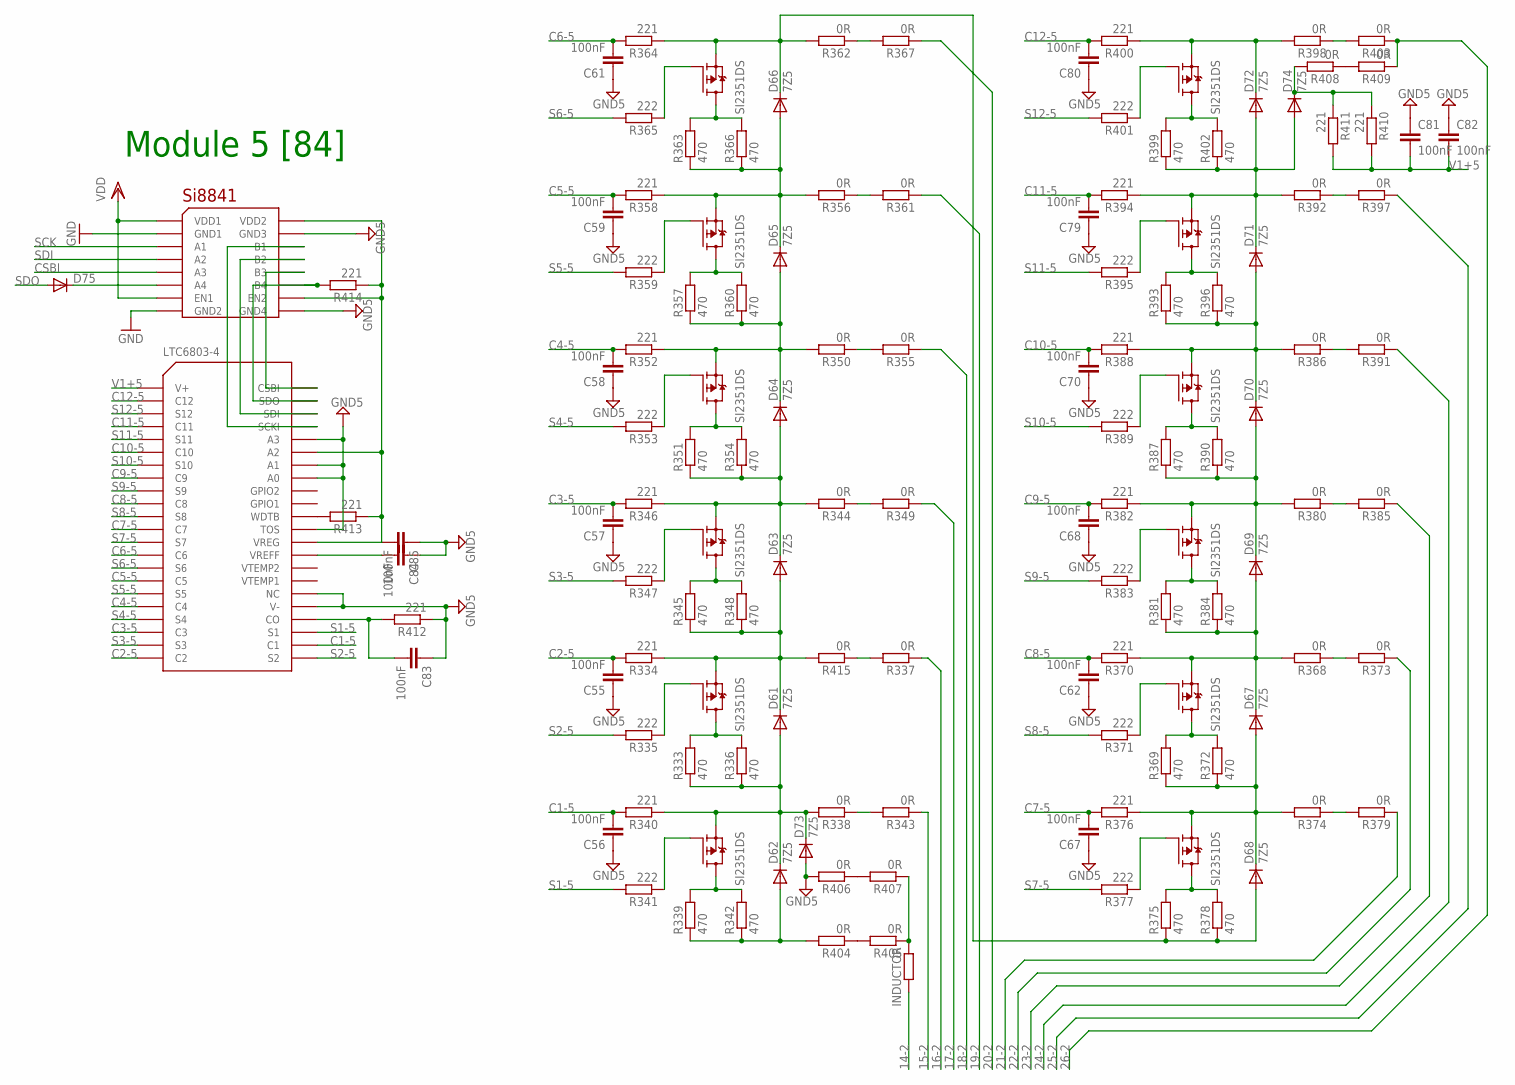
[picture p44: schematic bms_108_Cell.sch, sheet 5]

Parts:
C55, C56, C57, C58, C59, C61, C62, C67, C68, C70, C79, C80, C81, C82, C83, C84, C85: 100nF; C0805K
D61, D62, D63, D64, D65, D66, D67, D68, D69, D70, D71, D72, D73, D74: 7Z5; SMB
D75: DIODE-SOD123; SOD123
R333, R336, R339, R342, R345, R348, R351, R354, R357, R360, R363, R366, R369, R372, R375, R378, R381, R384, R387, R390, R393, R396, R399, R402: 470; R6332
R334, R340, R346, R352, R358, R364, R370, R376, R382, R388, R394, R400, R410, R411, R412, R413, R414: 221; R0805
R335, R341, R347, R353, R359, R365, R371, R377, R383, R389, R395, R401: 222; R0805
R337, R338, R343, R344, R349, R350, R355, R356, R361, R362, R367, R368, R373, R374, R379, R380, R385, R386, R391, R392, R397, R398, R403, R404, R405, R406, R407, R408, R409, R415: 0R; M1206
U$61: LTC6803-4; SSOP44
U$62: SI8841; SO16
U$63, U$64, U$65, U$66, U$67, U$68, U$69, U$70, U$71, U$72, U$73, U$74: SI2351DS; SOT23
U$75: INDUCTOR; L2012C

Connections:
14-2: U$75.2; also elsewhere on the board
15-2: R343.1; also elsewhere on the board
16-2: R337.1; also elsewhere on the board
17-2: R349.1; also elsewhere on the board
18-2: R355.1; also elsewhere on the board
19-2: R361.1; also elsewhere on the board
20-2: R367.1; also elsewhere on the board
21-2: R379.1; also elsewhere on the board
22-2: R373.1; also elsewhere on the board
23-2: R385.1; also elsewhere on the board
24-2: R391.1; also elsewhere on the board
25-2: R397.1; also elsewhere on the board
26-2: R403.1, R409.1; also elsewhere on the board
C1-5: C56.2, R340.2, U$61.24 (C1)
C2-5: C55.2, R334.2, U$61.P$22 (C2)
C3-5: C57.2, R346.2, U$61.P$20 (C3)
C4-5: C58.2, R352.2, U$61.P$18 (C4)
C5-5: C59.2, R358.2, U$61.P$16 (C5)
C6-5: C61.2, R364.2, U$61.P$14 (C6)
C7-5: C67.2, R376.2, U$61.P$12 (C7)
C8-5: C62.2, R370.2, U$61.P$10 (C8)
C9-5: C68.2, R382.2, U$61.P$8 (C9)
C10-5: C70.2, R388.2, U$61.P$6 (C10)
C11-5: C79.2, R394.2, U$61.P$4 (C11)
C12-5: C80.2, R400.2, U$61.P$2 (C12)
CSBI: U$62.5 (A3); also elsewhere on the board
GND: U$62.2 (GND1), U$62.8 (GND2); also elsewhere on the board
GND5: C55.1, C56.1, C57.1, C58.1, C59.1, C61.1, C62.1, C67.1, C68.1, C70.1, C79.1, C80.1, C81.1, C82.1, C83.1, C84.1, C85.1, D73.A, R406.2, R412.1, U$61.27 (V-), U$61.28 (NC), U$61.33 (TOS), U$61.37 (A0), U$61.38 (A1), U$61.40 (A3), U$62.9 (GND4), U$62.15 (GND3)
unnamed: R335.1, U$63.1 (G)
unnamed: R333.2, R336.2, U$63.3 (D)
unnamed: D61.A, D62.C, D73.C, R333.1, R336.1, R338.2, R340.1, U$64.2 (S)
unnamed: R337.2, R415.1
unnamed: R341.1, U$64.1 (G)
unnamed: R339.2, R342.2, U$64.3 (D)
unnamed: R338.1, R343.2
unnamed: R347.1, U$65.1 (G)
unnamed: R345.2, R348.2, U$65.3 (D)
unnamed: D61.C, D63.A, R334.1, R345.1, R348.1, R415.2, U$63.2 (S)
unnamed: R344.1, R349.2
unnamed: R353.1, U$66.1 (G)
unnamed: R351.2, R354.2, U$66.3 (D)
unnamed: D63.C, D64.A, R344.2, R346.1, R351.1, R354.1, U$65.2 (S)
unnamed: R350.1, R355.2
unnamed: R359.1, U$67.1 (G)
unnamed: R357.2, R360.2, U$67.3 (D)
unnamed: D64.C, D65.A, R350.2, R352.1, R357.1, R360.1, U$66.2 (S)
unnamed: R356.1, R361.2
unnamed: R365.1, U$68.1 (G)
unnamed: R363.2, R366.2, U$68.3 (D)
unnamed: D65.C, D66.A, R356.2, R358.1, R363.1, R366.1, U$67.2 (S)
unnamed: R362.1, R367.2
unnamed: R371.1, U$69.1 (G)
unnamed: R369.2, R372.2, U$69.3 (D)
unnamed: D67.A, D68.C, R369.1, R372.1, R374.2, R376.1, U$70.2 (S)
unnamed: R368.1, R373.2
unnamed: R377.1, U$70.1 (G)
unnamed: R375.2, R378.2, U$70.3 (D)
unnamed: D66.C, D68.A, R362.2, R364.1, R375.1, R378.1, U$68.2 (S)
unnamed: R374.1, R379.2
unnamed: R383.1, U$71.1 (G)
unnamed: R381.2, R384.2, U$71.3 (D)
unnamed: D67.C, D69.A, R368.2, R370.1, R381.1, R384.1, U$69.2 (S)
unnamed: R380.1, R385.2
unnamed: R389.1, U$72.1 (G)
unnamed: R387.2, R390.2, U$72.3 (D)
unnamed: D69.C, D70.A, R380.2, R382.1, R387.1, R390.1, U$71.2 (S)
unnamed: R386.1, R391.2
unnamed: R395.1, U$73.1 (G)
unnamed: R393.2, R396.2, U$73.3 (D)
unnamed: D70.C, D71.A, R386.2, R388.1, R393.1, R396.1, U$72.2 (S)
unnamed: R392.1, R397.2
unnamed: D72.C, R398.2, R400.1, U$74.2 (S)
unnamed: R401.1, U$74.1 (G)
unnamed: R399.2, R402.2, U$74.3 (D)
unnamed: D71.C, D72.A, D74.A, R392.2, R394.1, R399.1, R402.1, U$73.2 (S)
unnamed: R398.1, R403.2
unnamed: R404.1, R405.2
unnamed: R405.1, R407.1, U$75.1
unnamed: D62.A, R339.1, R342.1, R404.2
unnamed: R406.1, R407.2
unnamed: R408.1, R409.2
unnamed: D74.C, R408.2, R410.1, R411.1
unnamed: C83.2, R412.2, U$61.26 (CO)
unnamed: C84.2, U$61.31 (VREFF)
unnamed: C85.2, R413.1, R414.1, U$61.32 (VREG), U$61.39 (A2), U$62.10 (EN2), U$62.16 (VDD2)
unnamed: R413.2, U$61.34 (WDTB)
unnamed: R414.2, U$61.43 (SDO), U$62.11 (B4)
unnamed: U$61.44 (CSBI), U$62.12 (B3)
unnamed: U$61.42 (SDI), U$62.13 (B2)
unnamed: U$61.41 (SCKI), U$62.14 (B1)
unnamed: D75.C, U$62.6 (A4)
S1-5: R341.2, U$61.25 (S1)
S2-5: R335.2, U$61.23 (S2)
S3-5: R347.2, U$61.P$21 (S3)
S4-5: R353.2, U$61.P$19 (S4)
S5-5: R359.2, U$61.P$17 (S5)
S6-5: R365.2, U$61.P$15 (S6)
S7-5: R377.2, U$61.P$13 (S7)
S8-5: R371.2, U$61.P$11 (S8)
S9-5: R383.2, U$61.P$9 (S9)
S10-5: R389.2, U$61.P$7 (S10)
S11-5: R395.2, U$61.P$5 (S11)
S12-5: R401.2, U$61.P$3 (S12)
SCK: U$62.3 (A1); also elsewhere on the board
SDI: U$62.4 (A2); also elsewhere on the board
SDO: D75.A; also elsewhere on the board
V1+5: C81.2, C82.2, R410.2, R411.2, U$61.P$1 (V+)
VDD: U$62.1 (VDD1), U$62.7 (EN1); also elsewhere on the board

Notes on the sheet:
Module 5 [84]

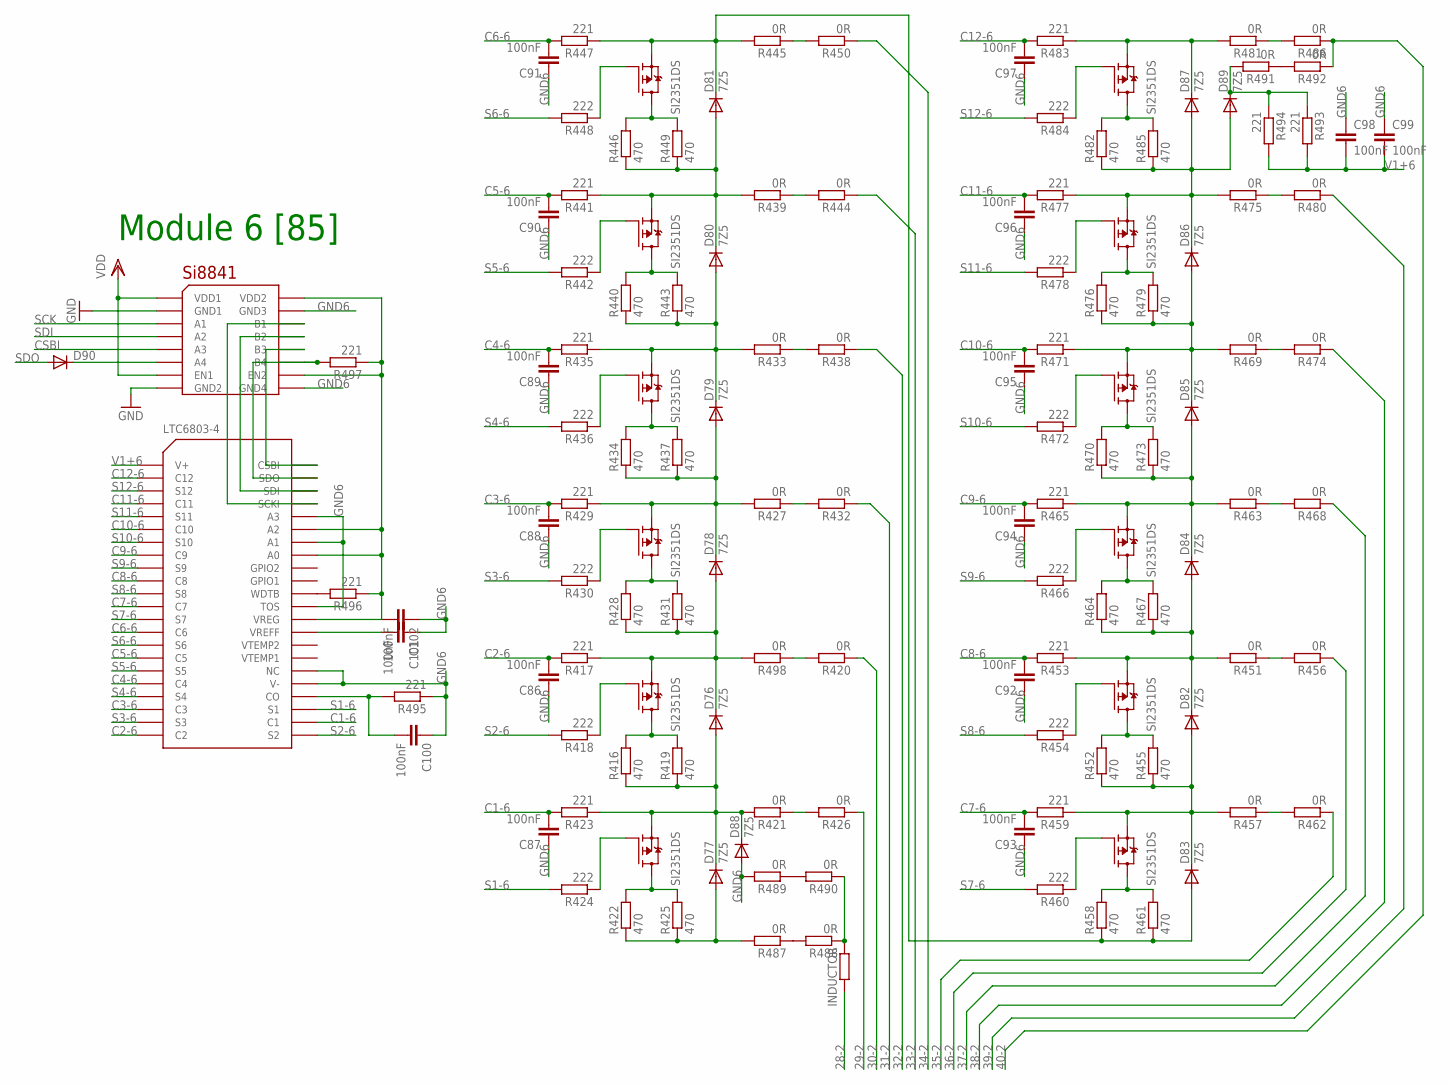
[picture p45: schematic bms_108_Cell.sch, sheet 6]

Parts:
C86, C87, C88, C89, C90, C91, C92, C93, C94, C95, C96, C97, C98, C99, C100, C101, C102: 100nF; C0805K
D76, D77, D78, D79, D80, D81, D82, D83, D84, D85, D86, D87, D88, D89: 7Z5; SMB
D90: DIODE-SOD123; SOD123
R416, R419, R422, R425, R428, R431, R434, R437, R440, R443, R446, R449, R452, R455, R458, R461, R464, R467, R470, R473, R476, R479, R482, R485: 470; R6332
R417, R423, R429, R435, R441, R447, R453, R459, R465, R471, R477, R483, R493, R494, R495, R496, R497: 221; R0805
R418, R424, R430, R436, R442, R448, R454, R460, R466, R472, R478, R484: 222; R0805
R420, R421, R426, R427, R432, R433, R438, R439, R444, R445, R450, R451, R456, R457, R462, R463, R468, R469, R474, R475, R480, R481, R486, R487, R488, R489, R490, R491, R492, R498: 0R; M1206
U$76: LTC6803-4; SSOP44
U$77: SI8841; SO16
U$78, U$79, U$80, U$81, U$82, U$83, U$84, U$85, U$86, U$87, U$88, U$89: SI2351DS; SOT23
U$90: INDUCTOR; L2012C

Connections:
28-2: U$90.2; also elsewhere on the board
29-2: R426.1; also elsewhere on the board
30-2: R420.1; also elsewhere on the board
31-2: R432.1; also elsewhere on the board
32-2: R438.1; also elsewhere on the board
33-2: R444.1; also elsewhere on the board
34-2: R450.1; also elsewhere on the board
35-2: R462.1; also elsewhere on the board
36-2: R456.1; also elsewhere on the board
37-2: R468.1; also elsewhere on the board
38-2: R474.1; also elsewhere on the board
39-2: R480.1; also elsewhere on the board
40-2: R486.1, R492.1; also elsewhere on the board
C1-6: C87.2, R423.2, U$76.24 (C1)
C2-6: C86.2, R417.2, U$76.P$22 (C2)
C3-6: C88.2, R429.2, U$76.P$20 (C3)
C4-6: C89.2, R435.2, U$76.P$18 (C4)
C5-6: C90.2, R441.2, U$76.P$16 (C5)
C6-6: C91.2, R447.2, U$76.P$14 (C6)
C7-6: C93.2, R459.2, U$76.P$12 (C7)
C8-6: C92.2, R453.2, U$76.P$10 (C8)
C9-6: C94.2, R465.2, U$76.P$8 (C9)
C10-6: C95.2, R471.2, U$76.P$6 (C10)
C11-6: C96.2, R477.2, U$76.P$4 (C11)
C12-6: C97.2, R483.2, U$76.P$2 (C12)
CSBI: U$77.5 (A3); also elsewhere on the board
GND: U$77.2 (GND1), U$77.8 (GND2); also elsewhere on the board
GND6: C86.1, C87.1, C88.1, C89.1, C90.1, C91.1, C92.1, C93.1, C94.1, C95.1, C96.1, C97.1, C98.1, C99.1, C100.1, C101.1, C102.1, D88.A, R489.2, R495.1, U$76.27 (V-), U$76.28 (NC), U$76.33 (TOS), U$76.38 (A1), U$76.40 (A3), U$77.9 (GND4), U$77.15 (GND3)
unnamed: R418.1, U$78.1 (G)
unnamed: R416.2, R419.2, U$78.3 (D)
unnamed: D76.A, D77.C, D88.C, R416.1, R419.1, R421.2, R423.1, U$79.2 (S)
unnamed: R420.2, R498.1
unnamed: R424.1, U$79.1 (G)
unnamed: R422.2, R425.2, U$79.3 (D)
unnamed: R421.1, R426.2
unnamed: R430.1, U$80.1 (G)
unnamed: R428.2, R431.2, U$80.3 (D)
unnamed: D76.C, D78.A, R417.1, R428.1, R431.1, R498.2, U$78.2 (S)
unnamed: R427.1, R432.2
unnamed: R436.1, U$81.1 (G)
unnamed: R434.2, R437.2, U$81.3 (D)
unnamed: D78.C, D79.A, R427.2, R429.1, R434.1, R437.1, U$80.2 (S)
unnamed: R433.1, R438.2
unnamed: R442.1, U$82.1 (G)
unnamed: R440.2, R443.2, U$82.3 (D)
unnamed: D79.C, D80.A, R433.2, R435.1, R440.1, R443.1, U$81.2 (S)
unnamed: R439.1, R444.2
unnamed: R448.1, U$83.1 (G)
unnamed: R446.2, R449.2, U$83.3 (D)
unnamed: D80.C, D81.A, R439.2, R441.1, R446.1, R449.1, U$82.2 (S)
unnamed: R445.1, R450.2
unnamed: R454.1, U$84.1 (G)
unnamed: R452.2, R455.2, U$84.3 (D)
unnamed: D82.A, D83.C, R452.1, R455.1, R457.2, R459.1, U$85.2 (S)
unnamed: R451.1, R456.2
unnamed: R460.1, U$85.1 (G)
unnamed: R458.2, R461.2, U$85.3 (D)
unnamed: D81.C, D83.A, R445.2, R447.1, R458.1, R461.1, U$83.2 (S)
unnamed: R457.1, R462.2
unnamed: R466.1, U$86.1 (G)
unnamed: R464.2, R467.2, U$86.3 (D)
unnamed: D82.C, D84.A, R451.2, R453.1, R464.1, R467.1, U$84.2 (S)
unnamed: R463.1, R468.2
unnamed: R472.1, U$87.1 (G)
unnamed: R470.2, R473.2, U$87.3 (D)
unnamed: D84.C, D85.A, R463.2, R465.1, R470.1, R473.1, U$86.2 (S)
unnamed: R469.1, R474.2
unnamed: R478.1, U$88.1 (G)
unnamed: R476.2, R479.2, U$88.3 (D)
unnamed: D85.C, D86.A, R469.2, R471.1, R476.1, R479.1, U$87.2 (S)
unnamed: R475.1, R480.2
unnamed: D87.C, R481.2, R483.1, U$89.2 (S)
unnamed: R484.1, U$89.1 (G)
unnamed: R482.2, R485.2, U$89.3 (D)
unnamed: D86.C, D87.A, D89.A, R475.2, R477.1, R482.1, R485.1, U$88.2 (S)
unnamed: R481.1, R486.2
unnamed: R487.1, R488.2
unnamed: R488.1, R490.1, U$90.1
unnamed: D77.A, R422.1, R425.1, R487.2
unnamed: R489.1, R490.2
unnamed: R491.1, R492.2
unnamed: D89.C, R491.2, R493.1, R494.1
unnamed: C100.2, R495.2, U$76.26 (CO)
unnamed: C101.2, U$76.31 (VREFF)
unnamed: C102.2, R496.1, R497.1, U$76.32 (VREG), U$76.37 (A0), U$76.39 (A2), U$77.10 (EN2), U$77.16 (VDD2)
unnamed: R496.2, U$76.34 (WDTB)
unnamed: R497.2, U$76.43 (SDO), U$77.11 (B4)
unnamed: U$76.44 (CSBI), U$77.12 (B3)
unnamed: U$76.42 (SDI), U$77.13 (B2)
unnamed: U$76.41 (SCKI), U$77.14 (B1)
unnamed: D90.C, U$77.6 (A4)
S1-6: R424.2, U$76.25 (S1)
S2-6: R418.2, U$76.23 (S2)
S3-6: R430.2, U$76.P$21 (S3)
S4-6: R436.2, U$76.P$19 (S4)
S5-6: R442.2, U$76.P$17 (S5)
S6-6: R448.2, U$76.P$15 (S6)
S7-6: R460.2, U$76.P$13 (S7)
S8-6: R454.2, U$76.P$11 (S8)
S9-6: R466.2, U$76.P$9 (S9)
S10-6: R472.2, U$76.P$7 (S10)
S11-6: R478.2, U$76.P$5 (S11)
S12-6: R484.2, U$76.P$3 (S12)
SCK: U$77.3 (A1); also elsewhere on the board
SDI: U$77.4 (A2); also elsewhere on the board
SDO: D90.A; also elsewhere on the board
V1+6: C98.2, C99.2, R493.2, R494.2, U$76.P$1 (V+)
VDD: U$77.1 (VDD1), U$77.7 (EN1); also elsewhere on the board

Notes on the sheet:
Module 6 [85]

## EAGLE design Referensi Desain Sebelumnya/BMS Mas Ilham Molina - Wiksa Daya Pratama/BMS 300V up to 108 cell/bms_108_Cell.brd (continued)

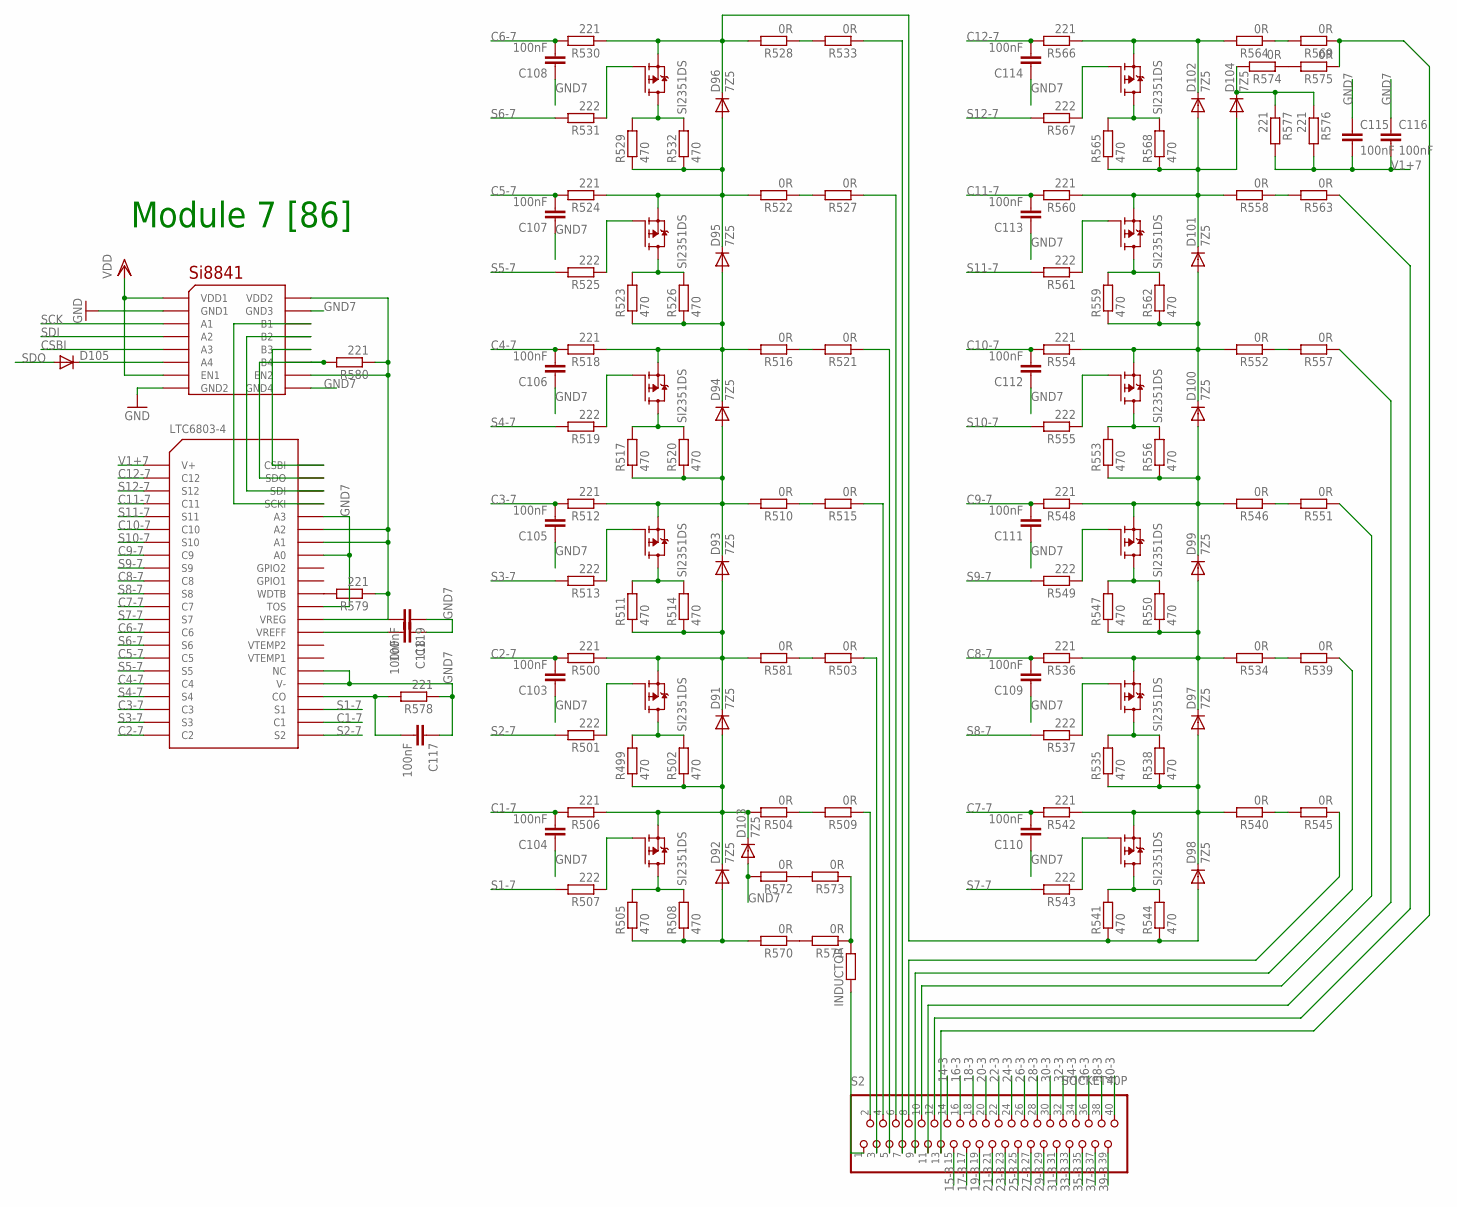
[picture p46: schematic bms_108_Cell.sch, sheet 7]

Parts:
C103, C104, C105, C106, C107, C108, C109, C110, C111, C112, C113, C114, C115, C116, C117, C118, C119: 100nF; C0805K
D91, D92, D93, D94, D95, D96, D97, D98, D99, D100, D101, D102, D103, D104: 7Z5; SMB
D105: DIODE-SOD123; SOD123
R499, R502, R505, R508, R511, R514, R517, R520, R523, R526, R529, R532, R535, R538, R541, R544, R547, R550, R553, R556, R559, R562, R565, R568: 470; R6332
R500, R506, R512, R518, R524, R530, R536, R542, R548, R554, R560, R566, R576, R577, R578, R579, R580: 221; R0805
R501, R507, R513, R519, R525, R531, R537, R543, R549, R555, R561, R567: 222; R0805
R503, R504, R509, R510, R515, R516, R521, R522, R527, R528, R533, R534, R539, R540, R545, R546, R551, R552, R557, R558, R563, R564, R569, R570, R571, R572, R573, R574, R575, R581: 0R; M1206
S2: SOCKET40P; 40PIN
U$91: LTC6803-4; SSOP44
U$92: SI8841; SO16
U$93, U$94, U$95, U$96, U$97, U$98, U$99, U$100, U$101, U$102, U$103, U$104: SI2351DS; SOT23
U$105: INDUCTOR; L2012C

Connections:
14-3: S2.14; also elsewhere on the board
15-3: S2.15; also elsewhere on the board
16-3: S2.16; also elsewhere on the board
17-3: S2.17; also elsewhere on the board
18-3: S2.18; also elsewhere on the board
19-3: S2.19; also elsewhere on the board
20-3: S2.20; also elsewhere on the board
21-3: S2.21; also elsewhere on the board
22-3: S2.22; also elsewhere on the board
23-3: S2.23; also elsewhere on the board
24-3: S2.24; also elsewhere on the board
25-3: S2.25; also elsewhere on the board
26-3: S2.26; also elsewhere on the board
27-3: S2.27
28-3: S2.28; also elsewhere on the board
29-3: S2.29; also elsewhere on the board
30-3: S2.30; also elsewhere on the board
31-3: S2.31; also elsewhere on the board
32-3: S2.32; also elsewhere on the board
33-3: S2.33; also elsewhere on the board
34-3: S2.34; also elsewhere on the board
35-3: S2.35; also elsewhere on the board
36-3: S2.36; also elsewhere on the board
37-3: S2.37; also elsewhere on the board
38-3: S2.38; also elsewhere on the board
39-3: S2.39; also elsewhere on the board
40-3: S2.40; also elsewhere on the board
C1-7: C104.2, R506.2, U$91.24 (C1)
C2-7: C103.2, R500.2, U$91.P$22 (C2)
C3-7: C105.2, R512.2, U$91.P$20 (C3)
C4-7: C106.2, R518.2, U$91.P$18 (C4)
C5-7: C107.2, R524.2, U$91.P$16 (C5)
C6-7: C108.2, R530.2, U$91.P$14 (C6)
C7-7: C110.2, R542.2, U$91.P$12 (C7)
C8-7: C109.2, R536.2, U$91.P$10 (C8)
C9-7: C111.2, R548.2, U$91.P$8 (C9)
C10-7: C112.2, R554.2, U$91.P$6 (C10)
C11-7: C113.2, R560.2, U$91.P$4 (C11)
C12-7: C114.2, R566.2, U$91.P$2 (C12)
CSBI: U$92.5 (A3); also elsewhere on the board
GND: U$92.2 (GND1), U$92.8 (GND2); also elsewhere on the board
GND7: C103.1, C104.1, C105.1, C106.1, C107.1, C108.1, C109.1, C110.1, C111.1, C112.1, C113.1, C114.1, C115.1, C116.1, C117.1, C118.1, C119.1, D103.A, R572.2, R578.1, U$91.27 (V-), U$91.28 (NC), U$91.33 (TOS), U$91.37 (A0), U$91.40 (A3), U$92.9 (GND4), U$92.15 (GND3)
unnamed: R501.1, U$93.1 (G)
unnamed: R499.2, R502.2, U$93.3 (D)
unnamed: D91.A, D92.C, D103.C, R499.1, R502.1, R504.2, R506.1, U$94.2 (S)
unnamed: R503.2, R581.1
unnamed: R507.1, U$94.1 (G)
unnamed: R505.2, R508.2, U$94.3 (D)
unnamed: R504.1, R509.2
unnamed: R513.1, U$95.1 (G)
unnamed: R511.2, R514.2, U$95.3 (D)
unnamed: D91.C, D93.A, R500.1, R511.1, R514.1, R581.2, U$93.2 (S)
unnamed: R510.1, R515.2
unnamed: R519.1, U$96.1 (G)
unnamed: R517.2, R520.2, U$96.3 (D)
unnamed: D93.C, D94.A, R510.2, R512.1, R517.1, R520.1, U$95.2 (S)
unnamed: R516.1, R521.2
unnamed: R525.1, U$97.1 (G)
unnamed: R523.2, R526.2, U$97.3 (D)
unnamed: D94.C, D95.A, R516.2, R518.1, R523.1, R526.1, U$96.2 (S)
unnamed: R522.1, R527.2
unnamed: R531.1, U$98.1 (G)
unnamed: R529.2, R532.2, U$98.3 (D)
unnamed: D95.C, D96.A, R522.2, R524.1, R529.1, R532.1, U$97.2 (S)
unnamed: R528.1, R533.2
unnamed: R537.1, U$99.1 (G)
unnamed: R535.2, R538.2, U$99.3 (D)
unnamed: D97.A, D98.C, R535.1, R538.1, R540.2, R542.1, U$100.2 (S)
unnamed: R534.1, R539.2
unnamed: R543.1, U$100.1 (G)
unnamed: R541.2, R544.2, U$100.3 (D)
unnamed: D96.C, D98.A, R528.2, R530.1, R541.1, R544.1, U$98.2 (S)
unnamed: R540.1, R545.2
unnamed: R549.1, U$101.1 (G)
unnamed: R547.2, R550.2, U$101.3 (D)
unnamed: D97.C, D99.A, R534.2, R536.1, R547.1, R550.1, U$99.2 (S)
unnamed: R546.1, R551.2
unnamed: R555.1, U$102.1 (G)
unnamed: R553.2, R556.2, U$102.3 (D)
unnamed: D99.C, D100.A, R546.2, R548.1, R553.1, R556.1, U$101.2 (S)
unnamed: R552.1, R557.2
unnamed: R561.1, U$103.1 (G)
unnamed: R559.2, R562.2, U$103.3 (D)
unnamed: D100.C, D101.A, R552.2, R554.1, R559.1, R562.1, U$102.2 (S)
unnamed: R558.1, R563.2
unnamed: D102.C, R564.2, R566.1, U$104.2 (S)
unnamed: R567.1, U$104.1 (G)
unnamed: R565.2, R568.2, U$104.3 (D)
unnamed: D101.C, D102.A, D104.A, R558.2, R560.1, R565.1, R568.1, U$103.2 (S)
unnamed: R564.1, R569.2
unnamed: R570.1, R571.2
unnamed: R571.1, R573.1, U$105.1
unnamed: D92.A, R505.1, R508.1, R570.2
unnamed: R572.1, R573.2
unnamed: R574.1, R575.2
unnamed: D104.C, R574.2, R576.1, R577.1
unnamed: R569.1, R575.1, S2.13
unnamed: C117.2, R578.2, U$91.26 (CO)
unnamed: C118.2, U$91.31 (VREFF)
unnamed: C119.2, R579.1, R580.1, U$91.32 (VREG), U$91.38 (A1), U$91.39 (A2), U$92.10 (EN2), U$92.16 (VDD2)
unnamed: R579.2, U$91.34 (WDTB)
unnamed: R580.2, U$91.43 (SDO), U$92.11 (B4)
unnamed: U$91.44 (CSBI), U$92.12 (B3)
unnamed: U$91.42 (SDI), U$92.13 (B2)
unnamed: U$91.41 (SCKI), U$92.14 (B1)
unnamed: S2.1, U$105.2
unnamed: R509.1, S2.2
unnamed: R503.1, S2.3
unnamed: R515.1, S2.4
unnamed: R521.1, S2.5
unnamed: R527.1, S2.6
unnamed: R533.1, S2.7
unnamed: R545.1, S2.8
unnamed: R539.1, S2.9
unnamed: R551.1, S2.10
unnamed: R557.1, S2.11
unnamed: R563.1, S2.12
unnamed: D105.C, U$92.6 (A4)
S1-7: R507.2, U$91.25 (S1)
S2-7: R501.2, U$91.23 (S2)
S3-7: R513.2, U$91.P$21 (S3)
S4-7: R519.2, U$91.P$19 (S4)
S5-7: R525.2, U$91.P$17 (S5)
S6-7: R531.2, U$91.P$15 (S6)
S7-7: R543.2, U$91.P$13 (S7)
S8-7: R537.2, U$91.P$11 (S8)
S9-7: R549.2, U$91.P$9 (S9)
S10-7: R555.2, U$91.P$7 (S10)
S11-7: R561.2, U$91.P$5 (S11)
S12-7: R567.2, U$91.P$3 (S12)
SCK: U$92.3 (A1); also elsewhere on the board
SDI: U$92.4 (A2); also elsewhere on the board
SDO: D105.A; also elsewhere on the board
V1+7: C115.2, C116.2, R576.2, R577.2, U$91.P$1 (V+)
VDD: U$92.1 (VDD1), U$92.7 (EN1); also elsewhere on the board

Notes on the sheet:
Module 7 [86]

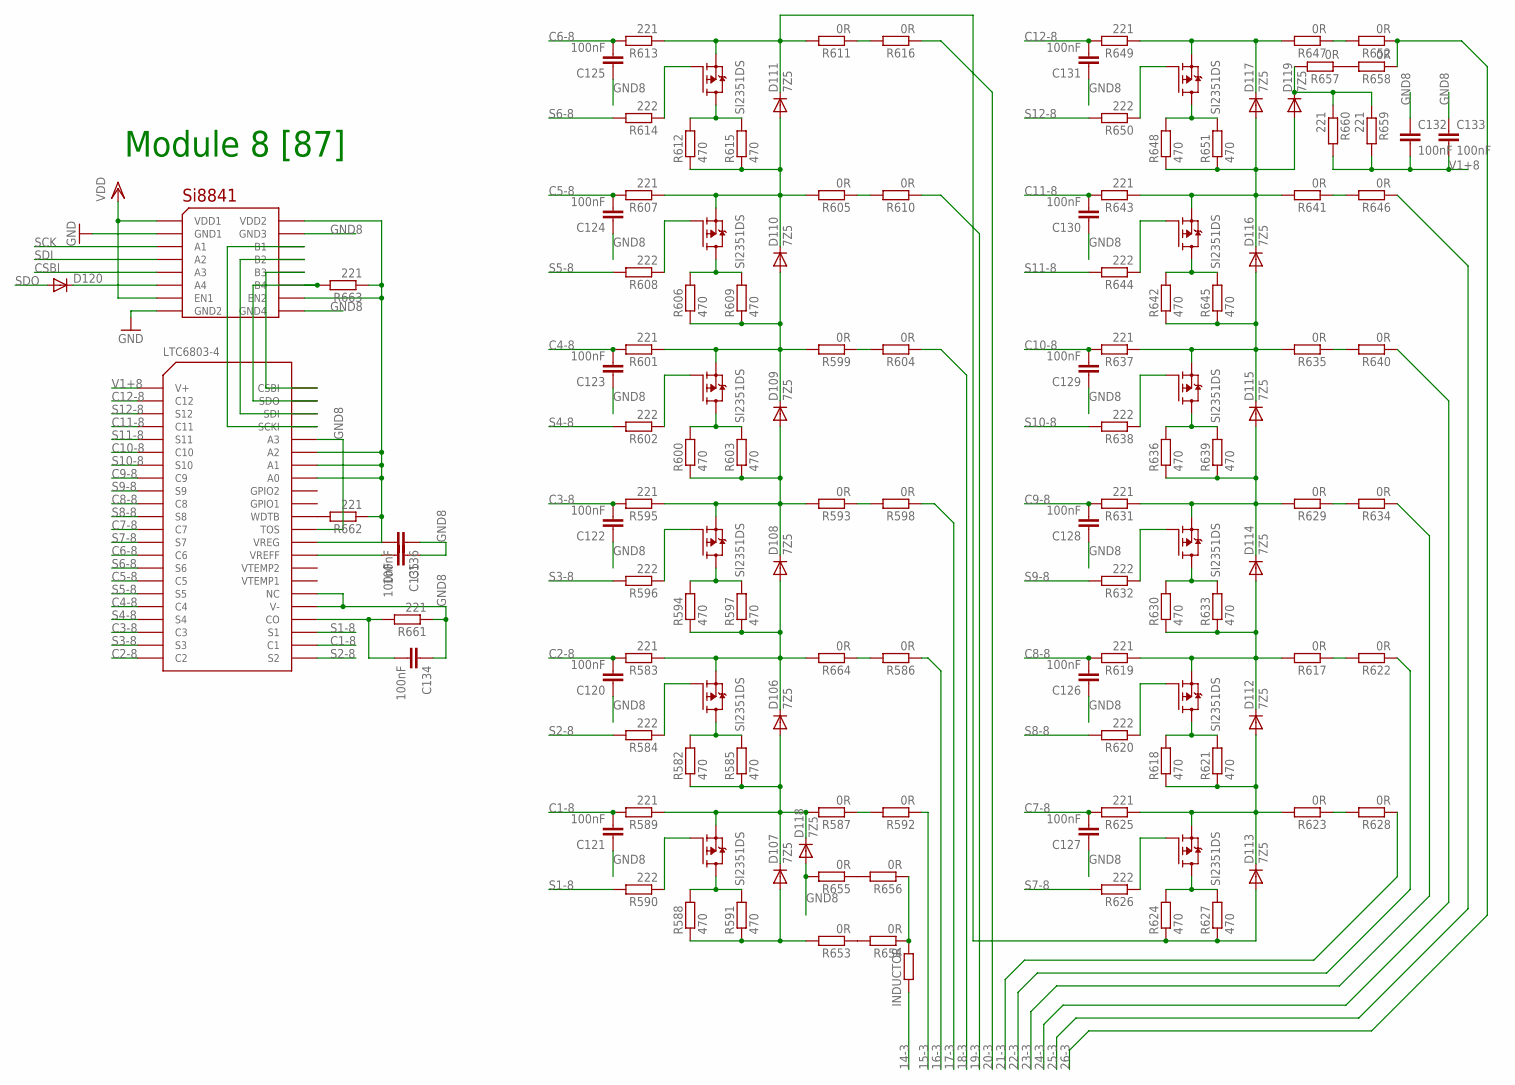
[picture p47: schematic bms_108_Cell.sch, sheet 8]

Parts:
C120, C121, C122, C123, C124, C125, C126, C127, C128, C129, C130, C131, C132, C133, C134, C135, C136: 100nF; C0805K
D106, D107, D108, D109, D110, D111, D112, D113, D114, D115, D116, D117, D118, D119: 7Z5; SMB
D120: DIODE-SOD123; SOD123
R582, R585, R588, R591, R594, R597, R600, R603, R606, R609, R612, R615, R618, R621, R624, R627, R630, R633, R636, R639, R642, R645, R648, R651: 470; R6332
R583, R589, R595, R601, R607, R613, R619, R625, R631, R637, R643, R649, R659, R660, R661, R662, R663: 221; R0805
R584, R590, R596, R602, R608, R614, R620, R626, R632, R638, R644, R650: 222; R0805
R586, R587, R592, R593, R598, R599, R604, R605, R610, R611, R616, R617, R622, R623, R628, R629, R634, R635, R640, R641, R646, R647, R652, R653, R654, R655, R656, R657, R658, R664: 0R; M1206
U$106: LTC6803-4; SSOP44
U$107: SI8841; SO16
U$108, U$109, U$110, U$111, U$112, U$113, U$114, U$115, U$116, U$117, U$118, U$119: SI2351DS; SOT23
U$120: INDUCTOR; L2012C

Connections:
14-3: U$120.2; also elsewhere on the board
15-3: R592.1; also elsewhere on the board
16-3: R586.1; also elsewhere on the board
17-3: R598.1; also elsewhere on the board
18-3: R604.1; also elsewhere on the board
19-3: R610.1; also elsewhere on the board
20-3: R616.1; also elsewhere on the board
21-3: R628.1; also elsewhere on the board
22-3: R622.1; also elsewhere on the board
23-3: R634.1; also elsewhere on the board
24-3: R640.1; also elsewhere on the board
25-3: R646.1; also elsewhere on the board
26-3: R652.1, R658.1; also elsewhere on the board
C1-8: C121.2, R589.2, U$106.24 (C1)
C2-8: C120.2, R583.2, U$106.P$22 (C2)
C3-8: C122.2, R595.2, U$106.P$20 (C3)
C4-8: C123.2, R601.2, U$106.P$18 (C4)
C5-8: C124.2, R607.2, U$106.P$16 (C5)
C6-8: C125.2, R613.2, U$106.P$14 (C6)
C7-8: C127.2, R625.2, U$106.P$12 (C7)
C8-8: C126.2, R619.2, U$106.P$10 (C8)
C9-8: C128.2, R631.2, U$106.P$8 (C9)
C10-8: C129.2, R637.2, U$106.P$6 (C10)
C11-8: C130.2, R643.2, U$106.P$4 (C11)
C12-8: C131.2, R649.2, U$106.P$2 (C12)
CSBI: U$107.5 (A3); also elsewhere on the board
GND: U$107.2 (GND1), U$107.8 (GND2); also elsewhere on the board
GND8: C120.1, C121.1, C122.1, C123.1, C124.1, C125.1, C126.1, C127.1, C128.1, C129.1, C130.1, C131.1, C132.1, C133.1, C134.1, C135.1, C136.1, D118.A, R655.2, R661.1, U$106.27 (V-), U$106.28 (NC), U$106.33 (TOS), U$106.40 (A3), U$107.9 (GND4), U$107.15 (GND3)
unnamed: R584.1, U$108.1 (G)
unnamed: R582.2, R585.2, U$108.3 (D)
unnamed: D106.A, D107.C, D118.C, R582.1, R585.1, R587.2, R589.1, U$109.2 (S)
unnamed: R586.2, R664.1
unnamed: R590.1, U$109.1 (G)
unnamed: R588.2, R591.2, U$109.3 (D)
unnamed: R587.1, R592.2
unnamed: R596.1, U$110.1 (G)
unnamed: R594.2, R597.2, U$110.3 (D)
unnamed: D106.C, D108.A, R583.1, R594.1, R597.1, R664.2, U$108.2 (S)
unnamed: R593.1, R598.2
unnamed: R602.1, U$111.1 (G)
unnamed: R600.2, R603.2, U$111.3 (D)
unnamed: D108.C, D109.A, R593.2, R595.1, R600.1, R603.1, U$110.2 (S)
unnamed: R599.1, R604.2
unnamed: R608.1, U$112.1 (G)
unnamed: R606.2, R609.2, U$112.3 (D)
unnamed: D109.C, D110.A, R599.2, R601.1, R606.1, R609.1, U$111.2 (S)
unnamed: R605.1, R610.2
unnamed: R614.1, U$113.1 (G)
unnamed: R612.2, R615.2, U$113.3 (D)
unnamed: D110.C, D111.A, R605.2, R607.1, R612.1, R615.1, U$112.2 (S)
unnamed: R611.1, R616.2
unnamed: R620.1, U$114.1 (G)
unnamed: R618.2, R621.2, U$114.3 (D)
unnamed: D112.A, D113.C, R618.1, R621.1, R623.2, R625.1, U$115.2 (S)
unnamed: R617.1, R622.2
unnamed: R626.1, U$115.1 (G)
unnamed: R624.2, R627.2, U$115.3 (D)
unnamed: D111.C, D113.A, R611.2, R613.1, R624.1, R627.1, U$113.2 (S)
unnamed: R623.1, R628.2
unnamed: R632.1, U$116.1 (G)
unnamed: R630.2, R633.2, U$116.3 (D)
unnamed: D112.C, D114.A, R617.2, R619.1, R630.1, R633.1, U$114.2 (S)
unnamed: R629.1, R634.2
unnamed: R638.1, U$117.1 (G)
unnamed: R636.2, R639.2, U$117.3 (D)
unnamed: D114.C, D115.A, R629.2, R631.1, R636.1, R639.1, U$116.2 (S)
unnamed: R635.1, R640.2
unnamed: R644.1, U$118.1 (G)
unnamed: R642.2, R645.2, U$118.3 (D)
unnamed: D115.C, D116.A, R635.2, R637.1, R642.1, R645.1, U$117.2 (S)
unnamed: R641.1, R646.2
unnamed: D117.C, R647.2, R649.1, U$119.2 (S)
unnamed: R650.1, U$119.1 (G)
unnamed: R648.2, R651.2, U$119.3 (D)
unnamed: D116.C, D117.A, D119.A, R641.2, R643.1, R648.1, R651.1, U$118.2 (S)
unnamed: R647.1, R652.2
unnamed: R653.1, R654.2
unnamed: R654.1, R656.1, U$120.1
unnamed: D107.A, R588.1, R591.1, R653.2
unnamed: R655.1, R656.2
unnamed: R657.1, R658.2
unnamed: D119.C, R657.2, R659.1, R660.1
unnamed: C134.2, R661.2, U$106.26 (CO)
unnamed: C135.2, U$106.31 (VREFF)
unnamed: C136.2, R662.1, R663.1, U$106.32 (VREG), U$106.37 (A0), U$106.38 (A1), U$106.39 (A2), U$107.10 (EN2), U$107.16 (VDD2)
unnamed: R662.2, U$106.34 (WDTB)
unnamed: R663.2, U$106.43 (SDO), U$107.11 (B4)
unnamed: U$106.44 (CSBI), U$107.12 (B3)
unnamed: U$106.42 (SDI), U$107.13 (B2)
unnamed: U$106.41 (SCKI), U$107.14 (B1)
unnamed: D120.C, U$107.6 (A4)
S1-8: R590.2, U$106.25 (S1)
S2-8: R584.2, U$106.23 (S2)
S3-8: R596.2, U$106.P$21 (S3)
S4-8: R602.2, U$106.P$19 (S4)
S5-8: R608.2, U$106.P$17 (S5)
S6-8: R614.2, U$106.P$15 (S6)
S7-8: R626.2, U$106.P$13 (S7)
S8-8: R620.2, U$106.P$11 (S8)
S9-8: R632.2, U$106.P$9 (S9)
S10-8: R638.2, U$106.P$7 (S10)
S11-8: R644.2, U$106.P$5 (S11)
S12-8: R650.2, U$106.P$3 (S12)
SCK: U$107.3 (A1); also elsewhere on the board
SDI: U$107.4 (A2); also elsewhere on the board
SDO: D120.A; also elsewhere on the board
V1+8: C132.2, C133.2, R659.2, R660.2, U$106.P$1 (V+)
VDD: U$107.1 (VDD1), U$107.7 (EN1); also elsewhere on the board

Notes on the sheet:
Module 8 [87]

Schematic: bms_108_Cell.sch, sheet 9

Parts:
C137, C138, C139, C140, C141, C142, C143, C144, C145, C146, C147, C148, C149, C150, C151, C152, C153: 100nF; C0805K
D121, D122, D123, D124, D125, D126, D127, D128, D129, D130, D131, D132, D133, D134: 7Z5; SMB
D135: DIODE-SOD123; SOD123
R665, R668, R671, R674, R677, R680, R683, R686, R689, R692, R695, R698, R701, R704, R707, R710, R713, R716, R719, R722, R725, R728, R731, R734: 470; R6332
R666, R672, R678, R684, R690, R696, R702, R708, R714, R720, R726, R732, R742, R743, R744, R745, R746: 221; R0805
R667, R673, R679, R685, R691, R697, R703, R709, R715, R721, R727, R733: 222; R0805
R669, R670, R675, R676, R681, R682, R687, R688, R693, R694, R699, R700, R705, R706, R711, R712, R717, R718, R723, R724, R729, R730, R735, R736, R737, R738, R739, R740, R741, R747: 0R; M1206
U$121: LTC6803-4; SSOP44
U$122: SI8841; SO16
U$123, U$124, U$125, U$126, U$127, U$128, U$129, U$130, U$131, U$132, U$133, U$134: SI2351DS; SOT23
U$135: INDUCTOR; L2012C

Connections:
28-3: U$135.2; also elsewhere on the board
29-3: R675.1; also elsewhere on the board
30-3: R669.1; also elsewhere on the board
31-3: R681.1; also elsewhere on the board
32-3: R687.1; also elsewhere on the board
33-3: R693.1; also elsewhere on the board
34-3: R699.1; also elsewhere on the board
35-3: R711.1; also elsewhere on the board
36-3: R705.1; also elsewhere on the board
37-3: R717.1; also elsewhere on the board
38-3: R723.1; also elsewhere on the board
39-3: R729.1; also elsewhere on the board
40-3: R735.1, R741.1; also elsewhere on the board
C1-9: C138.2, R672.2, U$121.24 (C1)
C2-9: C137.2, R666.2, U$121.P$22 (C2)
C3-9: C139.2, R678.2, U$121.P$20 (C3)
C4-9: C140.2, R684.2, U$121.P$18 (C4)
C5-9: C141.2, R690.2, U$121.P$16 (C5)
C6-9: C142.2, R696.2, U$121.P$14 (C6)
C7-9: C144.2, R708.2, U$121.P$12 (C7)
C8-9: C143.2, R702.2, U$121.P$10 (C8)
C9-9: C145.2, R714.2, U$121.P$8 (C9)
C10-9: C146.2, R720.2, U$121.P$6 (C10)
C11-9: C147.2, R726.2, U$121.P$4 (C11)
C12-9: C148.2, R732.2, U$121.P$2 (C12)
CSBI: U$122.5 (A3); also elsewhere on the board
GND: U$122.2 (GND1), U$122.8 (GND2); also elsewhere on the board
GND9: C137.1, C138.1, C139.1, C140.1, C141.1, C142.1, C143.1, C144.1, C145.1, C146.1, C147.1, C148.1, C149.1, C150.1, C151.1, C152.1, C153.1, D133.A, R738.2, R744.1, U$121.27 (V-), U$121.28 (NC), U$121.33 (TOS), U$121.37 (A0), U$121.38 (A1), U$121.39 (A2), U$122.9 (GND4), U$122.15 (GND3)
unnamed: R667.1, U$123.1 (G)
unnamed: R665.2, R668.2, U$123.3 (D)
unnamed: D121.A, D122.C, D133.C, R665.1, R668.1, R670.2, R672.1, U$124.2 (S)
unnamed: R669.2, R747.1
unnamed: R673.1, U$124.1 (G)
unnamed: R671.2, R674.2, U$124.3 (D)
unnamed: R670.1, R675.2
unnamed: R679.1, U$125.1 (G)
unnamed: R677.2, R680.2, U$125.3 (D)
unnamed: D121.C, D123.A, R666.1, R677.1, R680.1, R747.2, U$123.2 (S)
unnamed: R676.1, R681.2
unnamed: R685.1, U$126.1 (G)
unnamed: R683.2, R686.2, U$126.3 (D)
unnamed: D123.C, D124.A, R676.2, R678.1, R683.1, R686.1, U$125.2 (S)
unnamed: R682.1, R687.2
unnamed: R691.1, U$127.1 (G)
unnamed: R689.2, R692.2, U$127.3 (D)
unnamed: D124.C, D125.A, R682.2, R684.1, R689.1, R692.1, U$126.2 (S)
unnamed: R688.1, R693.2
unnamed: R697.1, U$128.1 (G)
unnamed: R695.2, R698.2, U$128.3 (D)
unnamed: D125.C, D126.A, R688.2, R690.1, R695.1, R698.1, U$127.2 (S)
unnamed: R694.1, R699.2
unnamed: R703.1, U$129.1 (G)
unnamed: R701.2, R704.2, U$129.3 (D)
unnamed: D127.A, D128.C, R701.1, R704.1, R706.2, R708.1, U$130.2 (S)
unnamed: R700.1, R705.2
unnamed: R709.1, U$130.1 (G)
unnamed: R707.2, R710.2, U$130.3 (D)
unnamed: D126.C, D128.A, R694.2, R696.1, R707.1, R710.1, U$128.2 (S)
unnamed: R706.1, R711.2
unnamed: R715.1, U$131.1 (G)
unnamed: R713.2, R716.2, U$131.3 (D)
unnamed: D127.C, D129.A, R700.2, R702.1, R713.1, R716.1, U$129.2 (S)
unnamed: R712.1, R717.2
unnamed: R721.1, U$132.1 (G)
unnamed: R719.2, R722.2, U$132.3 (D)
unnamed: D129.C, D130.A, R712.2, R714.1, R719.1, R722.1, U$131.2 (S)
unnamed: R718.1, R723.2
unnamed: R727.1, U$133.1 (G)
unnamed: R725.2, R728.2, U$133.3 (D)
unnamed: D130.C, D131.A, R718.2, R720.1, R725.1, R728.1, U$132.2 (S)
unnamed: R724.1, R729.2
unnamed: D132.C, R730.2, R732.1, U$134.2 (S)
unnamed: R733.1, U$134.1 (G)
unnamed: R731.2, R734.2, U$134.3 (D)
unnamed: D131.C, D132.A, D134.A, R724.2, R726.1, R731.1, R734.1, U$133.2 (S)
unnamed: R730.1, R735.2
unnamed: R736.1, R737.2
unnamed: R737.1, R739.1, U$135.1
unnamed: D122.A, R671.1, R674.1, R736.2
unnamed: R738.1, R739.2
unnamed: R740.1, R741.2
unnamed: D134.C, R740.2, R742.1, R743.1
unnamed: C151.2, R744.2, U$121.26 (CO)
unnamed: C152.2, U$121.31 (VREFF)
unnamed: C153.2, R745.1, R746.1, U$121.32 (VREG), U$121.40 (A3), U$122.10 (EN2), U$122.16 (VDD2)
unnamed: R745.2, U$121.34 (WDTB)
unnamed: R746.2, U$121.43 (SDO), U$122.11 (B4)
unnamed: U$121.44 (CSBI), U$122.12 (B3)
unnamed: U$121.42 (SDI), U$122.13 (B2)
unnamed: U$121.41 (SCKI), U$122.14 (B1)
unnamed: D135.C, U$122.6 (A4)
S1-9: R673.2, U$121.25 (S1)
S2-9: R667.2, U$121.23 (S2)
S3-9: R679.2, U$121.P$21 (S3)
S4-9: R685.2, U$121.P$19 (S4)
S5-9: R691.2, U$121.P$17 (S5)
S6-9: R697.2, U$121.P$15 (S6)
S7-9: R709.2, U$121.P$13 (S7)
S8-9: R703.2, U$121.P$11 (S8)
S9-9: R715.2, U$121.P$9 (S9)
S10-9: R721.2, U$121.P$7 (S10)
S11-9: R727.2, U$121.P$5 (S11)
S12-9: R733.2, U$121.P$3 (S12)
SCK: U$122.3 (A1); also elsewhere on the board
SDI: U$122.4 (A2); also elsewhere on the board
SDO: D135.A; also elsewhere on the board
V1+9: C149.2, C150.2, R742.2, R743.2, U$121.P$1 (V+)
VDD: U$122.1 (VDD1), U$122.7 (EN1); also elsewhere on the board

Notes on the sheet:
Module 9 [88]

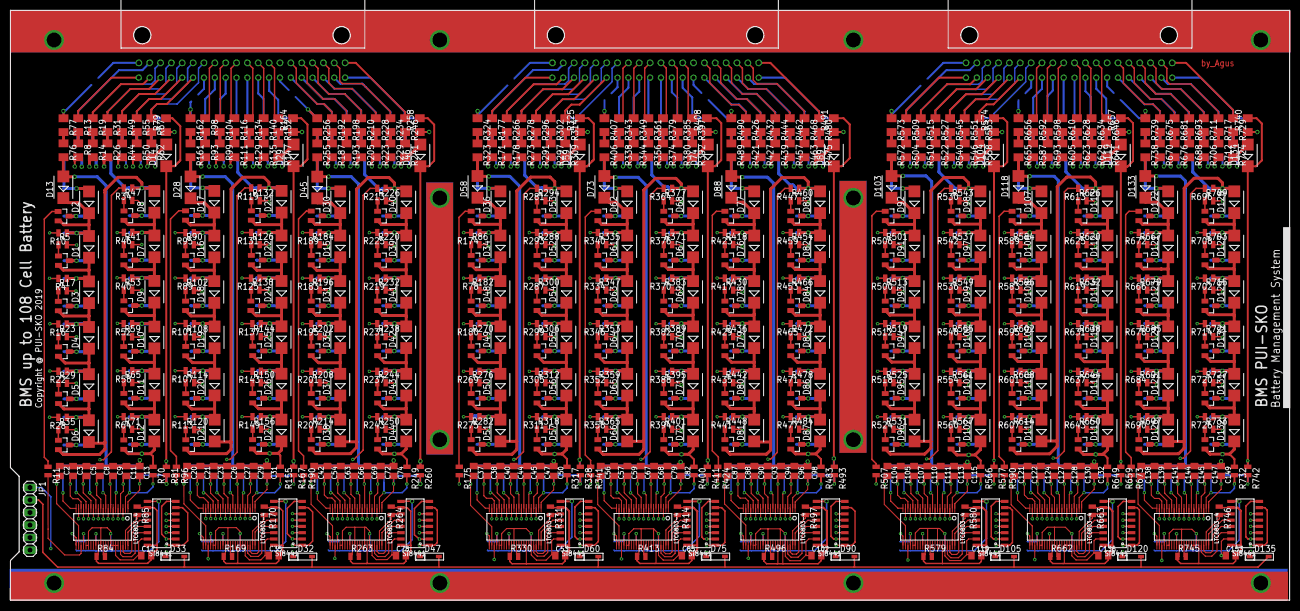
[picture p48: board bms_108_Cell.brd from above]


Board: 2 copper layers, 259.2 x 119.5 mm, 1174 parts (459 on the bottom side), 924 nets.

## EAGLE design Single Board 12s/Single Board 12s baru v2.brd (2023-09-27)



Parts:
C_5VHOST1, C_5VHOST2: 100n, 1206; C1206
C_C0: 100n, 1206; C1206
C_CIN1, C_CIN2, C_CIN3, C_CIN4, C_CIN5, C_CIN6, C_CIN7, C_CIN8, C_CIN9, C_CIN10, C_CIN11, C_CIN12: 100n, 1206; C1206
C_COUPLINGA: 1u, 1206; C1206
C_V+1, C_V+2: 100n, 1206; C1206
C_V+LTC: 100n, 1206; C1206
C_VDDHV1, C_VDDHV2: 100n, 1206; C1206
C_VREF: 1u, 1206; C1206
C_VREG: 1u, 1206; C1206
C_VTEMP1, C_VTEMP2: 1u, 1206; C1206
D1_V+, D2_V+: SCHOTTKY BARRIER RECTIFIER; DO27-15
F0, F1, F2, F3, F4, F5, F6, F7, F8, F9, F10, F11, F12, F13: 500mA, 1206; 1206
GPIO1, GPIO2: PINHD-1X3; 1X03
ISODCDC: W237-02P; W237-132
LED1, LED2, LED3, LED4, LED5, LED6, LED7, LED8, LED9, LED10, LED11, LED12: 0805; SML0805
LED_VDDHOST: 0805; SML0805
LED_VDDHV: 0805; SML0805
NTC1, NTC2: W237-02P; W237-132
PMOS1, PMOS2, PMOS3, PMOS4, PMOS5, PMOS6, PMOS7, PMOS8, PMOS9, PMOS10, PMOS11, PMOS12: SI2301; SOT23-3
RD1, RD2, RD3, RD4, RD5, RD6, RD7, RD8, RD9, RD10, RD11, RD12: 47, 2512; R2512
RLED1, RLED2, RLED3, RLED4, RLED5, RLED6, RLED7, RLED8, RLED9, RLED10, RLED11, RLED12: 470, 1206; R1206
R_A1, R_A2, R_A3, R_A4: 100R, 1206; R1206
R_B1., R_B2., R_B3., R_B4.: 4k7, 1206; R1206
R_C0: 220, 1206; R1206
R_CIN0, R_CIN1, R_CIN2, R_CIN3, R_CIN4, R_CIN5, R_CIN6, R_CIN7, R_CIN8, R_CIN9, R_CIN10, R_CIN11, R_CIN12: 100, 1206; R1206
R_GPIO1, R_GPIO2: 220, 1206; R1206
R_SGATE1, R_SGATE2, R_SGATE3, R_SGATE4, R_SGATE5, R_SGATE6, R_SGATE7, R_SGATE8, R_SGATE9, R_SGATE10, R_SGATE11, R_SGATE12: 3.3k, 1206; R1206
R_V+: 100, 1206; R1206
R_VDDHOST: 470, 1206; R1206
R_VDDHV: 470, 1206; R1206
R_VDD_VREG: 1k, 1206; R1206
R_VTEMP1, R_VTEMP2: 10K, 1206; R1206
R_WDTB: 220, 1206; R1206
SCHOTTKY_V+: SS100, 100V, SMA/DO-214AC; SMADIODE
SPI: PINHD-1X6; 1X06
U1: SI8441BB-D-IS; SOIC-16W_SIL
U2: LINEAR_TECHNOLOGY_LTC6803HG-4#PBFLINEAR_TECHNOLOG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; LINEAR_TECHNOLOGY_LTC6803HG-4#PBF_2
V+_LTC: PINHD-1X3; 1X03
X1, X2: W237-07P; W237-7P
ZEN1, ZEN2, ZEN3, ZEN4, ZEN5, ZEN6, ZEN7, ZEN8, ZEN9, ZEN10, ZEN11, ZEN12: Zener 5.1V, LL34; LL-34
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

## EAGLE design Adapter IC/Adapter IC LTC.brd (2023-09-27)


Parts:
JP1, JP2: PINHD-1X22; 1X22
LTC: LTC6803IG-3#PBF; SOP50P780X185-44N

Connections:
unnamed: JP2.22, LTC.1 (CSBO)
unnamed: JP2.21, LTC.2 (SDOI)
unnamed: JP2.20, LTC.3 (SCKO)
unnamed: JP2.19, LTC.4 (V+)
unnamed: JP2.18, LTC.5 (C12)
unnamed: JP2.17, LTC.6 (S12)
unnamed: JP2.16, LTC.7 (C11)
unnamed: JP2.15, LTC.8 (S11)
unnamed: JP2.14, LTC.9 (C10)
unnamed: JP2.13, LTC.10 (S10)
unnamed: JP2.12, LTC.11 (C9)
unnamed: JP2.11, LTC.12 (S9)
unnamed: JP2.10, LTC.13 (C8)
unnamed: JP2.9, LTC.14 (S8)
unnamed: JP2.8, LTC.15 (C7)
unnamed: JP2.7, LTC.16 (S7)
unnamed: JP2.6, LTC.17 (C6)
unnamed: JP2.5, LTC.18 (S6)
unnamed: JP2.4, LTC.19 (C5)
unnamed: JP2.3, LTC.20 (S5)
unnamed: JP2.2, LTC.21 (C4)
unnamed: JP2.1, LTC.22 (S4)
unnamed: JP1.22, LTC.23 (C3)
unnamed: JP1.21, LTC.24 (S3)
unnamed: JP1.20, LTC.25 (C2)
unnamed: JP1.19, LTC.26 (S2)
unnamed: JP1.18, LTC.27 (C1)
unnamed: JP1.17, LTC.28 (S1)
unnamed: JP1.16, LTC.29 (C0)
unnamed: JP1.15, LTC.30 (V-)
unnamed: JP1.14, LTC.31 (NC)
unnamed: JP1.13, LTC.32 (VTEMP1)
unnamed: JP1.12, LTC.33 (VTEMP2)
unnamed: JP1.11, LTC.34 (VREF)
unnamed: JP1.10, LTC.35 (VREG)
unnamed: JP1.9, LTC.36 (TOS)
unnamed: JP1.7, LTC.38 (GPIO1)
unnamed: JP1.8, LTC.37 (WDTB)
unnamed: JP1.6, LTC.39 (GPIO2)
unnamed: JP1.5, LTC.40 (VMODE)
unnamed: JP1.4, LTC.41 (SCKI)
unnamed: JP1.3, LTC.42 (SDI)
unnamed: JP1.2, LTC.43 (SDO)
unnamed: JP1.1, LTC.44 (CSBI)


Board: 2 copper layers, 59.7 x 29.6 mm, 3 parts (0 on the bottom side), 44 nets.

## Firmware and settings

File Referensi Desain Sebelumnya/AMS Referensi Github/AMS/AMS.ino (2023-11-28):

#include <mcp_can.h>
#include <mcp_can_dfs.h>

#include <Arduino.h>
#include <stdint.h>
#include "Linduino.h"
#include "LT_SPI.h"
#include "UserInterface.h"
#include "LTC6811_daisy.h"
#include <SPI.h>
#include <avr/wdt.h>

#define ENABLED 1
#define DISABLED 0

#define DATALOG_ENABLED 1
#define DATALOG_DISABLED 0

/**********************************************************
  Setup Variables
  The following variables can be modified to
  configure the software.

***********************************************************/
const uint8_t TOTAL_IC = 3;//!<number of ICs in the daisy chain

//ADC Command Configurations
const uint8_t ADC_OPT = ADC_OPT_DISABLED; // See ltc6811_daisy.h for Options
const uint8_t ADC_CONVERSION_MODE = MD_7KHZ_3KHZ; //MD_26HZ_2KHZ;//MD_7KHZ_3KHZ; // See ltc6811_daisy.h for Options
const uint8_t ADC_DCP = DCP_DISABLED; // See ltc6811_daisy.h for Options
const uint8_t CELL_CH_TO_CONVERT = CELL_CH_ALL; // See ltc6811_daisy.h for Options
const uint8_t AUX_CH_TO_CONVERT = AUX_CH_ALL; // See ltc6811_daisy.h for Options
const uint8_t STAT_CH_TO_CONVERT = STAT_CH_ALL; // See ltc6811_daisy.h for Options

const uint16_t MEASUREMENT_LOOP_TIME = 500;//milliseconds(mS)

//Under Voltage and Over Voltage Thresholds
const uint16_t OV_THRESHOLD = 27000; // Over voltage threshold ADC Code. LSB = 0.0001
const uint16_t UV_THRESHOLD = 10000; // Under voltage threshold ADC Code. LSB = 0.0001

//Loop Measurement Setup These Variables are ENABLED or DISABLED Remember ALL CAPS
const uint8_t WRITE_CONFIG = DISABLED; // This is ENABLED or DISABLED
const uint8_t READ_CONFIG = DISABLED; // This is ENABLED or DISABLED
const uint8_t MEASURE_CELL = ENABLED; // This is ENABLED or DISABLED
const uint8_t MEASURE_AUX = DISABLED; // This is ENABLED or DISABLED
const uint8_t MEASURE_STAT = DISABLED; //This is ENABLED or DISABLED

/************************************
  END SETUP
*************************************/

/******************************************************
 *** Global Battery Variables received from 681x commands
 These variables store the results from the ltc6811
 register reads and the array lengths must be based
 on the number of ICs on the stack
 ******************************************************/
uint16_t cell_codes[TOTAL_IC][CELL_CHANNELS];
/*!<
  The cell codes will be stored in the cell_codes[][12] array in the following format:

  |  cell_codes[0][0]| cell_codes[0][1] |  cell_codes[0][2]|    .....     |  cell_codes[0][11]|  cell_codes[1][0] | cell_codes[1][1]|  .....   |
  |------------------|------------------|------------------|--------------|-------------------|-------------------|-----------------|----------|
  |IC1 Cell 1        |IC1 Cell 2        |IC1 Cell 3        |    .....     |  IC1 Cell 12      |IC2 Cell 1         |IC2 Cell 2       | .....    |
****/

uint16_t aux_codes[TOTAL_IC][AUX_CHANNELS];
/*!<
 The GPIO codes will be stored in the aux_codes[][6] array in the following format:

 |  aux_codes[0][0]| aux_codes[0][1] |  aux_codes[0][2]|  aux_codes[0][3]|  aux_codes[0][4]|  aux_codes[0][5]| aux_codes[1][0] |aux_codes[1][1]|  .....    |
 |-----------------|-----------------|-----------------|-----------------|-----------------|-----------------|-----------------|---------------|-----------|
 |IC1 GPIO1        |IC1 GPIO2        |IC1 GPIO3        |IC1 GPIO4        |IC1 GPIO5        |IC1 Vref2        |IC2 GPIO1        |IC2 GPIO2      |  .....    |
*/

uint16_t stat_codes[TOTAL_IC][4];
/*!<
 The GPIO codes will be stored in the aux_codes[][6] array in the following format:

 |  aux_codes[0][0]| aux_codes[0][1] |  aux_codes[0][2]|  aux_codes[0][3]|  aux_codes[0][4]|  aux_codes[0][5]| aux_codes[1][0] |aux_codes[1][1]|  .....    |
 |-----------------|-----------------|-----------------|-----------------|-----------------|-----------------|-----------------|---------------|-----------|
 |IC1 GPIO1        |IC1 GPIO2        |IC1 GPIO3        |IC1 GPIO4        |IC1 GPIO5        |IC1 Vref2        |IC2 GPIO1        |IC2 GPIO2      |  .....    |
*/

uint8_t flags_uvov[TOTAL_IC][3];

uint8_t system_thsd[TOTAL_IC][1];

uint8_t system_muxfail[TOTAL_IC][1];

long system_open_wire[TOTAL_IC];

uint8_t tx_cfg[TOTAL_IC][6];
/*!<
  The tx_cfg[][6] stores the ltc6811 configuration data that is going to be written
  to the ltc6811 ICs on the daisy chain. The ltc6811 configuration data that will be
  written should be stored in blocks of 6 bytes. The array should have the following format:

 |  tx_cfg[0][0]| tx_cfg[0][1] |  tx_cfg[0][2]|  tx_cfg[0][3]|  tx_cfg[0][4]|  tx_cfg[0][5]| tx_cfg[1][0] |  tx_cfg[1][1]|  tx_cfg[1][2]|  .....    |
 |--------------|--------------|--------------|--------------|--------------|--------------|--------------|--------------|--------------|-----------|
 |IC1 CFGR0     |IC1 CFGR1     |IC1 CFGR2     |IC1 CFGR3     |IC1 CFGR4     |IC1 CFGR5     |IC2 CFGR0     |IC2 CFGR1     | IC2 CFGR2    |  .....    |

*/

uint8_t rx_cfg[TOTAL_IC][8];
/*!<
  the rx_cfg[][8] array stores the data that is read back from a ltc6811-1 daisy chain.
  The configuration data for each IC  is stored in blocks of 8 bytes. Below is an table illustrating the array organization:

|rx_config[0][0]|rx_config[0][1]|rx_config[0][2]|rx_config[0][3]|rx_config[0][4]|rx_config[0][5]|rx_config[0][6]  |rx_config[0][7] |rx_config[1][0]|rx_config[1][1]|  .....    |
|---------------|---------------|---------------|---------------|---------------|---------------|-----------------|----------------|---------------|---------------|-----------|
|IC1 CFGR0      |IC1 CFGR1      |IC1 CFGR2      |IC1 CFGR3      |IC1 CFGR4      |IC1 CFGR5      |IC1 PEC High     |IC1 PEC Low     |IC2 CFGR0      |IC2 CFGR1      |  .....    |
*/

#define SPI_CS_PIN 10
#define MOSFET_STATUS_PIN 7

#define KELLY_KDHE_SEND_CAN_ID 0x6B
#define KELLY_KDHE_RESPONSE_CAN_ID 0x73
#define AMS_CAN_ID 0x69
#define CCP_A2D_BATCH_READ1 0x1b

MCP_CAN CAN(SPI_CS_PIN);

// Precharge 10 seconds TODO

/*!**********************************************************************
 \brief  Inititializes hardware and variables
 ***********************************************************************/
void setup()
{
  delay(5000);
  Serial.begin(115200);
//  quikeval_SPI_connect();
  spi_enable(SPI_CLOCK_DIV16); // This will set the Linduino to have a 1MHz Clock

  init_cfg();        //initialize the 681x configuration array to be written
  pinMode(MOSFET_STATUS_PIN, OUTPUT);
  digitalWrite(MOSFET_STATUS_PIN, HIGH);
//  pinMode(9,OUTPUT);
//  digitalWrite(9,HIGH);

  for(;;)     //infinite loop
  {
    // Initialize MCP2515 running at 16MHz with a baudrate of 500kb/s
    if (CAN.begin(MCP_ANY, CAN_500KBPS, MCP_16MHZ) == CAN_OK)
    {
      Serial.println("CAN BUS INIT GOOD");
      break;
    }
    else
    {
      Serial.println("CAN BUS INIT FAIL, RETRY");
      delay(100);
    }
  }

  Serial.println("Starting the precharge!");
  // CCP_A2D_BATCH_READ1 is what we are checking
  
  bool preCharging = true;
  unsigned char preChargeSendMsg[1] = { CCP_A2D_BATCH_READ1 };
  unsigned char preChargeRcvMsg[5];
  unsigned char len = 0;
  int8_t error = 0;
  
  while (preCharging)
  {

    CAN.sendMsgBuf(KELLY_KDHE_SEND_CAN_ID, 0, 1, preChargeSendMsg);
    
    // We may need a delay here
    
    if (CAN_MSGAVAIL == CAN.checkReceive())
    {
      CAN.readMsgBuf(AMS_CAN_ID, &len, 5, preChargeRcvMsg);
      unsigned long canID = 0x100;  
      if(canID == KELLY_KDHE_RESPONSE_CAN_ID)
      {
        float kellyVoltage = (float) preChargeRcvMsg[4]/1.39;
        Serial.print("Float voltage is: ");
        Serial.print(preChargeRcvMsg[4]);
        Serial.print(" | ");
        Serial.println(kellyVoltage);
        
        ltc6811_adcv(ADC_CONVERSION_MODE,ADC_DCP,CELL_CH_TO_CONVERT);
        ltc6811_pollAdc();
        wakeup_idle();
        error = ltc6811_rdcv(0, TOTAL_IC,cell_codes);
        check_error(error);

        float total = 0.00;
        for (int current_ic = 0 ; current_ic < TOTAL_IC; current_ic++)
        {
          for (int i=0; i<CELL_CHANNELS; i++)
          {
            total = total + (cell_codes[current_ic][i]*0.0001);
          }
        }

        Serial.print("Measured Pack Voltage is ");
        Serial.println(total);

        float thresholdVoltage = total*(.90);

        if (kellyVoltage >= thresholdVoltage)
        {
          Serial.println("Yeoooow greater");
          preCharging = false;
          break;
        }
      }
    }
    delay(MEASUREMENT_LOOP_TIME);
  }

  
}


void loop() {
    unsigned char len = 0;
    unsigned char buf[8];
    int8_t error = 0;
    wakeup_sleep();
    ltc6811_wrcfg(TOTAL_IC,tx_cfg);

    // Check if we got a CAN message for charging
    if (CAN_MSGAVAIL == CAN.checkReceive())
    {
       CAN.readMsgBuf(KELLY_KDHE_RESPONSE_CAN_ID, &len, 8, buf);

       unsigned char canId = AMS_CAN_ID;

       if (canId == AMS_CAN_ID)
       {
        // TODO If we get a charge signal
       }
    }

    ltc6811_adcv(ADC_CONVERSION_MODE,ADC_DCP,CELL_CH_TO_CONVERT);
    ltc6811_pollAdc();
    wakeup_idle();
    error = ltc6811_rdcv(0, TOTAL_IC,cell_codes);
    check_error(error);

    float total = 0.00;
    for (int current_ic = 0 ; current_ic < TOTAL_IC; current_ic++)
    {
      Serial.print("Cells, ");
      for (int i=0; i<CELL_CHANNELS; i++)
      {
        if (cell_codes[current_ic][i]*0.0001 < 1)
        {
          digitalWrite(MOSFET_STATUS_PIN, LOW);
          Serial.print("UNDER VOLTAGE FOR CELL: ");
          Serial.print(current_ic);
          Serial.print(" | ");
          Serial.println(i);
        }
        Serial.print(cell_codes[current_ic][i]*0.0001,4);
        total = total + (cell_codes[current_ic][i]*0.0001);
        Serial.print(",");
      }
    }

    


    delay(MEASUREMENT_LOOP_TIME);
      
//        measurement_loop(DATALOG_DISABLED);
}

void measurement_loop(uint8_t datalog_en)
{
  int8_t error = 0;
  if (WRITE_CONFIG == ENABLED)
  {
    wakeup_sleep();
    ltc6811_wrcfg(TOTAL_IC,tx_cfg);
    print_config();
  }

  if (READ_CONFIG == ENABLED)
  {
    wakeup_sleep();
    error = ltc6811_rdcfg(TOTAL_IC,rx_cfg);
    check_error(error);
    print_rxconfig();
  }

  if (MEASURE_CELL == ENABLED)
  {

    ltc6811_adcv(ADC_CONVERSION_MODE,ADC_DCP,CELL_CH_TO_CONVERT);
    ltc6811_pollAdc();
    wakeup_idle();
    error = ltc6811_rdcv(0, TOTAL_IC,cell_codes);
    check_error(error);
    print_cells(datalog_en);

  }

  if (MEASURE_AUX == ENABLED)
  {
    wakeup_idle();
    ltc6811_adax(ADC_CONVERSION_MODE , AUX_CH_ALL);
    ltc6811_pollAdc();
    wakeup_idle();
    error = ltc6811_rdaux(0,TOTAL_IC,aux_codes); // Set to read back all aux registers
    check_error(error);
    print_aux(datalog_en);
  }

  if (MEASURE_STAT == ENABLED)
  {
    wakeup_idle();
    ltc6811_adstat(ADC_CONVERSION_MODE, STAT_CH_ALL);
    ltc6811_pollAdc();
    wakeup_idle();
    error = ltc6811_rdstat(0,TOTAL_IC,stat_codes,flags_uvov,system_muxfail,system_thsd); // Set to read back all aux registers
    check_error(error);
    print_stat();
  }
}

void init_cfg()
{
  uint16_t uv_val = (UV_THRESHOLD/16)-1;
  uint16_t ov_val = (OV_THRESHOLD/16);
  for (int i = 0; i<TOTAL_IC; i++)
  {
    tx_cfg[i][0] = 0xFC | ADC_OPT;
    tx_cfg[i][1] = (uint8_t)(uv_val&0xFF) ;
    tx_cfg[i][2] = (uint8_t)((ov_val&0x00F)|((uv_val&0xF00)>>8)) ;
    tx_cfg[i][3] = (uint8_t)((ov_val&0xFF0)>>4);
    tx_cfg[i][4] = 0x00 ;
    tx_cfg[i][5] = 0x00 ;

  }

}

void print_cells(uint8_t datalog_en)
{

  float total = 0.00;
  for (int current_ic = 0 ; current_ic < TOTAL_IC; current_ic++)
  {
    if (datalog_en == 0)
    {
      Serial.print(" IC ");
      Serial.print(current_ic+1,DEC);
      Serial.print(", ");
      for (int i=0; i<CELL_CHANNELS; i++)
      {

        Serial.print(" C");
        Serial.print(i+1,DEC);
        Serial.print(":");
        Serial.print(cell_codes[current_ic][i]*0.0001,4);
        total = total + (cell_codes[current_ic][i]*0.0001);
        Serial.print(",");
      }
      Serial.println();
    }
    else
    {
      Serial.print("Cells, ");
      for (int i=0; i<CELL_CHANNELS; i++)
      {
        Serial.print(cell_codes[current_ic][i]*0.0001,4);
        Serial.print(",");
      }

    }
  }
  Serial.println();
  Serial.print("Pack Voltage: ");
  Serial.print(total);
  Serial.println();
}

void print_config()
{
  int cfg_pec;

  Serial.println(F("Written Configuration: "));
  for (int current_ic = 0; current_ic<TOTAL_IC; current_ic++)
  {
    Serial.print(F(" IC "));
    Serial.print(current_ic+1,DEC);
    Serial.print(F(": "));
    Serial.print(F("0x"));
    serial_print_hex(tx_cfg[current_ic][0]);
    Serial.print(F(", 0x"));
    serial_print_hex(tx_cfg[current_ic][1]);
    Serial.print(F(", 0x"));
    serial_print_hex(tx_cfg[current_ic][2]);
    Serial.print(F(", 0x"));
    serial_print_hex(tx_cfg[current_ic][3]);
    Serial.print(F(", 0x"));
    serial_print_hex(tx_cfg[current_ic][4]);
    Serial.print(F(", 0x"));
    serial_print_hex(tx_cfg[current_ic][5]);
    Serial.print(F(", Calculated PEC: 0x"));
    cfg_pec = pec15_calc(6,&tx_cfg[current_ic][0]);
    serial_print_hex((uint8_t)(cfg_pec>>8));
    Serial.print(F(", 0x"));
    serial_print_hex((uint8_t)(cfg_pec));
    Serial.println();
  }
  Serial.println();
}

//Function to check error flag and print PEC error message
void check_error(int error)
{
  if (error == -1)
  {
    Serial.println(F("A PEC error was detected in the received data"));
  }
}

/*!*****************************************************************
 \brief Prints the configuration data that was read back from the
 ltc6811 to the serial port.
 *******************************************************************/
void print_rxconfig()
{
  Serial.println(F("Received Configuration "));
  for (int current_ic=0; current_ic<TOTAL_IC; current_ic++)
  {
    Serial.print(F(" IC "));
    Serial.print(current_ic+1,DEC);
    Serial.print(F(": 0x"));
    serial_print_hex(rx_cfg[current_ic][0]);
    Serial.print(F(", 0x"));
    serial_print_hex(rx_cfg[current_ic][1]);
    Serial.print(F(", 0x"));
    serial_print_hex(rx_cfg[current_ic][2]);
    Serial.print(F(", 0x"));
    serial_print_hex(rx_cfg[current_ic][3]);
    Serial.print(F(", 0x"));
    serial_print_hex(rx_cfg[current_ic][4]);
    Serial.print(F(", 0x"));
    serial_print_hex(rx_cfg[current_ic][5]);
    Serial.print(F(", Received PEC: 0x"));
    serial_print_hex(rx_cfg[current_ic][6]);
    Serial.print(F(", 0x"));
    serial_print_hex(rx_cfg[current_ic][7]);
    Serial.println();
  }
  Serial.println();
}


/*!****************************************************************************
  \brief Prints GPIO voltage codes and Vref2 voltage code onto the serial port
 *****************************************************************************/
void print_aux(uint8_t datalog_en)
{

  for (int current_ic =0 ; current_ic < TOTAL_IC; current_ic++)
  {
    if (datalog_en == 0)
    {
      Serial.print(" IC ");
      Serial.print(current_ic+1,DEC);
      for (int i=0; i < 5; i++)
      {
        Serial.print(F(" GPIO-"));
        Serial.print(i+1,DEC);
        Serial.print(":");
        Serial.print(aux_codes[current_ic][i]*0.0001,4);
        Serial.print(",");
      }
      Serial.print(F(" Vref2"));
      Serial.print(":");
      Serial.print(aux_codes[current_ic][5]*0.0001,4);
      Serial.println();
    }
    else
    {
      Serial.print("AUX, ");

      for (int i=0; i < 6; i++)
      {
        Serial.print(aux_codes[current_ic][i]*0.0001,4);
        Serial.print(",");
      }
    }
  }
  Serial.println();
}

/*!****************************************************************************
  \brief Prints Status voltage codes and Vref2 voltage code onto the serial port
 *****************************************************************************/
void print_stat()
{

  for (int current_ic =0 ; current_ic < TOTAL_IC; current_ic++)
  {
    Serial.print(F(" IC "));
    Serial.print(current_ic+1,DEC);
    Serial.print(F(" SOC:"));
    Serial.print(stat_codes[current_ic][0]*0.0001*20,4);
    Serial.print(F(","));
    Serial.print(F(" Itemp:"));
    Serial.print(stat_codes[current_ic][1]*0.0001,4);
    Serial.print(F(","));
    Serial.print(F(" VregA:"));
    Serial.print(stat_codes[current_ic][2]*0.0001,4);
    Serial.print(F(","));
    Serial.print(F(" VregD:"));
    Serial.print(stat_codes[current_ic][3]*0.0001,4);
    Serial.println();
  }

  Serial.println();
}

void serial_print_hex(uint8_t data)
{
  if (data< 16)
  {
    Serial.print("0");
    Serial.print((byte)data,HEX);
  }
  else
    Serial.print((byte)data,HEX);
}

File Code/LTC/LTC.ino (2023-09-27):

#include <LTC6803.h> // Including LTC library
ltc6803 ltc; //Create a new object of ltc6803 class called "ltc"

//Below constants are defined for testing - change them to match your setup
int chipSelect = 10;    //SPI chip select pin number - usually pin 10
float uv_limit = 1.0;   //Under voltage limit for these battery cells - lowest is -0.3 volts
float ov_limit = 1.9;   //Over voltage limit for these battery cells highest is 5 volts
int cellNumber = 12;    //Number of battery cells - maximum 12 cells


/////////////////////////////////////////////////////////////////////////////////////////////////////
/////////////////////////////////////////////////////////////////////////////////////////////////////
      
void setup()
{
  Serial.begin(115200); //For debugging
  ltc.begin(chipSelect, cellNumber, uv_limit, ov_limit);
  delay(500);
}

//-----------------------------------------------------------------------------------------------------//
//-----------------------------------------------------------------------------------------------------//

// The main code here, it will run repeatedly.
void loop()
{
  //Periodically reads the battery cells voltages and temperature values
  ltc.getData();
  float totalVoltage = 0.0;

  /////////////////////////////////////////////////////////////////////////////////////////////////////////
  // Printing the internal teperature value of the LCT IC
  Serial.print("-    IC Temp = ");
  Serial.print(ltc.IC_tmp);
  Serial.println(" degrees celsius   -");

  for(int z = 0; z < cellNumber; z++)
  {

    Serial.print("Cell ");
    Serial.print(z+1);

    Serial.print(" voltage: ");
    Serial.print(ltc.cell_voltages[z]);

    totalVoltage = totalVoltage + ltc.cell_voltages[z];
  
    Serial.print("v -- ");
    Serial.print("Flag: ");
    Serial.println(ltc.flag_cell[z]);
  }
  
  Serial.print("Total voltage = ");
  Serial.println(totalVoltage);

  Serial.print("Temperature A: ");
  Serial.println(ltc.tmp_cell[0]);
  Serial.print("Temperature B: ");
  Serial.println(ltc.tmp_cell[1]);
  Serial.println();

delay(1000);

}

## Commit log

2023-11-28 add Voltage Regulator Simulation
2023-11-28 add Previous Design as Reference
    [Harga.xlsx, bms_108_Cell.brd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]

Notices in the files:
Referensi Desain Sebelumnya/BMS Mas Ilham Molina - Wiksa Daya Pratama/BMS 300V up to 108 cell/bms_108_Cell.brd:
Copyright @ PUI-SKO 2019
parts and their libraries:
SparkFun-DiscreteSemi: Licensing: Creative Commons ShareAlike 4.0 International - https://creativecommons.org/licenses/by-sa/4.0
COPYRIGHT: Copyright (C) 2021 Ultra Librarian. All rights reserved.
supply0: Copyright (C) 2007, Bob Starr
